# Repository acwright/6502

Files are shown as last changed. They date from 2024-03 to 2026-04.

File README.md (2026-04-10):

ac6502
======

## A 65C02 Based 8-Bit Retro Computer Project

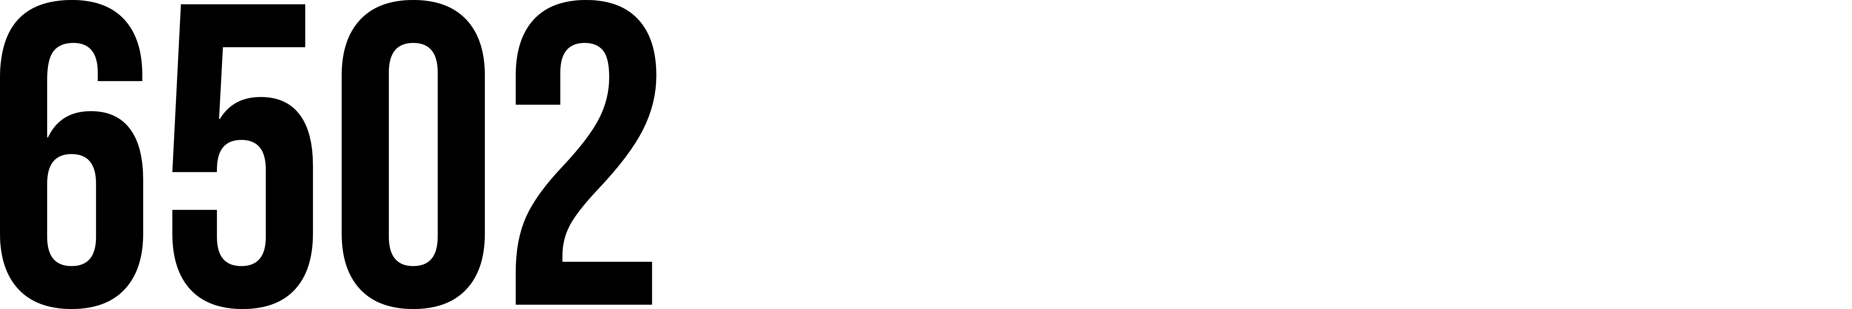
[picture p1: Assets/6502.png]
The ac6502 Project

*Shown above is "The VCS" from the ac6502 project. (AI used to clean up photo background. Computer, keyboard, monitor, and OS screenshot are very real!)*

---

## Table of Contents

- [Overview](#overview)
- [Target Audience](#target-audience)
- [Design Philosophy](#design-philosophy)
- [Computer Systems](#computer-systems)
  - [The COB (Computer on a Backplane)](#the-cob-computer-on-a-backplane)
  - [The DEV (Development Environment Vehicle)](#the-dev-development-environment-vehicle)
  - [The VCS (Video Computer System)](#the-vcs-video-computer-system)
- [System Specifications](#system-specifications)
- [Board Compatibility Matrix](#board-compatibility-matrix)
- [Architecture Overview](#architecture-overview)
- [Hardware](#hardware)
  - [Boards](#boards)
  - [Cards](#cards)
  - [Helpers](#helpers)
  - [Carts](#carts)
- [Firmware](#firmware)
- [Software & Related Projects](#software--related-projects)
- [CAD](#cad)
- [Production](#production)
- [Schematics](#schematics)
- [Libraries](#libraries)
- [Development Workflow](#development-workflow)
- [Contributing](#contributing)
- [Licensing](#licensing)

---

## Overview

This project aims to create multiple retro-style 8-bit computers based on the 65C02 microprocessor. The project is centered around a number of custom-designed PCBs that can be combined in various configurations to create different computer systems based on a common [memory map](./Assets/Documents/Memory%20Map/Memory%20Map.pdf). The designs are inspired by classic 8-bit computers such as the KIM-1, Commodore 64, and Apple II, but with modern enhancements and flexibility.

The project is designed using **KiCad 7.0+** for PCB design and is **open-source** under the CERN Open Hardware Licence Version 2 - Permissive, allowing enthusiasts to contribute and modify the designs freely. The boards are manufactured by **JLCPCB** and use a combination of surface-mount and through-hole components for optimal assembly flexibility.

### Key Features

- **Modular Design**: Mix and match boards, cards, and helpers to create custom configurations
- **Multiple System Types**: Build a desktop computer (COB), development emulator (DEV), or gaming console (VCS)
- **Common Memory Map**: All systems share a consistent memory architecture for software compatibility
- **Modern Manufacturing**: Optimized for JLCPCB's assembly services with production-ready files included
- **Open-Source Hardware**: Complete KiCad schematics, PCB layouts, and 3D models available
- **Extensive Firmware**: PlatformIO-based firmware for microcontrollers with networking, USB, and storage support
- **Flexible I/O**: Support for PS/2 keyboards, joysticks, serial terminals, video output (composite/VGA), and more

---

## Target Audience

This project is designed for:

- **Retro Computing Enthusiasts**: Those who appreciate classic 8-bit computer architecture and want to build modern replicas
- **Hobbyists & Makers**: Electronics enthusiasts interested in hands-on PCB assembly and microcontroller programming
- **Educators**: Teachers and students learning about computer architecture, digital logic, and embedded systems
- **Game Developers**: Retro game developers seeking a flexible platform for 8-bit game development
- **Hardware Hackers**: Engineers wanting to experiment with custom peripherals and system extensions
- **Open-Source Contributors**: Developers interested in contributing to an active hardware/software project

**Skill Level**: Intermediate to advanced electronics knowledge recommended. Basic soldering skills, familiarity with microcontroller programming, and understanding of digital logic are helpful but not strictly required for simple builds.

---

## Design Philosophy

The ac6502 project is guided by several core principles:

### 1. **Modularity & Flexibility**
Rather than designing monolithic systems, the project uses interchangeable boards, cards, and helpers that can be combined in different ways. This allows a single set of PCBs to create vastly different computer systems.

### 2. **Modern Manufacturing Meets Retro Design**
While the systems are inspired by 1970s-1980s computers like the KIM-1 and Commodore 64, they leverage modern PCB manufacturing capabilities (SMD components, JLCPCB assembly) and contemporary components (Teensy microcontrollers, Pi Pico, modern VIAs).

### 3. **Common Architecture**
All systems share a common memory map and bus structure. This ensures that software written for one system can often run on another with minimal modifications, and peripherals remain compatible across configurations.

### 4. **Open-Source Everything**
Complete transparency: all schematics, PCB layouts, 3D models, firmware source code, and production files are available under permissive open-source licenses. The community can learn from, modify, and improve any aspect of the project.

### 5. **Real Hardware + Emulation**
The project supports both real 65C02 hardware and accurate cycle-by-cycle emulation (via Teensy 4.1 + vrEmu6502). This provides flexibility for software development and testing without requiring physical chips.

### 6. **Educational Focus**
Documentation, schematics, and code are written with clarity in mind. The project serves as a learning platform for understanding computer architecture, digital design, and embedded programming.

---

## Computer Systems

The project supports the creation of several different computer systems, each optimized for different use cases. All systems share a common memory map and bus architecture, ensuring software compatibility where applicable.

### The COB (Computer on a Backplane)

**Type:** Full-featured desktop computer  
**Complexity:** Advanced  
**Best For:** Enthusiasts wanting a complete modular 8-bit system

The COB

The COB is the most versatile and expandable system configuration, featuring a backplane architecture that allows multiple peripheral cards to be added or swapped. This design provides maximum flexibility for experimentation and expansion.

**Required Components:**
  * 1x Backplane (provides card slot interconnection)
  * 1x Backplane Pro (enhanced backplane with clock/reset/power)
  * 1x Backplane Helper (adds 2 additional card slots)
  * 1x CPU Card (65C02)
  * 1x Memory Card (32KB RAM + 32KB ROM with address decoding)
  * 1x Video Card (composite via TMS9918A) or 1x VGA Card (VGA via Pico9918)
  * 1x Sound Card (ARMSID audio module)
  * 1x Storage Card (CompactFlash)
  * 1x Serial Card (65C51 ACIA) or 1x Serial Card Pro (enhanced serial)
  * 1x RAM Card (512KB banked RAM)
  * 1x RTC Card (Real-time clock via DS1511Y)
  * 1x GPIO Card (65C22 VIA for I/O)
    * 1x Keyboard Encoder Helper (ATmega1284p) or 1x PS2 Helper (ATmega328p)

**Key Features:**
- Real 65C02 CPU running at 1 Mhz clock speed
- Up to 544KB total RAM (32KB base + 512KB banked)
- Multiple video output options (composite or VGA)
- Persistent storage via CompactFlash or SD card
- Real-time clock for timestamped operations
- Serial terminal connectivity

---

### The DEV (Development Environment Vehicle)

**Type:** Emulation-based development system  
**Complexity:** Intermediate  
**Best For:** Software developers and debugging workflows

The DEV

The DEV replaces the physical 65C02 CPU with a Teensy 4.1 microcontroller running cycle-accurate emulation via [vrEmu6502](https://github.com/visrealm/vrEmu6502).

**Required Components:**
  * 1x Dev Board (Teensy 4.1-based 65C02 emulator)
  * 1x Dev Output Board (2.4" LCD with TMS9918A VDP and SID audio emulation)

**Key Features:**
- Cycle-accurate 65C02 emulation (no physical CPU needed)
- Teensy 4.1 platform (600 MHz ARM Cortex-M7)
- Variable CPU speed
- Ethernet connectivity via QNEthernet library
- Web-based control interface (DB Emulator) accessible at `http://6502.local`
- SD card support for loading ROMs, programs, and saving snapshots
- USB-C keyboard and joystick input (Xbox 360/One controllers)
- Serial terminal interface (115200 baud)
- mDNS discovery
- Real-time clock support
- Hardware buttons (Run/Stop, Step, Reset, Frequency)

**Development Advantages:**
- No need to burn ROMs for testing
- Step through code cycle-by-cycle
- Load programs instantly from SD card or network
- Monitor memory in real-time via web interface
- Snapshot memory (Save memory state to SD card)

**See Also:** [Firmware/DB Emulator/README.md](./Firmware/DB%20Emulator/README.md) for detailed setup instructions.

**IMPORTANT:**

The DEV does not output bus compatible signals (or any signals) for the ac6502 backplane system with the current firmware and instead relies entirely on emulation. There is a bus connector and a card slot available on the Dev Board along with level shifters for all signals (see schematic). These are up to end-user to implement if you want to try to talk to real hardware using the bus connections. In past versions of the firmware (see commit history) I have worked with real hardware and it does work so give it try if you would like!

---

### The VCS (Video Computer System)

**Type:** Retro gaming console  
**Complexity:** Intermediate  
**Best For:** Retro game development and gaming

The VCS

A game-focused configuration designed for playing and developing retro-style games. Features cartridge-based ROM loading, multiple input options, and dedicated video/audio output.

**Required Components:**
  * 1x Main Board (65C02 CPU + 32KB RAM + 32KB ROM)
  * 1x Input Board (Matrix keyboard, PS/2 keyboard, controller ports)
  * 1x Output Board (VGA video via Pico9918 + ARMSID audio)
  * 1x ROM Cart (cartridge for game ROM images)

**Key Features:**
- Real 65C02 CPU running at 1 Mhz clock speed
- Cartridge-based game loading (swappable ROM carts)
- Multiple input options:
  - Matrix keyboard
  - PS/2 keyboard
  - Atari 2600 compatible joysticks (via port header, Keyboard Helper or Joystick Helper)
- VGA video output (via Pico9918)
- Audio output via ARMSID

**Typical Use Cases:**
- Playing homebrew 8-bit games
- Developing retro-style games
- Arcade-style gaming experiences
- Educational game programming

---

## System Specifications

Detailed specifications for each system configuration:

| Specification | COB | DEV | VCS |
|---|-----|-----|-----|
| **CPU** | 65C02 | Teensy 4.1 (ARM Cortex-M7 emulating 65C02) | 65C02 |
| **Clock Speed** | 1 MHz | Emulated: 0 Hz to 1 MHz | 1 MHz |
| **Base RAM** | 32KB | 32KB | 32KB |
| **Banked RAM** | 512KB (RAM Card) | 16KB (default), up to 512KB with PSRAM | N/A |
| **Total RAM** | 544KB | 48KB (default), up to 544KB with PSRAM | 32KB |
| **ROM** | 32KB (Memory Card) | 32KB | 32KB / 16KB (ROM Cart, swappable) |
| **Video Output** | Composite (TMS9918A) or VGA (Pico9918) | 2.4" LCD (VT-AC) | VGA (Pico9918) |
| **Video Resolution** | 256×192 (TMS9918A) or 640×480 VGA | 640×480 VGA or 320×240 LCD | 640×480 VGA |
| **Audio** | ARMSID | SID emulation | ARMSID |
| **Storage** | CompactFlash | SD card (onboard Teensy 4.1) | ROM cartridges |
| **Storage Capacity** | Up to 1MB (CF) | Up to 32GB (SD) | 16KB per cartridge** |
| **Serial I/O** | 65C51 ACIA (RS-232) | USB serial (115200 baud) | N/A |
| **Network** | N/A | Ethernet (10/100 Mbps) | N/A |
| **GPIO Ports** | GPIO Card (Keyboard / Joystick) | USB (Keyboard / Joystick) | Input Board (Keyboard / Joystick) |
| **Input Methods** | PS/2 keyboard or matrix keyboard, joysticks | USB keyboard, USB joystick | PS/2 keyboard or matrix keyboard, joysticks |
| **Real-time Clock** | DS1511Y (Y2K compliant) | Teensy TimeLib software RTC | N/A |
| **Expansion Slots** | 9 slots (12 available with full backplane configuration) | N/A | N/A |
| **Power Requirement** | 5V DC, 2-3A | 5V DC, 2A | 5V DC, 1-2A |
| **Board Count** | 12+ boards/cards | 2 boards | 3 boards |
| **Complexity** | Advanced | Intermediate | Intermediate |

**Legend:**
- `*` = UNTESTED component or configuration
- `**` = Banked cartridge could be designed to allow for more cartridge capacity
- `N/A` = Not applicable or not available for this configuration

---

## Board Compatibility Matrix

This matrix shows which boards, cards, and helpers are compatible with each system configuration. Use this as a guide when planning your build.

### Core Compatibility

| Board/Card/Helper | COB | DEV | VCS | Notes |
|---|:---:|:---:|:---:|---|
| **BOARDS** |
| Main Board | ✓ | — | ✓ | Required for COB/VCS (not DEV) |
| Dev Board | — | ✓ | — | DEV system only |
| Dev Output Board | — | ✓ | — | Pairs with Dev Board for TMS9918A VDP and SID audio output |
| Input Board | ○ | — | ✓ | VCS primary; can be used with COB |
| Output Board | ○ | — | ✓ | VCS primary; can be used with COB |
| LCD Board | ○ | — | — | **UNTESTED**; COB optional, VCS optional |
| Backplane | ✓ | — | ○ | COB primary; can be used with VCS |
| Backplane Pro | ✓ | — | — | COB primary (enhanced backplane) |
| **CARDS** |
| Backplane Helper | ✓ | ○ | ○ | Adds card slots |
| CPU Card | ✓ | — | — | COB primary (hosts CPU) |
| CPU Card Pro | ○ | — | — | COB primary; 65816 CPU; **UNTESTED** |
| Memory Card | ✓ | — | — | COB primary (32K RAM + 32K ROM) |
| RAM Card | ✓ | — | ○ | COB optional (512KB banked RAM) |
| RTC Card | ✓ | — | ○ | COB optional (real-time clock) |
| GPIO Card | ✓ | — | — | COB required |
| Serial Card | ✓ | — | ○ | COB communication |
| Serial Card Pro | ✓ | — | ○ | Enhanced serial; COB |
| Video Card | ✓ | — | — | COB option (TMS9918A composite) |
| Video Card Pro | ○ | — | — | COB option; **UNTESTED** |
| VGA Card | ✓ | — | — | COB option (Pico9918 VGA) |
| VGA Card Pro | ○ | — | — | COB option; **UNTESTED** |
| Sound Card | ✓ | — | — | COB (ARMSID) |
| Storage Card | ✓ | — | ○ | COB (CompactFlash) |
| Storage Card Pro | ○ | — | ○ | SD card; **UNTESTED** |
| LCD Card | ○ | — | — | 16×2 LCD Display |
| Blinkenlights Card | ○ | — | ○ | Debug/visual output; any backplane system |
| Prototype Card | ○ | — | ○ | Custom circuits; any backplane system |
| **HELPERS** |
| Keyboard Encoder Helper | ✓ | — | ○ | COB GPIO keyboard input (ATmega1284p) |
| PS2 Helper | ✓ | — | ○ | COB GPIO PS/2 keyboard (ATmega328p) |
| Keyboard Helper | ✓ | — | ○ | COB 64-key matrix + joysticks |
| Keypad Helper | ○ | — | ○ | Keypad input (4×4 + 2×4) |
| Keypad LCD Helper | ○ | — | ○ | Keypad LCD display |
| GPIO Helper | ✓ | — | ○ | 8 buttons + 8 LEDs; testing/debug |
| GPIO Breadboard Helper | ✓ | — | — | Breadboard interface for GPIO |
| Joystick Helper | ✓ | — | ○ | Atari 2600-style joystick |
| Clock Helper | ✓ | — | ✓ | Manual clock control; any real CPU system |
| DB25 Helper | ✓ | — | — | GPIO to DB25 connector |
| Breadboard Helper | ✓ | ✓ | ✓ | Bus to breadboard; prototyping |
| Mega Helper | ✓ | — | — | Arduino Mega 2560 interface |
| VERA Helper | ○ | — | — | VERA module adapter |
| **CARTS** |
| ROM Cart | ✓ | — | ✓ | DEV/VCS game cartridges (16KB ROM) |

**Legend:**
- `✓` = Required or primary use case
- `○` = Optional or compatible but not typical
- `—` = Not applicable or incompatible
- **UNTESTED** = Hardware exists but not yet verified

### Card Slot Requirements

**COB System (9 slots typically used, 12 available):**
- Uses Backplane, Backplane Pro, and Backplane Helper together
- 12 total card slots available in full configuration
- Typical configuration uses 9 slots for: CPU, Memory, Video, Sound, Storage, Serial, RAM, RTC, GPIO cards
- Additional 3 slots available for expansion or future cards

**DEV and VCS Systems:**
- No backplane architecture (fixed board configurations)
- DEV or VCS systems *CAN* however be expanded using backplane boards and cards

---

## Architecture Overview

All ac6502 project systems share a common architecture based on the classic 65C02 microprocessor bus design, with modern enhancements for flexibility and expansion.

### Memory Map

The project uses a standardized memory map across all systems (see [Memory Map.png](./Assets/Documents/Memory%20Map/Memory%20Map.png) for complete details):

```
$0000 ├─────────────────────────────────────┤
      │  Zero Page                          │  256 bytes ($00-$FF)
$0100 ├─────────────────────────────────────┤
      │  Stack                              │  256 bytes ($0100-$01FF)
$0200 ├─────────────────────────────────────┤
      │  Input Buffer                       │  256 bytes ($0200-$02FF)
$0300 ├─────────────────────────────────────┤
      │  KERNAL Variables                   │  256 bytes ($0300-$03FF)
$0400 ├─────────────────────────────────────┤
      │  User Variables                     │  1KB ($0400-$07FF)
$0800 ├─────────────────────────────────────┤
      │  Program RAM                        │  ~30KB ($0800-$7FFF)
      │  General purpose user RAM           │
$8000 ├─────────────────────────────────────┤
      │  8K I/O Space                       │  8 slots × 1KB each
      │  $8000-$83FF: IO 1 (RAM Card)       │
      │  $8400-$87FF: IO 2 (RAM Card)       │
      │  $8800-$8BFF: IO 3 (RTC Card)       │
      │  $8C00-$8FFF: IO 4 (Storage Card)   │
      │  $9000-$93FF: IO 5 (Serial Card)    │
      │  $9400-$97FF: IO 6 (GPIO Card)      │
      │  $9800-$9BFF: IO 7 (Sound Card)     │
      │  $9C00-$9FFF: IO 8 (Video Card)     │
$A000 ├─────────────────────────────────────┤
      │  LO System ROM (KERNAL)             │  8KB ($A000-$BFFF)
      │  Built-in, not replaceable          │
$C000 ├─────────────────────────────────────┤
      │  HI System ROM or Cart ROM          │  ~16KB ($C000-$FFFA)
      │  BASIC/Monitor, or removable cart   │
$FFFA ├─────────────────────────────────────┤
      │  Interrupt Vectors                  │  6 bytes
      │  $FFFA-$FFFB: NMI                   │
      │  $FFFC-$FFFD: RESET                 │
      │  $FFFE-$FFFF: IRQ/BRK               │
      ├─────────────────────────────────────┤
```

**I/O Slots** (8 slots of 1KB each, $8000-$9FFF):
- **IO 1 ($8000-$83FF)**: RAM Card (1KB window into first 256KB bank)
- **IO 2 ($8400-$87FF)**: RAM Card (1KB window into second 256KB bank)
- **IO 3 ($8800-$8BFF)**: RTC Card (DS1511Y)
- **IO 4 ($8C00-$8FFF)**: Storage Card (CompactFlash/SD controller)
- **IO 5 ($9000-$93FF)**: Serial Card (65C51 ACIA)
- **IO 6 ($9400-$97FF)**: GPIO Card (65C22 VIA)
- **IO 7 ($9800-$9BFF)**: Sound Card (ARMSID)
- **IO 8 ($9C00-$9FFF)**: Video Card (TMS9918A or Pico9918)

**Banked RAM** (RAM Card, if installed):
- 512KB total RAM organized as two 256KB banks
- Bank selection via single latch at $83FF or $87FF (write 0-255)
- Writing to latch selects which 1KB window (of 256) appears at IO 1 and IO 2
- IO 1 ($8000-$83FF): 1KB window into first 256KB bank
- IO 2 ($8400-$87FF): 1KB window into second 256KB bank
- Both windows show the same bank number from their respective 256KB regions
- Allows access to full 512KB by switching between 256 different 1KB windows

### Bus Structure

The ac6502 bus includes:
- **16-bit Address Bus** (A0-A15): Addresses up to 64KB memory space
- **8-bit Data Bus** (D0-D7): Bidirectional data transfer
- **Control Signals**:
  - `RW` (Read/Write): Direction of data transfer (1=Read, 0=Write)
  - `PHI2` (Clock): System clock signal (0.5-8 MHz typical)
  - `RESET`: System reset (active low)
  - `IRQ`: Interrupt request (active low)
  - `NMI`: Non-maskable interrupt (active low)
  - `RDY`: Ready signal for clock stretching
  - `SYNC`: Instruction fetch indicator

### Clock & Reset Circuitry

**Clock Generation:**
- Oscillator: Crystal or ceramic resonator (1-8 MHz typical)
- Clock can be:
  - Free-running (normal operation)
  - Single-stepped (via Clock Helper)
  - Variable frequency (firmware in DEV)
- Clock Helper provides:
  - Run/Stop control
  - Single cycle stepping
  - Single instruction stepping

**Reset Circuit:**
- Power-on reset via RC circuit (Main Board or Backplane Pro)
- Manual reset button
- Watchdog timer reset (optional, via RTC Card)

### Interrupt Handling

- **IRQ (Maskable Interrupt)**: Used by serial (65C51), timers (65C22), and other peripherals
- **NMI (Non-Maskable Interrupt)**: Currently unused but can be configured on some cards
- Interrupt vectors stored at `$FFFA-$FFFF` in ROM

### Address Decoding

Each peripheral card uses address decoding logic to respond only to its assigned memory range:
- **I/O Cards**: Use 74HC138 3-to-8 decoder with address lines A15-A10, jumper-selectable for flexibility
- **Main Board & Memory Card**: Use 74HC00 NAND for RAM/ROM chip select
- Jumpers or DIP switches allow I/O address reconfiguration on cards

**Example:** Serial Card (65C51 ACIA)
- Occupies 4 bytes in I/O space ($9000-$9003, IO 5)
- 74HC138 decoder uses A15-A10 to select I/O slot
- Address decoder activates chip enable when A15-A10 match configured slot
- Lower address bits (A1-A0) select specific ACIA registers

---

## Hardware

The [Hardware](./Hardware) folder contains KiCad files for the system's custom-designed PCBs. These are divided into the following categories:

- **Boards**: The main board, development board, backplane boards and other peripheral boards
- **Cards**: Various peripheral cards for plugging into the backplane or card slot(s)
- **Helpers**: Additional boards that provide specific functionalities or interfaces
- **Carts**: Cartridge boards for ROM images

See the [Hardware README](./Hardware/README.md) for detailed technical specifications, pin assignments, and assembly notes.

### Boards

These are the primary system boards that form the foundation of each computer configuration.

#### Backplane

#### Backplane
**Purpose:** Provides 5 card slots for peripheral cards and connects to the Main Board via ribbon cable  
**Key Components:** Card edge connectors (×5), ribbon cable headers   
**Status:** ✓ Tested  

A passive backplane that provides mechanical and electrical connectivity for up to 5 peripheral cards, directly interconnecting the bus signals across all slots.

#### Backplane Pro
**Purpose:** Enhanced backplane with 5 card slots plus integrated clock, reset, and power circuitry  
**Key Components:** Oscillator, reset IC, voltage regulators, card edge connectors (×5)  
**Clock Output:** 1-8 MHz (selectable by swapping oscillator)  
**Power:** 5V input, distributes regulated 5V to cards as needed  
**Status:** ✓ Tested  

An active backplane that not only interconnects cards but also provides centralized clock generation and power management, reducing component count on peripheral cards.

#### Dev Board
**Purpose:** Teensy 4.1-based 65C02 CPU emulator with networking and USB I/O  
**Key Components:** Teensy 4.1 (600 MHz ARM Cortex-M7), Ethernet PHY, SD card slot, USB host  
**Emulation:** Cycle-accurate 65C02 via [vrEmu6502](https://github.com/visrealm/vrEmu6502)  
**Memory:** Up to 32KB base RAM + 32KB banked RAM (default), expandable to 512KB banked RAM with PSRAM  
**Clock Speed:** Variable from very slow to maximum (exceeding real 65C02)  
**Networking:** Ethernet 10/100 Mbps with mDNS (hostname: `6502.local`)  
**Storage:** MicroSD card (up to 32GB)  
**I/O:** USB keyboard, USB joystick (Xbox 360/One), serial (115200 baud)  
**Firmware:** [DB Emulator](./Firmware/DB%20Emulator/) (PlatformIO project)  
**Status:** ✓ Tested  

The Dev Board eliminates the need for a physical 65C02 CPU by providing accurate emulation with enhanced debugging capabilities, network control, and instant program loading.

#### Dev Output Board
**Purpose:** 2.4" LCD display module providing TMS9918A VDP and SID audio emulation for the Dev Board  
**Key Components:** ILI9341 TFT display (320×240), level shifters  
**Display:** 2.4" TFT LCD, 320×240 resolution, 262K colors (256×192 active area with TMS9918A color borders)  
**Protocol:** AV packet stream (4-byte packets at 6 Mbps via hardware UART) from DB Emulator  
**Connection:** SPI interface to Dev Board  
**Firmware:** [DOB Display](./Firmware/DOB%20%20Display/) (PlatformIO project)  
**Audio:** 3-voice SID 6581 synthesis via 8-bit PWM at 44.1 kHz  
**Status:** ✓ Tested 

Provides dedicated video and audio output for the DEV system, emulating the TMS9918A VDP and MOS 6581 SID in real time at ~60 FPS.

#### Input Board
**Purpose:** Unified input board for matrix keyboard, PS/2 keyboard, and joysticks
**Key Components:** 65C22 VIA (Versatile Interface Adapter), ATmega1284p microcontroller
**Inputs:** Matrix keyboard, PS/2 keyboard, and joysticks  
**Interface:** Parallel I/O to ac6502 bus (memory-mapped registers)  
**Firmware:** [KEH Controller](./Firmware/KEH%20Controller/)   
**Status:** ✓ Tested  

Consolidates multiple input devices onto a single board, providing input for gaming and general use.

#### LCD Board
**Purpose:** 320×240 TFT LCD display interfaced via 65C22 VIA  
**Key Components:** ILI9341 TFT controller, 65C22 VIA for I/O  
**Display:** 320×240 resolution  
**Interface:** 65C22 VIA parallel interface (slower than SPI but directly CPU-addressable)  
**Status:** ⚠️ **UNTESTED**  

An experimental board attempting to drive an LCD display directly from 65C02 via VIA. Performance may be limited due to parallel interface overhead.

#### Main Board
**Purpose:** Core board containing 65C02 CPU, RAM, ROM, clock, and reset circuitry  
**Key Components:** 65C02 CPU, 32KB SRAM (62256), 32KB EEPROM (28C256), oscillator, reset IC  
**CPU:** W65C02S or equivalent  
**Clock Speed:** 1-8 MHz (selectable by swapping oscillator)   
**RAM:** 32KB (addresses $0000-$7FFF)  
**ROM:** 32KB (addresses $8000-$FFFF)  
**Bus Connection:** Ribbon cable header for expansion  
**Power:** 5V DC input  
**Status:** ✓ Tested  

The Main Board is a self-contained 6502 computer suitable for standalone use or as the foundation for expanded systems.

#### Output Board
**Purpose:** Combined VGA video output (via Pico9918) and audio output (via ARMSID)  
**Key Components:** Raspberry Pi Pico (Pico9918 firmware), ARMSID module  
**Video:** VGA 640×480 via [Pico9918](https://github.com/visrealm/pico9918)  
**Audio:** ARMSID (SID chip emulation)  
**Interface:** Memory-mapped I/O to ac6502 bus  
**Status:** ✓ Tested  
**Used In:** VCS (primary), DEV (alternative), COB (alternative)

Combines video and audio output on a single board for compact gaming console configurations.

---

### Cards

Peripheral cards plug into backplane slots or directly onto the Main Board via single card slot.

#### Blinkenlights Card
**Purpose:** Visual status LEDs for address, data, and control bus monitoring  
**Key Components:** LEDs (×32+), current-limiting resistors  
**LEDs:** Show address bus (16), data bus (8), control signals (8)  
**Status:** ✓ Tested 

A classic "blinkenlights" panel that visualizes bus activity in real-time, invaluable for debugging and demonstrations.

#### CPU Card
**Purpose:** Hosts a 65C02 CPU in a card form factor for backplane systems  
**Key Components:** W65C02S CPU socket, clock input, bus buffers  
**CPU:** W65C02S (DIP-40 socket)  
**Clock:** Provided by Backplane Pro or external source  
**Status:** ✓ Tested  

Allows the CPU to be installed on a card rather than the main board, enabling CPU upgrades or replacements.

#### CPU Card Pro
**Purpose:** Hosts a 65816 16-bit CPU (backward-compatible with 65C02)  
**Key Components:** W65C816S CPU socket, additional address lines (A16-A23)  
**CPU:** W65C816S (DIP-40 socket)  
**Address Space:** 16MB (24-bit addressing)  
**Status:** ⚠️ **UNTESTED**  

Provides 16-bit CPU capability and extended address space. Requires compatible memory and I/O cards to utilize extended features.

#### GPIO Card
**Purpose:** General-purpose I/O using 65C22 VIA chip  
**Key Components:** 65C22 VIA (Versatile Interface Adapter)  
**I/O Pins:** 20 GPIO pins (2× 8-bit ports + 4 control lines)  
**Address Range:** IO 6 ($9400-$97FF), configurable via jumpers  
**Timers:** 2× 16-bit timers with interrupt capability  
**Shift Register:** Serial I/O support  
**Status:** ✓ Tested  

The GPIO Card is highly versatile, supporting keyboards, displays, custom I/O devices, and timing-critical applications.

#### LCD Card
**Purpose:** 16×2 character LCD display via 65C22 VIA  
**Key Components:** 65C22 VIA, 16×2 LCD module (HD44780-compatible)  
**Display:** 16 characters × 2 lines  
**Interface:** 65C22 VIA parallel interface (4-bit or 8-bit mode)  
**Address Range:** IO 6 ($9400-$97FF), shared with GPIO Card  
**Status:** ✓ Tested  

Provides a simple text display for system messages, debugging output, or simple user interfaces.

#### Memory Card
**Purpose:** 32KB RAM + 32KB ROM with address decoding logic  
**Key Components:** 32KB SRAM (62256), 32KB EEPROM (28C256), address decoder logic  
**RAM:** 32KB at $0000-$7FFF  
**ROM:** 32KB at $8000-$FFFF  
**Address Decoding:** 74-series logic (74HC00)  
**Status:** ✓ Tested  

Essential card providing memory for COB systems where the CPU Card is used instead of the Main Board.

#### Prototype Card
**Purpose:** Blank prototyping area for custom circuits  
**Key Components:** Onboard small breadboard, bus access headers  
**Prototyping Area:** Integrated breadboard  
**Bus Access:** Full address, data, and control bus available  
**Status:** ✓ Tested (verified bus connectivity) 

Allows experimentation with custom circuits while maintaining access to the system bus.

#### RAM Card
**Purpose:** 512KB banked RAM expansion  
**Key Components:** SRAM chips (512KB total), banking logic, bank select latch  
**Capacity:** 512KB organized as two 256KB banks, each with 256× 1KB windows  
**Banking:** Single latch at $83FF or $87FF selects 1KB window (0-255) for both IO slots  
**Bank Windows:** IO 1 ($8000-$83FF) and IO 2 ($8400-$87FF)  
**Status:** ✓ Tested 

Dramatically expands memory capacity beyond the 65C02's 64KB address space. The single latch controls which 1KB window appears at both IO 1 (first 256KB) and IO 2 (second 256KB), allowing efficient access to the full 512KB.

#### RTC Card
**Purpose:** Real-time clock with battery backup  
**Key Components:** Dallas DS1511Y (RTC with integrated SRAM and battery)  
**Clock:** Year/month/day/hour/minute/second with Y2K support  
**Battery Backup:** Lithium coin cell (maintains time during power-off)  
**SRAM:** 256 bytes battery-backed SRAM  
**Alarm:** Programmable alarm interrupt  
**Address Range:** IO 3 ($8800-$8BFF)  
**Status:** ✓ Tested 

Provides persistent timekeeping for timestamps, scheduling, and time-based applications.

#### Serial Card
**Purpose:** RS-232 serial communication via 65C51 ACIA  
**Key Components:** 65C51 ACIA (Asynchronous Communications Interface Adapter), MAX232 level shifter  
**Interface:** RS-232 via DB9 connector  
**Baud Rate:** 50 - 19200 bps (configurable via software)  
**Address Range:** IO 5 ($9000-$93FF)  
**Status:** ✓ Tested  

Essential for terminal communication, program loading, and interfacing with modern PCs.

#### Serial Card Pro
**Purpose:** Enhanced serial card with full modem control signals  
**Key Components:** 65C51 ACIA, MAX232 (×2) for RS-232 level conversion  
**Features:** Same as Serial Card plus DTR, DCD, and DSR modem control signals via second MAX232  
**Status:** ✓ Tested  

An improved version of the Serial Card with full modem control signal support for advanced serial communications.

#### Sound Card
**Purpose:** Audio output via ARMSID SID chip emulator  
**Key Components:** ARMSID module (ARM-based SID emulation)  
**Audio:** 3-voice synthesizer (SID chip emulation)  
**Output:** RCA jack (line level)  
**Interface:** Memory-mapped I/O (SID-compatible registers)  
**Address Range:** IO 7 ($9800-$9BFF)  
**Status:** ✓ Tested  

Provides classic SID chip audio capabilities for games and music applications.

#### Storage Card
**Purpose:** CompactFlash storage interface  
**Key Components:** CompactFlash socket, IDE interface logic  
**Capacity:** Up to 128GB (CF card dependent)  
**Interface:** IDE protocol (CF cards are IDE-compatible)  
**Address Range:** IO 4 ($8C00-$8FFF)  
**File System:** Raw sectors or FAT16/FAT32 with appropriate drivers  
**Status:** ✓ Tested 

Provides persistent storage for programs, data, and disk images. CompactFlash cards are rugged and widely available.

#### Storage Card Pro
**Purpose:** Modern storage via SD card, 16MB Flash, and SPI interface  
**Key Components:** SD card socket, SPI flash (16MB), SPI controller  
**SD Card:** Up to 32GB (SDHC)  
**Flash:** 16MB onboard SPI flash  
**Interface:** SPI protocol  
**Address Range:** IO 4 ($8C00-$8FFF) 
**Status:** ⚠️ **UNTESTED**  

Provides modern SD card storage plus onboard flash. More complex software required but offers higher capacities.

#### VGA Card
**Purpose:** VGA video output via Pico9918  
**Key Components:** Raspberry Pi Pico running [Pico9918](https://github.com/visrealm/pico9918) firmware  
**Video:** VGA 640×480 @ 60Hz  
**Graphics:**  
 TMS9918A-compatible modes (Pico9918 emulates classic video chip)  
**Colors:** 16-color palette (TMS9918A modes)  
**Interface:** Memory-mapped I/O (TMS9918A-compatible registers)  
**Address Range:** IO 8 ($9C00-$9FFF)  
**Status:** ✓ Tested  

Provides VGA output with classic TMS9918A graphics modes, ideal for retro gaming and graphics applications.

#### VGA Card Pro
**Purpose:** Custom programmable VGA output using Pi Pico with custom firmware  
**Key Components:** Raspberry Pi Pico, resistor DAC, VGA connector  
**Video:** VGA 640×480 (or custom resolutions)  
**Graphics:** Fully programmable (custom framebuffer modes possible)  
**Interface:** Memory-mapped I/O  
**Status:** ⚠️ **UNTESTED**  

An experimental card offering fully customizable VGA output modes. Requires custom firmware development.

#### Video Card
**Purpose:** Composite video output via TMS9918A chip  
**Key Components:** TMS9918A Video Display Processor (VDP), video RAM (16KB)  
**Video:** Composite video output (NTSC or PAL)  
**Resolution:** 256×192 pixels  
**Colors:** 16-color palette  
**Sprites:** 32 sprites (8×8 or 8×16 pixels)  
**Interface:** Memory-mapped I/O (2-byte register interface)  
**Address Range:** IO 8 ($9C00-$9FFF)  
**Status:** ✓ Tested  

Classic retro graphics using the authentic TMS9918A chip from 1970s/80s computers and consoles.

#### Video Card Pro
**Purpose:** Enhanced composite video via ATmega1284p microcontroller  
**Key Components:** ATmega1284p, video DAC, composite video output  
**Video:** Color composite video  
**Features:** Microcontroller-generated video (programmable graphics modes)  
**Status:** ⚠️ **UNTESTED**  

Attempts to generate composite video using a microcontroller rather than dedicated video chip. Flexibility vs. complexity tradeoff.

---

### Helpers

Helper boards provide specialized interfaces, connectors, or functionality that complements the main boards and cards.

#### Backplane Helper
**Purpose:** Adds 2 additional card slots to existing backplane  
**Key Components:** Card edge connectors (×2), ribbon cable headers  
**Slots:** +2 expansion slots  
**Status:** ✓ Tested  

Increases expansion capability for systems requiring more peripherals.

#### Breadboard Helper
**Purpose:** Interfaces ac6502 bus to standard breadboard  
**Key Components:** Ribbon cable header, breadboard-compatible headers  
**Pinout:** Full address, data, and control bus broken out  
**Status:** ✓ Tested  

Essential for prototyping custom circuits and testing ideas before committing to PCB designs.

#### Clock Helper
**Purpose:** Manual clock control for debugging and single-stepping  
**Key Components:** Clock manipulation buttons  
**Modes:**  
  - Free-running (normal operation)  
  - Single cycle step (advance one clock cycle per button press)  
  - Single instruction step (advance one full instruction)  
**Status:** ✓ Tested  

Invaluable debugging tool allowing cycle-by-cycle or instruction-by-instruction execution.

#### DB25 Helper
**Purpose:** Interfaces GPIO Card to DB25 connector  
**Key Components:** DB25 connector, header pins  
**Pinout:** Maps VIA ports to standard DB25 pinout  
**Status:** ✓ Tested  

Provides DB25 connectivity for GPIO applications.

#### GPIO Helper
**Purpose:** 8 buttons + 8 LEDs for user I/O and testing  
**Key Components:** Tactile switches (×8), LEDs (×8), current-limiting resistors  
**Inputs:** 8 debounced buttons  
**Outputs:** 8 indicator LEDs  
**Interface:** Connects to GPIO Card (65C22 VIA)  
**Status:** ✓ Tested  

Simple I/O for testing, debugging, or basic user interaction.

#### GPIO Breadboard Helper
**Purpose:** Interfaces GPIO Card to breadboard  
**Key Components:** Header pins  
**Pinout:** All GPIO pins broken out to breadboard-compatible headers  
**Status:** ✓ Tested  

Allows quick breadboard prototyping of GPIO-based circuits.

#### Joystick Helper
**Purpose:** Atari 2600-style joystick interface  
**Key Components:** DB9 connector, pull-up resistors  
**Compatibility:** Atari 2600, Commodore 64, Amiga joysticks  
**Inputs:** Up, down, left, right, fire button (plus extra buttons) 
**Interface:** Connects to GPIO Card  
**Status:** ✓ Tested  

Classic digital joystick interface for retro gaming.

#### Keyboard Helper
**Purpose:** 64-key matrix keyboard + dual joystick ports  
**Key Components:** Key switches (×64), diodes, DB9 connectors (×2)  
**Keyboard:** 8×8 matrix (64 keys total)  
**Joysticks:** 2× Atari-style joystick ports  
**Interface:** Connects to GPIO Card (65C22 VIA)  
**Scanning:** Matrix scanning via VIA ports  
**Status:** ✓ Tested  

Full keyboard input plus joystick support for gaming and general computing.

#### Keyboard Encoder Helper
**Purpose:** Translates keyboard matrix and PS/2 keyboard to ASCII  
**Key Components:** ATmega1284p microcontroller, PS/2 connector  
**Inputs:** PS/2 keyboard OR 8×8 keyboard matrix (Keyboard Helper)  
**Output:** ASCII characters via 65C22 VIA interface  
**Firmware:** [KEH Controller](./Firmware/KEH%20Controller/)  
**Features:**  
  - Dual input support (PS/2 + matrix simultaneously)  
  - ASCII conversion (0x00-0xFF including extended characters)  
  - Full modifier key support (Shift, Ctrl, Alt, Fn)  
  - Function keys F1-F12  
  - Circular buffer (prevents data loss)  
**Status:** ✓ Tested  

Provides intelligent keyboard handling, converting raw scancodes to ASCII for easier software development.

#### Keypad Helper
**Purpose:** 4×6 keypad
**Key Components:** Matrix keypad (4×6)  
**Keys:** 0-9, A-F (hex), plus 8 function keys  
**Interface:** Connects to GPIO Card (matrix scanning)  
**Status:** ✓ Tested  

Essential for KIM-1-style hexadecimal data entry and system control.

#### Keypad LCD Helper
**Purpose:** LCD display designed to pair with Keypad Helper  
**Key Components:** LCD module (HD44780-compatible)  
**Display:** 16×2 characters (typical) or 20×4  
**Interface:** Connects to GPIO Card via parallel interface  
**Status:** ✓ Tested  

Displays output for KIM-1-style system (addresses, data, messages).

#### Mega Helper
**Purpose:** Interfaces Arduino Mega 2560 R3 to ac6502 bus  
**Key Components:** Headers for Arduino Mega  
**Microcontroller:** Arduino Mega 2560 R3 (user-supplied)  
**Use Cases:**  
  - 65C02 bus monitoring
  - Custom peripherals programmed in Arduino IDE  
  - I/O expansion  
  - Sensor interfaces  
  - LCD controllers  
**Interface:** Connects to ac6502 bus  
**Status:** ✓ Tested  

Leverages the Arduino ecosystem for easy peripheral development.

#### PS2 Helper
**Purpose:** PS/2 keyboard interface with ASCII conversion  
**Key Components:** ATmega328p microcontroller, PS/2 connector  
**Input:** PS/2 keyboard  
**Output:** ASCII characters via 65C22 VIA or matrix emulation  
**Firmware:** [PS2 Keyboard Controller](./Firmware/PS2%20Keyboard%20Controller/)  
**Features:**  
  - PS/2 protocol decoding  
  - ASCII conversion  
  - Extended scancode support  
  - Function key emulation (F1-F10 via Fn + numbers)  
**Status:** ✓ Tested  

Simpler alternative to Keyboard Encoder Helper when only PS/2 input is needed.

#### VERA Helper
**Purpose:** Adapts the VERA module to ac6502 bus  
**Key Components:** VERA module (from Commander X16 project), level shifters, bus interface  
**Video:** VERA capabilities (see [Commander X16 VERA](https://github.com/commanderx16/x16-docs/blob/master/VERA%20Programmer's%20Reference.md))  
**Interface:** Memory-mapped I/O (VERA register interface)  
**Status:** ✓ Tested

Adapter for the powerful VERA module from the Commander X16 project.

---

### Carts

#### ROM Cart
**Purpose:** Swappable ROM cartridge for VCS gaming system  
**Key Components:** EEPROM or Flash ROM (up to 16KB), edge connector  
**Capacity:** 16KB (addresses $C000-$FFFF when inserted)  
**Programming:** Requires TL866 or similar EEPROM programmer (for 28C256/27C256 chips), or in-system programming (if flash-based)  
**Status:** ✓ Tested  

Allows game cartridge-based operation similar to classic game consoles.

---

## Firmware

The [Firmware](./Firmware) folder contains source code for firmware running on various microcontrollers used in the project (Teensy 4.1, ATmega328p, ATmega1284p, ATTiny85). Firmware is written in C/C++ and is developed using **PlatformIO**.

See the [Firmware README](./Firmware/README.md) for detailed information on building and flashing firmware.

### Firmware Projects by System

| Firmware Project | Target Hardware | Microcontroller | System | Description |
|---|---|---|---|---|
| [DB Emulator](./Firmware/DB%20Emulator/) | Dev Board | Teensy 4.1 | DEV | 65C02 emulator with networking, USB I/O, and web control |
| [DOB Display](./Firmware/DOB%20%20Display/) | Dev Output Board | Teensy 4.0 | DEV | TMS9918A VDP + SID audio emulation on ILI9341 LCD |
| [KEH Controller](./Firmware/KEH%20Controller/) | Keyboard Encoder Helper, Input Board Rev 1.0 | ATmega1284p | COB/VCS | Dual keyboard (PS/2 + matrix) to ASCII converter |
| [PS2 Keyboard Controller](./Firmware/PS2%20Keyboard%20Controller/) | PS2 Helper | ATmega328p | COB | PS/2 keyboard to matrix interface |
| [STP Controller](./Firmware/STP%20Controller/) | Storage Card Pro | ATmega328p | COB/VCS | SD card and SPI flash storage controller |

### Key Firmware Features

**DB Emulator (Dev Board):**
- Cycle-accurate 65C02 emulation via [vrEmu6502](https://github.com/visrealm/vrEmu6502)
- Ethernet connectivity with mDNS (`6502.local`)
- Embedded web server with REST API and web application
- SD card support for ROM/program loading
- USB keyboard and joystick input (Xbox controllers)
- Variable CPU speed control
- Memory snapshot save
- Serial terminal interface (115200 baud)
- Real-time clock support

**DOB Display (Dev Output Board):**
- TMS9918A VDP emulation (Graphics I/II, Text, and Multicolor modes)
- SID 6581 3-voice audio synthesis (triangle, sawtooth, pulse, noise + full ADSR)
- 320×240 color LCD display (2.4" ILI9341) with 256×192 active area and TMS9918A color borders
- ~60 FPS rendering from VRAM state
- AV packet protocol at 6 Mbps via hardware UART from DB Emulator

**KEH Controller (Keyboard Encoder Helper):**
- Dual input support (PS/2 + keyboard matrix simultaneously)
- ASCII conversion with extended character set (0x00-0xFF)
- Full modifier key support (Shift, Ctrl, Alt, Fn)
- Function keys F1-F12
- Circular buffering to prevent key loss

**PS2 Keyboard Controller (PS2 Helper):**
- PS/2 protocol decoding with parity checking
- MT8808 crosspoint switch control for matrix emulation
- Extended scancode support
- Function key emulation (Fn + numbers)

### Development Environment

**Prerequisites:**
- [PlatformIO Core](https://platformio.org/install/cli) or [PlatformIO IDE](https://platformio.org/platformio-ide) (VS Code extension)
- Python 3.7+ (bundled with PlatformIO)
- USB cable for programming

**Building Firmware:**
```bash
cd Firmware/<project_name>
pio run                 # Build
pio run --target upload # Build and upload
```

**Using VS Code:**
1. Open folder in VS Code (with PlatformIO extension installed)
2. PlatformIO: Build (Ctrl/Cmd+Alt+B)
3. PlatformIO: Upload (Ctrl/Cmd+Alt+U)

**Serial Monitoring:**
```bash
pio device monitor    # PlatformIO serial monitor
```

See individual firmware project README files for specific build instructions and configuration options.

---

## Software & Related Projects

The ac6502 project has several companion repositories containing software that runs on the 65C02 systems, as well as development tools.

### Emulator

**[6502-EMULATOR](https://github.com/acwright/6502-EMULATOR)**
- Software emulator for the ac6502 computer systems
- Allows running and testing 65C02 programs without physical hardware
- Useful for software development and debugging

### Assembly Code & BIOS

The following repositories contain 65C02 assembly code that runs on the hardware:

**[6502-ASM](https://github.com/acwright/6502-ASM)**
- General 65C02 assembly code examples and utilities
- Sample programs demonstrating hardware features
- Library routines for common tasks

**[6502-BIOS](https://github.com/acwright/6502-COBBIOS)**
- BIOS (Basic Input/Output System) for all systems
- Low-level hardware initialization and I/O routines
- System ROM code providing BASIC and machine code monitor

**[6502-NOP](https://github.com/acwright/6502-NOP)**
- NOP (No Operation) test program
- Minimal ROM code for hardware testing
- Useful for verifying basic CPU and memory operation

**[6502-WOZMON](https://github.com/acwright/6502-WOZMON)**
- Woz Monitor (Apple I monitor program)
- Classic machine language monitor by Steve Wozniak
- Adapted for the ac6502 project hardware using the Serial Card

### Using the Software

To use these programs on your ac6502 hardware:
1. Clone the desired repository
2. Assemble the code using a 65C02 assembler (ca65, vasm, or similar)
3. Program the resulting binary to EEPROM using TL866 or similar programmer
4. Install the EEPROM in your ac6502 system
5. Power on and test

See individual repository README files for specific build and usage instructions.

---

## CAD

The [CAD](./CAD) folder contains mechanical designs for the project including 3D models and enclosure designs.

**Contents:**
- **Bases/**: 3D models of complete system assemblies (COB, DEV, VCS)
- **Card/**: 3D models of individual card designs
- **Enclosures/**: Custom enclosure designs for various systems
- **Tops/**: Top panel/cover designs

**File Formats:**
- STL files (for 3D printing)
- STEP files (for CAD editing)

**Use Cases:**
- 3D printing custom enclosures
- Visualizing system assembly
- Creating custom mounting solutions
- Designing front panels and bezels

See the [CAD README](./CAD/README.md) for details on using and modifying CAD files.

---

## Production

The [Production](./Production) folder contains JLCPCB-ready production files for manufacturing PCBs, including Gerber files, BOMs (Bill of Materials), and assembly instructions.

### Ordering from JLCPCB

1. **Navigate to desired board folder** in [Production/](./Production)
2. **Locate Gerber files** (usually in a ZIP archive named `<BoardName>_Gerber.zip`)
3. **Go to [JLCPCB.com](https://jlcpcb.com/)** and create account (if needed)
4. **Upload Gerber ZIP file** using "Add gerber file" button
5. **Configure PCB options:**
   - Layers: 2 or 4 (check board specifications)
   - Thickness: 1.6mm (typical)
   - Color: Your choice
   - Surface Finish: HASL (economical) or ENIG (better for edge connectors)
   - Remove Order Number: Optional
6. **Select SMD Assembly** (if desired):
   - Enable PCB Assembly option
   - Upload BOM and Pick-and-Place (CPL) files from Production folder
   - Review component availability (JLCPCB may not stock all parts)
   - Confirm component placement in preview
7. **Review and order:**
   - Verify quantities (5 or 10 boards minimum typically)
   - Add to cart and checkout
   - Manufacturing time: typically 2-7 days + shipping

### Production Files Included

For each board/card/helper:
- **Gerber files**: PCB manufacturing data (layers, drill files, solder mask, silkscreen)
- **BOM (Bill of Materials)**: CSV file with component list and JLCPCB part numbers
- **CPL (Component Placement List)**: Pick-and-place file for SMD assembly
- **Design rules**: KiCad design rule (.kicad_dru) file optimized for JLCPCB

See the [Production README](./Production/README.md) for detailed ordering guides and quality control checklists.

---

## Schematics

The [Schematics](./Schematics) folder contains schematic diagrams for all PCBs in the project. Schematics are created using **KiCad 7.0+** and provide detailed component information and electrical connections.

**Contents:**
- Complete schematics for every board, card, and helper
- PDF exports (for easy viewing without KiCad)

**Schematic Conventions:**
- Power nets: VCC/+5V (positive rail), GND (ground)
- Signal naming: descriptive labels (A0-A15 for address bus, D0-D7 for data bus)
- Component references: Standard prefixes (U=IC, R=resistor, C=capacitor, D=diode, J=connector)
- Component values: Marked on schematic (resistor ohms, capacitor farads)

See the [Schematics README](./Schematics/README.md) for details on navigating and understanding schematics.

---

## Libraries

The [Libraries](./Libraries) folder contains KiCad symbol libraries, footprint libraries, and 3D models used throughout the project.

**Contents:**
- **6502 Parts.kicad_sym**: Symbol library with ac6502-specific components
- **6502 Parts.pretty/=**: Footprint library (PCB footprints)
- **6502 Logos.pretty/**: Logo footprints for PCB silkscreen
- **A.C. Wright Logo.pretty/**: A.C. Wright Design logo footprints
- **Models/**: 3D STEP models for components (see [Models README](./Libraries/Models/README.md))

**Using Libraries in KiCad Projects:**
1. Open KiCad project
2. Go to Preferences → Manage Symbol Libraries / Manage Footprint Libraries
3. Add library paths pointing to this folder
4. Libraries will appear in symbol/footprint choosers

**Adding New Components:**
1. Open appropriate library in KiCad Library Editor
2. Create new symbol/footprint following existing conventions
3. Save and commit changes (if contributing back to project)

See the [Libraries README](./Libraries/README.md) for detailed library usage instructions.

---

## Development Workflow

Contributing to or extending the ac6502 project follows these general workflows.

### Modifying Existing Boards

1. **Clone/Fork Repository**:
   ```bash
   git clone https://github.com/acwright/6502.git
   cd 6502
   ```

2. **Open Hardware Design** in KiCad 7.0+:
   ```
   Hardware/<BoardName>/Rev X.X/<BoardName>.kicad_pro
   ```

3. **Make Schematic Changes**:
   - Edit schematic in KiCad Schematic Editor
   - Update component values, add/remove components, modify connections
   - Run Electrical Rules Check (ERC) to verify

4. **Update PCB Layout**:
   - Update PCB from schematic (Tools → Update PCB from Schematic)
   - Adjust component placement and routing as needed
   - Run Design Rules Check (DRC) to verify JLCPCB compatibility
   - Use design rules file from Production folder if available

5. **Generate Production Files**:
   - Production files are generated using [Fabrication-Toolkit](https://github.com/bennymeg/Fabrication-Toolkit)
   - This KiCad plugin automates generation of Gerbers, drill files, BOMs, and pick-and-place files for JLCPCB
   - Install the plugin and run it from KiCad to generate all required manufacturing files
   - Output files should be moved to approprite folder in Production folder

6. **Test Design**:
   - Order prototype from JLCPCB
   - Assemble and test thoroughly
   - Document findings

7. **Commit Changes**:
   ```bash
   git add Hardware/<BoardName>/
   git commit -m "Description of changes"
   git push
   ```

### Designing New Cards/Helpers

1. **Start with Template**:
   - Use existing card design as template (copy folder structure)
   - OR use blank template from Templates/ folder

2. **Define Requirements**:
   - What functionality does the card provide?
   - What I/O address range will it occupy?
   - What connectors are needed?
   - Power consumption estimate

3. **Schematic Design**:
   - Create multi-sheet schematic if complex
   - Use ac6502 Parts library for common components
   - Include address decoding logic
   - Add bus buffers if driving bus signals
   - Follow existing card conventions for connector pinouts

4. **PCB Layout**:
   - Match card edge connector footprint to backplane
   - Place connectors for easy access
   - Route power planes (4-layer board) or wide power traces (2-layer)
   - Maintain signal integrity (short traces for high-speed signals)
   - Add mounting holes (if applicable)

5. **Verify Design Rules**:
   - Run DRC with JLCPCB design rules
   - Check trace widths (minimum 0.15mm for outer layers)
   - Check clearances (minimum 0.15mm)
   - Verify drill sizes (minimum 0.3mm)

6. **Documentation**:
   - Update README with card description
   - Add to Board Compatibility Matrix
   - Create schematic PDF
   - Document I/O addresses and register map

7. **Build and Test**:
   - Order prototype
   - Test all functionality
   - Update Testing Status when verified

### Firmware Development

1. **Set Up Environment**:
   ```bash
   cd Firmware/<ProjectName>
   pio init   # If creating new project
   ```

2. **Write Code**:
   - Follow existing firmware structure
   - Use libraries when available (ArduinoJson, Bounce2, etc.)
   - Comment code thoroughly
   - Use meaningful variable/function names

3. **Build and Test**:
   ```bash
   pio run                      # Build
   pio run --target upload      # Upload to microcontroller
   pio device monitor           # Monitor serial output
   ```

4. **Debug**:
   - Add debug print statements
   - Use serial monitor to observe behavior
   - Test edge cases (invalid inputs, boundary conditions)

5. **Document**:
   - Update firmware README with features
   - Document API/registers (for microcontrollers acting as peripherals)
   - Add comments explaining complex logic

### Contributing CAD Designs

1. **Create Enclosure**:
   - Measure assembled boards accurately
   - Design in Fusion 360, OpenSCAD, FreeCAD, or similar
   - Allow clearances for connectors, cables, ventilation
   - Include mounting holes for standoffs

2. **Export Models**:
   - STL for 3D printing
   - STEP for CAD interchange

3. **Test Print**:
   - Print prototype (PLA or PETG recommended)
   - Verify fit with actual boards
   - Iterate as needed

4. **Commit to Repository**:
   ```bash
   git add CAD/<EnclosureName>/
   git commit -m "Add enclosure for <SystemName>"
   git push
   ```

---

## Contributing

Contributions to the ac6502 project are welcome! Whether you're fixing bugs, adding features, testing untested boards, or improving documentation, your help is appreciated.

### How to Contribute

1. **Fork the Repository** on GitHub
2. **Clone Your Fork**:
   ```bash
   git clone https://github.com/<your-username>/6502.git
   cd 6502
   ```
3. **Create a Feature Branch**:
   ```bash
   git checkout -b feature/<your-feature-name>
   ```
4. **Make Your Changes** (see [Development Workflow](#development-workflow))
5. **Test Thoroughly** (build and verify your changes work)
6. **Commit with Clear Messages**:
   ```bash
   git add .
   git commit -m "Add <feature>: <clear description>"
   ```
7. **Push to Your Fork**:
   ```bash
   git push origin feature/<your-feature-name>
   ```
8. **Submit a Pull Request** on GitHub:
   - Describe your changes
   - Reference any related issues
   - Include photos/screenshots if applicable
   - Note testing performed

### Types of Contributions

**Hardware:**
- New card/helper designs
- Improvements to existing boards
- Bug fixes (incorrect component values, routing errors)
- Design optimizations (cost reduction, improved performance)

**Firmware:**
- New features for existing firmware
- Bug fixes
- Performance improvements
- Support for additional peripherals

**Software:**
- 65C02 assembly programs and examples
- Test programs
- BIOS improvements
- Monitor/debugger enhancements

**Documentation:**
- Improved README files
- Tutorials and how-to guides
- Assembly instructions with photos
- Troubleshooting additions

**Testing:**
- Testing UNTESTED boards
- Reporting bugs and issues
- Validating fixes

### Contribution Guidelines

**Code Style:**
- **C/C++**: Follow existing style

**Commit Messages:**
- Use present tense ("Add feature" not "Added feature")
- Be specific ("Fix Serial Card address decode logic" not "Fix bug")
- Reference issues if applicable (#123)

**Hardware Design:**
- Use KiCad 7.0+
- Include all library dependencies
- Run ERC (Electrical Rules Check) and DRC (Design Rules Check) before committing
- Follow existing board naming conventions
- Generate production files for new designs

**Firmware:**
- Test on actual hardware before submitting
- Include README or comments explaining usage
- Document any new PlatformIO dependencies in platformio.ini

**Documentation:**
- Use clear, concise language
- Assume intermediate skill level (explain advanced concepts, not basics)
- Include examples where helpful
- Test all commands/procedures before documenting

### Code of Conduct

- Be respectful and constructive
- Help newcomers with patience
- Give credit to others' work
- Focus on technical merit
- Keep discussions on-topic

### Reporting Issues

**Bug Reports:**
- Use GitHub Issues
- Include:
  - Board/firmware name and revision
  - Steps to reproduce
  - Expected vs. actual behavior
  - Photos/screenshots if applicable
  - Error messages (verbatim)

**Feature Requests:**
- Describe the feature and use case
- Explain why it's valuable
- Suggest possible implementation (optional)

### Getting Help

- **GitHub Issues**: Technical questions, bug reports
- **6502.org Forums**: General 6502 development discussion
- **Reddit r/beneater**: Retro computing community

Thank you for contributing to the ac6502 project!

---

## Licensing

This project is licensed under the **CERN Open Hardware Licence Version 2 - Permissive** (CERN-OHL-P v2).

### What This Means

**You are free to:**
- **Use** the designs for any purpose (personal, educational, commercial)
- **Study** the designs and learn from them
- **Modify** the designs to suit your needs
- **Distribute** copies of the original or modified designs
- **Manufacture** products based on these designs
- **Sell** products based on these designs

**Under these conditions:**
- **Attribution**: Give credit to the original designers
- **Share-Alike (for documentation only)**: If you distribute modified designs, you must make the source files available under the same license
- **No Warranty**: Designs are provided "as-is" without warranty of any kind

### Firmware Licensing

Firmware and software components may be licensed differently (check individual firmware folders). Generally:
- Original firmware: CERN-OHL-P v2 or MIT License
- Third-party libraries: Licensed under their respective licenses (see platformio.ini and library documentation)

### Using These Designs

**For Personal Use:**
- Build as many as you want
- Modify however you like
- No attribution required (but appreciated!)

**For Commercial Use:**
- You may manufacture and sell products based on these designs
- Attribution required (include link to this repository or credit in documentation)
- Provide source files if you've modified the designs (share-alike for documentation)

**For Educational Use:**
- Excellent for teaching digital design, computer architecture, embedded systems
- Use in classrooms, workshops, tutorials freely
- Attribution appreciated

### Third-Party Components

This project uses several third-party hardware modules and software libraries:
- **Pico9918**: [GitHub](https://github.com/visrealm/pico9918) - Check repository for license
- **vrEmu6502**: [GitHub](https://github.com/visrealm/vrEmu6502) - Check repository for license
- **ARMSID**: Commercial product from [RetroComp.cz](https://retrocomp.cz)
- **Arduino Libraries**: Various (MIT, GPL, Apache - see platformio.ini)

Respect the licenses of third-party components when using or redistributing.

### Full License Text

See the [LICENSE](./LICENSE) file for the complete CERN-OHL-P v2 license text.

---

**Project Maintainer:** A.C. Wright  
**Repository:** [https://github.com/acwright/6502](https://github.com/acwright/6502)  

---

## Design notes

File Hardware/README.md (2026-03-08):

6502 Hardware
=============

This folder contains KiCad hardware designs for all PCBs in the 6502 project. Each design includes complete schematics, PCB layouts, and component libraries.

---

## Table of Contents

- [Overview](#overview)
- [Folder Structure](#folder-structure)
- [Hardware Categories](#hardware-categories)
- [Design Standards](#design-standards)
- [Assembly Notes](#assembly-notes)
- [Revision History](#revision-history)

---

## Overview

The 6502 project hardware is organized into four main categories:

1. **Boards**: Core system boards (mainboards, backplanes, development boards)
2. **Cards**: Peripheral expansion cards that plug into backplane slots
3. **Helpers**: Interface boards that provide specific functionality or connectors
4. **Carts**: Cartridge boards for ROM images

All designs are created using **KiCad 7.0+** and optimized for manufacturing by **JLCPCB**. Designs use a mix of surface-mount (SMD) and through-hole (DIP/TH) components for optimal balance of manufacturability and hobbyist assembly.

---

## Folder Structure

```
Hardware/
├── <BoardName>/
│   ├── Rev X.X/
│       ├── <BoardName>.kicad_pro    # KiCad project file
│       ├── <BoardName>.kicad_sch    # Schematic file
│       ├── <BoardName>.kicad_pcb    # PCB layout file
│       ├── fp-lib-table              # Footprint library table
│       └── sym-lib-table             # Symbol library table
└── ...
```

Each board folder contains one or more revision subfolders. Always use the latest revision unless specifically maintaining compatibility with older versions.

---

## Design Standards

All hardware designs follow these standards for consistency and manufacturability:

### PCB Specifications

**Layers:**
- Simple boards: 2-layer

**Dimensions:**
- Card width: 100mm
- Card height: 60mm
- Board width: 100mm
- Board height: 100mm
- Helper width: 100mm
- Helper height: 50mm
- PCB thickness: 1.6mm standard

**Trace Width:**
- Signal traces: 0.254mm (10 mil) minimum, 0.381mm (15 mil) typical
- Power traces: 0.508mm (20 mil) minimum, wider for high current
- Clearance: 0.254mm (10 mil) minimum

**Vias:**
- Standard: 0.6mm drill, 1.0mm pad
- Power: 0.8mm drill, 1.2mm pad
- Minimum: 0.3mm drill, 0.6mm pad

**JLCPCB Compatibility:**
- All designs pass JLCPCB design rules (see Production folder)
- Component selection optimized for JLCPCB assembly catalog
- Alternative footprints provided where JLCPCB parts unavailable

### Component Selection

**IC Packages:**
- Through-hole (DIP): For CPUs, RAM, ROM, socketed ICs
- SMD (SOIC, TSSOP, QFN): For modern ICs, microcontrollers, buffers

**Passive Components:**
- SMD: 0805 or 1206 packages (hand-solderable)
- Through-hole: 1/8W resistors, radial capacitors (when space allows)

**Connectors:**
- Through-hole: For all connectors (mechanical stress consideration)
- IDC headers: 2.54mm pitch for ribbon cables
- Card edge: Gold-plated fingers for backplane cards

### Schematic Conventions

**Net Naming:**
- Address bus: A0-A15
- Data bus: D0-D7
- Control signals: PHI2, RWB, RESB, IRQB, NMIB, etc.
- Power: +5V or VCC, GND
- Chip enables: CS, CSB (active low)

**Component References:**
- U: Integrated circuits
- R: Resistors
- C: Capacitors
- D: Diodes
- Q: Transistors
- J: Connectors/headers
- SW: Switches
- LED: LEDs
- Y: Crystals/oscillators

**Component Values:**
- Resistors: Ohms (100R, 1K, 10K)
- Capacitors: Farads (100nF, 10μF, 100μF)
- Inductors: Henries (10μH, 100μH)

---

## Assembly Notes

### Component Orientation

**ICs in DIP sockets:**
- Pin 1 indicator (notch or dot) must align with socket and PCB marking
- CPU, RAM, ROM: Check datasheets for pin 1 location

**Electrolytic capacitors:**
- Polarity marked on PCB (+ and -)
- Negative stripe on capacitor body aligns with - on PCB

**Diodes:**
- Cathode band aligns with band on PCB silkscreen

**LEDs:**
- Longer lead (anode) to + pad
- Flat side (cathode) to - pad or square pad

### Soldering Tips

**Through-hole:**
- Insert component from top, bend leads on bottom
- Apply soldering iron to pad + lead simultaneously
- Feed solder to junction (not to iron tip)
- Remove iron then solder wire
- Ideal joint: shiny, concave fillet

**SMD (if hand-soldering):**
- Use fine-tip soldering iron (conical tip)
- Apply flux to pads
- Tack one corner pin first
- Solder remaining pins
- Check for bridges with magnification
- Use solder wick to remove bridges

**IC sockets:**
- Tack opposite corner pins first
- Solder all remaining pins
- Check alignment before soldering all pins

### DRC (Design Rules Check) Verification

Before ordering PCBs, run DRC in KiCad:
1. Open PCB layout in KiCad
2. Select Tools → Design Rules Checker
3. Load JLCPCB design rules (if available in Production folder)
4. Run DRC
5. Fix all errors (warnings acceptable if understood)

Common errors:
- Trace too thin (minimum 0.127mm outer layer)
- Clearance too small (minimum 0.127mm)
- Via drill too small (minimum 0.3mm)
- Silkscreen over pads (warnings, JLCPCB will clip automatically)

---

## Revision History

### Rev 0.0 (Prototyping - 2024)

**Boards:**
- Dev Board

**Known Issues (Rev 1.0):**
- Dev Board 0.0 uses TXS0108 level shifters which were found to be unpredictable on the 6502 bus with some cards

### Rev 1.0 (Initial Release - 2024)

**Boards:**
- Initial designs for all boards
- Backplane, Backplane Pro, Main Board, Dev Board

**Cards:**
- CPU Card, Memory Card, Video Card, VGA Card, Serial Card
- GPIO Card, Sound Card, Storage Card
- Blinkenlights Card, LCD Card, Prototype Card
- RAM Card, RTC Card

**Helpers:**
- Keyboard Encoder Helper, PS2 Helper
- Keypad Helper, Keyboard Helper
- Clock Helper, GPIO Helper, Breadboard Helper
- Joystick Helper, DB25 Helper
- Backplane Helper, Mega Helper

**Carts:**
- ROM Cart

**Known Issues (Rev 1.0):**
- None

### Rev 1.1 (Planned - Future)

**Improvements:**
- TODO

---

## Working with Hardware Designs

### Opening in KiCad

1. Install [KiCad 7.0 or later](https://www.kicad.org/)
2. Clone this repository or download specific board folder
3. Navigate to `Hardware/<BoardName>/Rev X.X/`
4. Open `<BoardName>.kicad_pro` in KiCad

### Viewing Schematics

1. With project open, click "Schematic Editor" icon
2. Navigate multi-sheet schematics with sheet hierarchy (left panel)
3. Use Find tool (Ctrl+F / Cmd+F) to locate specific nets or components

### Viewing PCB Layout

1. With project open, click "PCB Editor" icon
2. Use 3D Viewer (View → 3D Viewer) to see board in 3D
3. Toggle layers (right panel) to examine inner layers, silkscreen, etc.

### Exporting Production Files

See [Production README](../Production/README.md) for detailed export instructions.

Quick export (from PCB Editor):
- Gerbers: File → Fabrication Outputs → Gerbers
- Drill files: File → Fabrication Outputs → Drill Files
- BOM: File → Fabrication Outputs → BOM
- Pick and Place: File → Fabrication Outputs → Footprint Position (.pos) File

---

**For more information, see:**
- [Main README](../README.md) - Project overview and system descriptions
- [Production README](../Production/README.md) - Manufacturing and ordering
- [Firmware README](../Firmware/README.md) - Firmware for microcontroller-based boards
- [Schematics README](../Schematics/README.md) - Schematic viewing and conventions

---

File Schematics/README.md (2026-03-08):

6502 Schematics
===============

This folder contains **PDF exports** of schematic diagrams for all PCBs in the 6502 project. The original KiCad schematic source files (.kicad_sch) are located in the [Hardware](../Hardware) folder alongside the PCB layouts.

---

## Table of Contents

- [Overview](#overview)
- [Folder Structure](#folder-structure)
- [Opening Schematics](#opening-schematics)
- [Reading Schematics](#reading-schematics)
- [Schematic Conventions](#schematic-conventions)
- [Exporting Schematics](#exporting-schematics)

---

## Overview

This folder provides **PDF exports** of all schematics for easy viewing without requiring KiCad. The PDFs show:
- Component placement and values
- Net connections (wires)
- Power distribution
- Signal routing
- Component reference designators

**Use cases:**
- Quick reference without opening KiCad
- Understanding circuit operation
- Troubleshooting hardware issues
- Printing for bench reference
- Learning digital design principles

**To modify designs:** Access the original KiCad schematic files in the [Hardware](../Hardware) folder.

---

## Folder Structure

```
Schematics/
├── <BoardName>/<Rev X.X>/
│   └── <BoardName>.pdf           # PDF schematic export
└── ...
```

**For KiCad source files (.kicad_sch), see:**
```
Hardware/
├── <BoardName>/
│   └── Rev X.X/
│       ├── <BoardName>.kicad_sch      # Schematic source file
│       ├── <BoardName>.kicad_pcb      # PCB layout
│       └── <BoardName>.kicad_pro      # KiCad project
└── ...
```

### Multi-Sheet Schematics

Complex designs use hierarchical schematics with multiple sheets. In the PDF exports:
- Multi-page PDFs contain all sheets
- Each page represents one schematic sheet
- Navigation index usually on first page

---

## Viewing Schematics

### PDF Viewing (This Folder)

1. **Navigate** to `Schematics/<BoardName>/`
2. **Open** `<BoardName>.pdf` in any PDF viewer
   - Adobe Acrobat Reader
   - Preview (macOS)
   - Browser (Chrome, Firefox, Edge)
   - PDF viewers on Linux (Evince, Okular)

**Features:**
- Searchable text (component references, net names)
- Printable for bench reference
- Zoom and pan for detail
- Multi-page navigation for complex designs
- No KiCad installation required

**Limitations:**
- Not editable (view-only)
- Cannot export netlists or BOMs

### Editing Schematics (KiCad Required)

To modify schematics:
1. **Install KiCad 7.0+** from [kicad.org](https://www.kicad.org/)
2. **Navigate** to `Hardware/<BoardName>/Rev X.X/`
3. **Open** `<BoardName>.kicad_sch` in KiCad Schematic Editor
4. Make edits and regenerate PDFs if needed

---

## Reading Schematics

### Navigation in PDF

**Single-Page PDFs:**
- Zoom: Ctrl/Cmd + Plus/Minus or zoom controls
- Pan: Click and drag or scroll bars
- Fit to page: Zoom controls or keyboard shortcuts (varies by viewer)
- Search: Ctrl/Cmd + F to find component references or net names

**Multi-Page PDFs:**
- Page navigation: Sidebar thumbnails or page controls
- Jump to page: Direct page number entry
- Bookmarks: Some PDFs include bookmarks for major sections

### Component Information

**Component Symbol:**
- Shows graphical representation (IC outline, resistor symbol, etc.)
- Pin numbers and names
- Reference designator (U1, R5, C12)
- Value (10K, 100nF, 74LS245)

**To see additional details** (footprint, datasheet, part numbers):
- Refer to BOM files in Production/ folder
- Open source schematic in KiCad (Hardware/ folder)

### Net Names

Wires (nets) connect components:
- **Labels**: Named connections (e.g., A0, D7, PHI2)
- **Global labels**: Connections across sheets (bus signals)
- **Power symbols**: +5V, GND (automatically connected)

**Tracing connections in PDF:**
- Follow wire lines visually
- Use search (Ctrl/Cmd + F) to find all instances of a net name
- Check multiple pages for connections in multi-sheet designs

---

## Schematic Conventions

### Net Naming

**Address Bus:**
- A0, A1, A2, ..., A15 (16-bit address)

**Data Bus:**
- D0, D1, D2, ..., D7 (8-bit data)

**Bus Control Signals:**
- PHI2: Clock
- RWB: Read/Write (1=Read, 0=Write)
- RESB: Reset (active low)
- IRQB: Interrupt Request (active low)
- NMIB: Non-Maskable Interrupt (active low)
- RDY: Ready (for clock stretching)
- SYNC: Sync 
- BE: Bus Enable
- EXP0-3: Extra Pins 0-3 (Reserved for future use)

**Power:**
- +5V or VCC: Positive supply
- GND: Ground

**Chip Enables:**
- CS: Chip Enable/Chip Select (active high)
- CSB: Chip Enable/Select (active low, indicated by B suffix or overline)

### Component References

| Prefix | Component Type | Examples |
|---|---|---|
| U | Integrated Circuit | U1 (CPU), U2 (RAM), U3 (VIA) |
| R | Resistor | R1 (10K), R2 (4.7K) |
| C | Capacitor | C1 (100nF), C2 (10μF) |
| D | Diode | D1 (1N4148), D2 (LED) |
| Q | Transistor | Q1 (2N3904) |
| J | Connector | J1 (USB), J2 (power jack) |
| SW | Switch | SW1 (reset button) |
| Y | Crystal/Oscillator | Y1 (1.8432 MHz) |
| L | Inductor | L1 (10μH) |
| F | Fuse | F1 (1A) |
| TP | Test Point | TP1 (GND), TP2 (5V) |

### Value Notation

**Resistors:**
- 100 or 100R or 100Ω = 100 ohms
- 1K or 1KΩ = 1,000 ohms (1 kilo-ohm)
- 10K = 10,000 ohms
- 1M = 1,000,000 ohms (1 mega-ohm)

**Capacitors:**
- 100pF = 100 picofarads
- 1nF = 1,000 pF (1 nanofarad)
- 100nF = 0.1μF (100 nanofarads or 0.1 microfarads)
- 10μF = 10 microfarads
- 1000μF = 1 millifarad

**Inductors:**
- 10μH = 10 microhenries
- 100μH = 100 microhenries

---

## Regenerating PDF Exports

The PDFs in this folder are exported from the KiCad source files in the Hardware/ folder. If you modify a schematic, regenerate the PDF:

### PDF Export from KiCad

1. Open schematic in KiCad (from Hardware/<BoardName>/ folder)
2. File → Plot
3. Select "PDF" as output format
4. Configure:
   - Include border + title block: Yes
   - Single page per sheet: Yes (for multi-sheet)
   - Output directory: Set to Schematics/<BoardName>/
5. Click "Plot All Pages"
6. PDF saved to Schematics/ folder

### Additional Exports (From Hardware/ Folder)

**Netlist Export:**
1. File → Export → Netlist
2. Select format (usually "Classic KiCad")
3. Use for simulation tools (SPICE, LTSpice) or custom analysis

**BOM Export:**
1. File → Export → BOM
2. Select BOM format plugin
3. Use for component ordering and cost estimation

**Note:** Production-ready BOM files are available in the Production/ folder.

---

**For more information, see:**
- [Main README](../README.md) - Project overview
- [Hardware README](../Hardware/README.md) - PCB layouts and pin assignments
- [KiCad Documentation](https://docs.kicad.org/) - KiCad user guide

---

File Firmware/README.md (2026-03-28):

6502 Firmware
=============

This folder contains firmware for microcontrollers used throughout the 6502 project. Firmware is written in C/C++ using the **PlatformIO** development environment and targets various microcontrollers including Teensy 4.1, ATmega328p, ATmega1284p, and ATTiny85.

---

## Table of Contents

- [Overview](#overview)
- [Firmware Projects](#firmware-projects)
- [Development Environment Setup](#development-environment-setup)
- [Building and Uploading](#building-and-uploading)
- [Debugging](#debugging)
- [Firmware by System](#firmware-by-system)
- [Common Libraries](#common-libraries)
- [Naming Conventions](#naming-conventions)

---

## Overview

The 6502 project uses microcontrollers to provide:
- **CPU Emulation**: Teensy 4.1 emulates 65C02 with cycle accuracy
- **Peripheral Controllers**: Microcontrollers manage keyboards, mice, displays, storage
- **Protocol Translation**: Convert modern protocols (PS/2, USB) to 6502-compatible interfaces
- **Enhanced Features**: Add capabilities not available in vintage hardware (networking, web interfaces)

### Microcontroller Platforms

| Platform | Clock Speed | Flash | RAM | Used In |
|---|---|---|-----|---|
| Teensy 4.1 | 600 MHz | 8MB | 1MB (+8MB PSRAM) | Dev Board, Dev Output Board |
| ATmega1284p | 16 MHz | 128KB | 16KB | Keyboard Encoder Helper, Input Board Rev 1.0 |
| ATmega328p | 16 MHz | 32KB | 2KB | PS2 Helper |
| ATTiny85 | 8 MHz | 8KB | 512 bytes | Input Board Rev 0.0 (keyboard + mouse) |

---

## Firmware Projects

### By Hardware Board

| Firmware Project | Target Board | Microcontroller | System | Purpose |
|---|---|---|---|---|
| [DB Emulator](./DB%20Emulator/) | Dev Board | Teensy 4.1 | DEV | 65C02 emulation + networking + web control |
| [DOB Display](./DOB%20%20Display/) | Dev Output Board | Teensy 4.0 | DEV | TMS9918A VDP + SID audio emulation on 2.4" LCD |
| [IB Keyboard Controller](./IB%20Keyboard%20Controller/) | Input Board Rev 0.0 | ATTiny85 | VCS | PS/2 keyboard to serial interface |
| [IB Mouse Controller](./IB%20Mouse%20Controller/) | Input Board Rev 0.0 | ATTiny85 | VCS | PS/2 mouse interface |
| [KEH Controller](./KEH%20Controller/) | Keyboard Encoder Helper, Input Board 1.0 | ATmega1284p | COB/KIM | PS/2 + matrix keyboard to ASCII |
| [PS2 Keyboard Controller](./PS2%20Keyboard%20Controller/) | PS2 Helper | ATmega328p | COB/KIM | PS/2 keyboard to matrix emulation |
| [STP Controller](./STP%20Controller/) | Storage Card Pro | (varies) | COB | SD + Flash storage controller |

---

## Development Environment Setup

### Prerequisites

**Required Software:**
- [PlatformIO Core](https://platformio.org/install/cli) (CLI) or [PlatformIO IDE](https://platformio.org/platformio-ide) (VS Code extension)
- [Python 3.7+](https://www.python.org/) (usually bundled with PlatformIO)
- [Git](https://git-scm.com/) (for cloning repositories and dependencies)

**Optional Tools:**
- [Visual Studio Code](https://code.visualstudio.com/) (recommended editor with PlatformIO extension)
- [Teensy Loader](https://www.pjrc.com/teensy/loader.html) (alternative upload tool for Teensy)
- [AVRDUDE](https://www.nongnu.org/avrdude/) (alternative programmer for AVR chips)

### PlatformIO Installation

#### Option 1: PlatformIO IDE (Recommended for Beginners)

1. Install Visual Studio Code from [code.visualstudio.com](https://code.visualstudio.com/)
2. Open VS Code
3. Go to Extensions (Ctrl+Shift+X / Cmd+Shift+X)
4. Search for "PlatformIO IDE"
5. Click Install
6. Restart VS Code

#### Option 2: PlatformIO Core (CLI)

**macOS/Linux:**
```bash
# Using curl
python3 -c "$(curl -fsSL https://raw.githubusercontent.com/platformio/platformio-master/scripts/get-platformio.py)"

# Or using pip
pip install -U platformio
```

**Windows:**
```bash
pip install -U platformio
```

**Verify Installation:**
```bash
pio --version
# Should print: PlatformIO Core, version X.X.X
```

### Cloning the Repository

```bash
git clone https://github.com/acwright/6502.git
cd 6502/Firmware
```

---

## Building and Uploading

### Using PlatformIO Core (CLI)

**Build firmware:**
```bash
cd <FirmwareProject>    # e.g., cd DB\ Emulator
pio run                  # Compile only
```

**Upload to board:**
```bash
pio run --target upload  # Compile and upload
```

**Clean build:**
```bash
pio run --target clean   # Remove build artifacts
```

**Specific environment:**
```bash
pio run -e devboard_1    # Build for specific environment (if multiple defined)
```

### Using PlatformIO IDE (VS Code)

1. Open firmware project folder in VS Code (File → Open Folder)
2. PlatformIO should auto-detect `platformio.ini`
3. Bottom toolbar will show PlatformIO tasks:
   - **Build** (✓ checkmark icon): Compile firmware
   - **Upload** (→ arrow icon): Compile and upload
   - **Clean** (🗑 trash icon): Clean build files
   - **Serial Monitor** (🔌 plug icon): Open serial monitor

**Keyboard Shortcuts:**
- Build: Ctrl+Alt+B / Cmd+Alt+B
- Upload: Ctrl+Alt+U / Cmd+Alt+U
- Serial Monitor: Ctrl+Alt+S / Cmd+Alt+S

### Serial Monitoring

**Using PlatformIO:**
```bash
pio device monitor
# Default baud rate from platformio.ini (usually 115200)
```

**Specify baud rate:**
```bash
pio device monitor -b 115200
```

**Exit serial monitor:** Ctrl+C

**Using CoolTerm (Recommended):**
1. Install [CoolTerm](https://freeware.the-meiers.org/)
2. Select serial port (usually /dev/ttyUSB0 or COM3 on Windows)
3. Set baud rate (115200 typical for Teensy, varies for others)
4. Click Connect

---

## Debugging

### Common Issues

**Upload fails:**
- Verify correct USB port selected
- Press reset/bootloader button on board (especially Teensy)
- Try different USB cable (some are charge-only, not data)
- Check USB drivers (Windows: Teensy drivers, AVR: FTDI/CH340 drivers)

**Code compiles but doesn't run:**
- Verify correct board environment in `platformio.ini`
- Check fuse settings (AVR microcontrollers)
- Verify clock source (external crystal vs. internal oscillator)
- Use serial output to check if code is executing

**Serial monitor shows garbage:**
- Wrong baud rate (check platformio.ini or firmware source)
- Line ending settings (usually CR+LF)
- Try different baud rates: 9600, 19200, 38400, 57600, 115200

**Crashes or resets:**
- Stack overflow (reduce local variable size, or increase stack)
- Watchdog timer (ensure watchdog properly configured)
- Power supply issues (check voltage and current)
- Buffer overruns (check array bounds)

---

## Firmware by System

### DEV System Firmware

**[DB Emulator](./DB%20Emulator/)** (Dev Board):
- Cycle-accurate 65C02 emulation via [vrEmu6502](https://github.com/visrealm/vrEmu6502)
- Variable CPU speed (0 Hz to maximum, exceeding real 65C02)
- Ethernet with mDNS discovery (`6502.local`)
- Embedded web server (REST API for control)
- SD card support (load ROMs, programs, save snapshots)
- USB host (keyboard, joystick input)
- Serial terminal (115200 baud)
- Real-time clock

**[DOB Display](./DOB%20%20Display/)** (Dev Output Board):
- Full TMS9918A VDP emulation (Graphics I/II, Text, Multicolor modes)
- SID 6581 3-voice audio synthesis (triangle, sawtooth, pulse, noise + full ADSR)
- ILI9341 2.4" TFT LCD (320×240) with 256×192 active area and TMS9918A color borders
- AV packet protocol at 6 Mbps via hardware UART (Serial1) from DB Emulator
- ~60 FPS rendering from VRAM state

### COB/KIM System Firmware

**[KEH Controller](./KEH%20Controller/)** (Keyboard Encoder Helper):
- Dual input: PS/2 keyboard + 8×8 keyboard matrix (simultaneous)
- ASCII conversion (0x00-0xFF extended character set)
- Full modifier support (Shift, Ctrl, Alt, Fn)
- Function keys F1-F12
- Circular buffer (16 bytes)
- Output via 6522 VIA ports

**[PS2 Keyboard Controller](./PS2%20Keyboard%20Controller/)** (PS2 Helper):
- PS/2 protocol decoding (with parity checking)
- MT8808 8×8 crosspoint switch control
- Emulates keyboard matrix
- Extended scancode support (E0 prefix for arrows, nav keys)
- Function key emulation (Fn + number keys = F1-F10)

### VCS System Firmware

**[KEH Controller](./KEH%20Controller/)** (Input Board Rev 1.0):
- Dual input: PS/2 keyboard + 8×8 keyboard matrix (simultaneous)
- ASCII conversion (0x00-0xFF extended character set)
- Full modifier support (Shift, Ctrl, Alt, Fn)
- Function keys F1-F12
- Circular buffer (16 bytes)
- Output via 6522 VIA ports

**[IB Keyboard Controller](./IB%20Keyboard%20Controller/)** (Input Board Rev 0.0 - ATTiny85 #1):
- PS/2 keyboard protocol decoding
- ASCII conversion
- Shift register output (serial)
- Circular buffer (16 bytes)
- Interrupt-driven (low latency)

**[IB Mouse Controller](./IB%20Mouse%20Controller/)** (Input Board Rev 0.0 - ATTiny85 #2):
- PS/2 mouse protocol decoding
- X/Y coordinate tracking
- Button state (left, right, middle)
- Interrupt-driven (low latency)

### Other Firmware

**[STP Controller](./STP%20Controller/)** (Storage Card Pro):
- SPI controller for 6502
- SD card interface (SPI)
- SPI Flash interface (16MB onboard)
- External SPI header
- **Status:** Firmware not verified

---

## Common Libraries

Firmware projects use these common libraries (managed via PlatformIO):

### Arduino Core Libraries
- **Wire**: I2C communication
- **SPI**: SPI communication (SD cards, displays)
- **Serial**: UART communication

### Third-Party Libraries

**DB Emulator:**
- [vrEmu6502](https://github.com/visrealm/vrEmu6502): 65C02 CPU emulation
- [QNEthernet](https://github.com/ssilverman/QNEthernet): Teensy Ethernet
- [ArduinoJson](https://github.com/bblanchon/ArduinoJson): JSON parsing (REST API)
- [AsyncWebServer_Teensy41](https://github.com/khoih-prog/AsyncWebServer_Teensy41): Async web server
- [Bounce2](https://github.com/thomasfredericks/Bounce2): Button debouncing
- [TimeLib](https://github.com/PaulStoffregen/Time): Time management

**DOB Display:**
- [ILI9341_t3n](https://github.com/KurtE/ILI9341_t3n): Optimized ILI9341 driver for Teensy (replaces Adafruit_GFX + Adafruit_ILI9341)

**KEH/PS2 Controllers:**
- [PS2Keyboard](https://github.com/PaulStoffregen/PS2Keyboard): PS/2 protocol (or custom implementation)

### Installing Libraries

Libraries are automatically installed by PlatformIO based on `platformio.ini`:

```ini
[env:myboard]
lib_deps =
    bblanchon/ArduinoJson@^6.21.0
    paulstoffregen/Time@^1.6.1
```

**Manual installation (if needed):**
```bash
pio lib install "ArduinoJson"
```

---

## Naming Conventions

### Folder Name Prefixes

Firmware folders use prefixes to indicate target hardware:

- **DB**: Dev Board (e.g., DB Emulator)
- **DOB**: Dev Output Board (e.g., DOB Display)
- **IB**: Input Board (e.g., IB Keyboard Controller, IB Mouse Controller)
- **KEH**: Keyboard Encoder Helper (e.g., KEH Controller)
- **PS2**: PS2 Helper (e.g., PS2 Keyboard Controller)
- **STP**: Storage Card Pro (e.g., STP Controller)
- **MH**: Mega Helper (if firmware exists)
- **VGAP**: VGA Card Pro (if firmware exists)
- **VCP**: Video Card Pro (if firmware exists)

### File Structure (Typical)

```
<FirmwareProject>/
├── platformio.ini          # PlatformIO configuration
├── README.md               # Project-specific documentation
├── src/
│   ├── main.cpp            # Main firmware source
│   ├── config.h            # Configuration options
│   └── <other .cpp/.h>     # Additional source files
├── include/                # Header files
├── lib/                    # Project-specific libraries
└── test/                   # Unit tests (if any)
```

### PlatformIO Environments

`platformio.ini` may define multiple environments for different board revisions:

**Example (DB Emulator):**
```ini
[env:devboard_0]
board = teensy41
platform = teensy
framework = arduino
; Configuration for original Dev Board revision

[env:devboard_1]
board = teensy41
platform = teensy
framework = arduino
; Configuration for Dev Board Rev 1.1
```

Build specific environment:
```bash
pio run -e devboard_1
```

---

## Working with Firmware

### Modifying Existing Firmware

1. Navigate to firmware folder:
   ```bash
   cd Firmware/<ProjectName>
   ```

2. Edit source files in `src/` folder

3. Build and test:
   ```bash
   pio run                 # Compile
   pio run --target upload # Upload
   pio device monitor      # Monitor output
   ```

4. Commit changes:
   ```bash
   git add src/
   git commit -m "Description of changes"
   ```

### Creating New Firmware

1. Create project folder:
   ```bash
   mkdir Firmware/<NewProject>
   cd Firmware/<NewProject>
   ```

2. Initialize PlatformIO project:
   ```bash
   pio init -b <board_id>
   # Examples: teensy41, ATmega328P, ATmega1284P, attiny85
   ```

3. Edit `platformio.ini` to add libraries, build flags, etc.

4. Write firmware in `src/main.cpp`

5. Create README.md documenting:
   - Purpose and features
   - Hardware requirements
   - Build instructions
   - Configuration options
   - Register/API documentation (if applicable)

---

## Resources

**PlatformIO Documentation:**
- [PlatformIO Core](https://docs.platformio.org/en/latest/core/index.html)
- [PlatformIO IDE](https://docs.platformio.org/en/latest/ide/index.html)
- [Library Management](https://docs.platformio.org/en/latest/librarymanager/index.html)

**Microcontroller Documentation:**
- [Teensy 4.1](https://www.pjrc.com/store/teensy41.html)
- [ATmega1284p Datasheet](https://www.microchip.com/en-us/product/ATmega1284P)
- [ATmega328p Datasheet](https://www.microchip.com/en-us/product/ATmega328P)
- [ATTiny85 Datasheet](https://www.microchip.com/en-us/product/ATtiny85)

**6502 Resources:**
- [6502.org](http://www.6502.org/) - Community forum and resources
- [vrEmu6502 Documentation](https://github.com/visrealm/vrEmu6502)
- [6502 Instruction Reference](http://www.6502.org/tutorials/6502opcodes.html)

---

**For more information, see:**
- [Main README](../README.md) - Project overview
- [Hardware README](../Hardware/README.md) - Hardware specifications and pin assignments
- Individual firmware project READMEs for detailed documentation

---

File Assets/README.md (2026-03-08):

6502 Assets
===========

This folder contains supporting assets for the 6502 project including documentation, images, branding materials, and reference files.

---

## Folder Structure

```
Assets/
├── Branding/           # Logos, branding materials, visual identity
├── Documents/          # Technical documentation, datasheets, references
│   ├── Memory Map/
│   ├── Keyboard Map/
│   ├── Keyboard Layout/
│   └── Keyboard Matrix/
├── Images/             # Photos of assembled systems, boards
├── PCB Images/         # Renders and photos of individual PCBs
├── PCB Logos/          # Logo files for PCB silkscreen
└── PCB Models/         # 3D models for PCB visualization
```

---

## Folder Contents

### Branding

Logos and branding materials for the 6502 project:
- Project logo (various formats: SVG, PNG, AI)
- Color schemes and style guides
- Marketing materials

**Usage:**
- Documentation headers
- PCB silkscreen logos
- Enclosure labels
- Presentation materials

### Documents

Technical documentation and reference materials:

**Memory Map:**
- Complete memory map documentation (PDF)
- Shows memory ranges for RAM, ROM, I/O devices
- Standard across all systems

**Keyboard Map:**
- Complete keyboard layout and scancode mappings (Markdown)
- 8×8 matrix layout
- Modifier key combinations

**Keyboard Layout:**
- JSON format keyboard layout
- For use with keyboard design tools ([keyboard-layout-editor.com](https://www.keyboard-layout-editor.com))

**Keyboard Matrix:**
- Matrix scanning architecture
- Row/column assignments

### Images

Photos of complete systems:
- COB system photos
- DEV system photos
- KIM system photos
- VCS system photos
- Other general use photos
- Community contributions

**Usage:**
- Main README illustrations
- Documentation
- Social media
- Presentations

### PCB Images

Individual PCB renders and photos:
- 3D renders from KiCad
- Top/bottom layer views
- Manufactured board photos
- Assembly stages

**Usage:**
- Hardware README
- Assembly guides
- Production verification

### PCB Logos

Logo files optimized for PCB silkscreen:
- Vector formats (SVG, DXF)
- Footprint libraries for KiCad
- Various sizes for different board sizes

**Usage:**
- Import into KiCad PCB layouts
- Add to silkscreen layer
- Branding identifier on boards

### PCB Models

3D models (STEP format) of complete PCB assemblies:
- Boards with components
- For CAD assembly visualization
- Enclosure design reference

**Usage:**
- Import into enclosure CAD designs
- Verify component clearances
- System assembly visualization

---

## Key Documentation

### Memory Map

**File:** `Documents/Memory Map.png`

**Purpose:** Standard memory layout used across all 6502 systems

**Contents:**
- $0000-$7FFF: RAM (32KB)
  - $0000-$00FF: Zero Page
  - $0100-$01FF: Stack
  - $0200-$02FF: Input Buffer
  - $0300-$03FF: KERNAL Variables
  - $0400-$07FF: User Variables
  - $0800-$7FFF: Program RAM (~30KB)
- $8000-$9FFF: I/O space (8KB, 8 slots × 1KB each)
  - IO 1-2 ($8000-$87FF): RAM Card
  - IO 3 ($8800-$8BFF): RTC Card
  - IO 4 ($8C00-$8FFF): Storage Card
  - IO 5 ($9000-$93FF): Serial Card
  - IO 6 ($9400-$97FF): GPIO Card
  - IO 7 ($9800-$9BFF): Sound Card
  - IO 8 ($9C00-$9FFF): Video Card
- $A000-$BFFF: LO System ROM (KERNAL, 8KB)
- $C000-$FFFF: HI System ROM or Cart ROM (16KB)
- Interrupt vectors ($FFFA-$FFFF)

### Keyboard Map

**File:** `Documents/Keyboard Map/Keyboard Map.md`

**Purpose:** Complete keyboard matrix layout and key mappings

**Contents:**
- 8×8 matrix layout (64 keys)
- ASCII code mappings
- Modifier key combinations (Shift, Ctrl, Alt, Fn)
- Function key assignments (F1-F12)
- Extended characters ($80-$FF)

---

**For more information, see:**
- [Main README](../README.md) - Project overview
- [Hardware README](../Hardware/README.md) - Hardware specifications

---

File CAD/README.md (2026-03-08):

6502 CAD Designs
================

This folder contains mechanical CAD designs for enclosures, mounting solutions, and 3D models for the 6502 project. Designs are available in multiple formats for 3D printing, CNC machining, or laser cutting.

---

## Table of Contents

- [Overview](#overview)
- [Folder Structure](#folder-structure)
- [Available Designs](#available-designs)
- [File Formats](#file-formats)
- [3D Printing](#3d-printing)
- [Using CAD Files](#using-cad-files)
- [Contributing CAD Designs](#contributing-cad-designs)

---

## Overview

CAD designs complement the PCBs by providing:
- **Enclosures**: Protective cases for complete systems
- **Mounting Solutions**: Standoffs, brackets, panel mounts
- **Mechanical Integration**: Keyboard housings, card guides, backplane frames
- **Visualization**: 3D models for understanding system assembly

---

## Folder Structure

```
CAD/
├── Bases/              # Complete system assemblies (COB, DEV, KIM, VCS)
│   ├── The COB/
│   │   ├── The COB.stl
│   │   ├── The COB.step
│   │   └── The COB.png (preview image)
│   ├── The DEV/
│   ├── The KIM/
│   └── The VCS/
├── Card/               # 3D models of individual cards
├── Enclosures/         # Custom enclosure designs
└── Tops/               # Top panels and covers
```

---

## Available Designs

### System Bases

- **The COB Base**
- **The DEV Base**
- **The KIM Base**
- **The VCS Base**

### Enclosures

Enclosure designs (when available) include:
- Top and/or bottom shells
- Cutouts for connectors (power, video, serial, USB, etc.)

### Top Panels

- Acrylic top panels with:
  - Button cutouts
  - Connector access

---

## File Formats

### STL (Stereolithography)
- **Purpose**: 3D printing
- **Software**: Any slicer (Cura, PrusaSlicer, Simplify3D)
- **Advantages**: Universal format, directly printable
- **Limitations**: Not easily editable

### STEP (Standard for the Exchange of Product Data)
- **Purpose**: CAD interchange, editing, CNC machining
- **Software**: Fusion 360, FreeCAD, SolidWorks, OnShape, etc.
- **Advantages**: Parametric, editable, high precision
- **Limitations**: Larger files

### DXF (Drawing Exchange Format) - If Available
- **Purpose**: 2D laser cutting, CNC routing
- **Software**: LaserCut, AutoCAD, Inkscape, etc.
- **Advantages**: Precise 2D outlines
- **Use**: Panel mounting holes, acrylic panels, metal enclosures

---

## 3D Printing

### Recommended Settings

**Enclosures:**
- **Material**: PLA (easiest), PETG (more durable), ABS (heat-resistant)
- **Layer Height**: 0.2mm (balance of speed and quality)
- **Infill**: 15-25% (adequate strength for enclosures)
- **Supports**: Usually required for overhangs >45°
- **Perimeters**: 3-4 walls (for strength)
- **Print Speed**: 50-60mm/s (PLA), 40-50mm/s (PETG)

### Post-Processing

**Remove Supports:**
- Use side cutters or pliers
- Sand support contact areas if needed

**Threaded Inserts:**
- Future designs may include holes for M2.5 or M3 threaded inserts
- Heat insert with soldering iron (set to 200-230°C)
- Press gently into plastic until flush

**Sanding/Finishing:**
- Sand with 200→400→600 grit for smooth finish
- Use filler primer for painted enclosures

---

## Using CAD Files

### Viewing 3D Models

**Online Viewers:**
- [3D Viewer Online](https://3dviewer.net/)
- Upload STL or STEP files to view in browser

**Desktop Software:**
- [FreeCAD](https://www.freecad.org/) (free, open-source)
- [Fusion 360](https://www.autodesk.com/products/fusion-360/personal) (free for hobbyists)
- [Blender](https://www.blender.org/) (free, primarily for rendering)

### Editing STEP Files

1. Open STEP file in Fusion 360 or FreeCAD
2. Modify dimensions, add features, adjust cutouts
3. Export as:
   - STL for 3D printing
   - DXF for 2D cutting (if extracting profile)
   - STEP for sharing editable version

### Customizing Enclosures

**Common Modifications:**
- Adjust enclosure dimensions for custom boards
- Add/remove connector cutouts
- Modify ventilation pattern
- Add text/logos to top panel
- Change mounting hole spacing

**Workflow:**
1. Import STEP file to CAD software
2. Make edits (add holes, change size, etc.)
3. Export STL
4. Slice and print

---

## Contributing CAD Designs

We welcome community contributions of enclosures and mechanical designs!

### Design Guidelines

**Enclosures:**
- Measure actual PCB dimensions (not just schematic)
- Allow 2-3mm clearance around PCBs
- Include ventilation (esp. for boards with regulators or microcontrollers)
- Design for printability (minimize supports)
- Include mounting holes for M2.5 or M3 standoffs
- Consider connector access

**File Requirements:**
- Provide both STL (for printing) and STEP (for editing)
- Include preview image (PNG or JPG)
- Write brief README describing design

### Submitting Designs

1. Create design in CAD software
2. Test print prototype
3. Export STL + STEP files
4. Add folder to `CAD/<CategoryName>/<YourDesign>/`
5. Include README.md with:
   - Description
   - Print settings used
   - Assembly instructions
   - Photos of finished print
6. Submit pull request on GitHub

---

**For more information, see:**
- [Main README](../README.md) - Project overview
- [Hardware README](../Hardware/README.md) - PCB dimensions and specifications

---

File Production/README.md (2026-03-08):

6502 Production Files
=====================

This folder contains JLCPCB-ready production files for manufacturing all PCBs in the 6502 project. Each board/card/helper has complete manufacturing packages including Gerber files, drill files, BOMs (Bill of Materials), and pick-and-place files for assembly.

---

## Table of Contents

- [Overview](#overview)
- [Folder Structure](#folder-structure)
- [Ordering from JLCPCB](#ordering-from-jlcpcb)
- [Production Files Included](#production-files-included)
- [Cost Estimates](#cost-estimates)
- [Quality Control](#quality-control)
- [Through-Hole Assembly](#through-hole-assembly)
- [Troubleshooting Orders](#troubleshooting-orders)

---

## Overview

All production files are optimized for **JLCPCB** manufacturing and assembly services. Files follow JLCPCB's specifications and use components from their assembly catalog when possible.

**Production File Generation:**
- All production files are generated using [Fabrication-Toolkit](https://github.com/bennymeg/Fabrication-Toolkit)
- This KiCad plugin automates the generation of Gerbers, drill files, BOMs, and pick-and-place files optimized for JLCPCB

**What's Included:**
- Gerber files (PCB layers, soldermask, silkscreen)
- Excellon drill files (plated and non-plated holes)
- BOMs with JLCPCB part numbers (LCSC codes)
- Pick-and-place (CPL) files for SMD assembly
- Design rule files (.kicad_dru) verified for JLCPCB capabilities

---

## Folder Structure

```
Production/
├── <BoardName>/
|   └── Rev X.X/
│       ├── <BoardName>_Gerber.zip       # Gerber + drill files (upload to JLCPCB)
│       ├── <BoardName>_BOM.csv          # Bill of Materials
│       ├── <BoardName>_CPL.csv          # Component placement (pick-and-place)
│       ├── <BoardName>.kicad_dru        # Design rules file
│       └── README.md (optional)         # Board-specific notes
└── ...
```

---

## Ordering from JLCPCB

### Step-by-Step Guide

**1. Prepare Files**
   - Locate board folder in Production/
   - Identify Gerber ZIP, BOM CSV, and CPL CSV files

**2. Go to JLCPCB Website**
   - Navigate to [jlcpcb.com](https://jlcpcb.com/)
   - Create account or log in

**3. Upload Gerber File**
   - Click "Order now" or "Quote now"
   - Click "Add gerber file"
   - Upload `<BoardName>_Gerber.zip`
   - Wait for automatic parsing and preview

**4. Configure PCB Options**

   **Basic Settings:**
   - **Dimensions**: Auto-detected from Gerber (verify correct)
   - **Layers**: 2 or 4 (check Hardware README for specific board)
   - **Quantity**: 5 or 10 minimum (5 is usually cheapest for prototypes)
   - **Thickness**: 1.6mm (standard)
   
   **Advanced Settings:**
   - **PCB Color**: Your choice
   - **Surface Finish**: 
     - HASL (lead-free): Most economical
     - ENIG: Better for edge connectors and fine pitch
   - **Remove Order Number**: Optional
   - **Gold Fingers**: Yes (for card edge connectors on Cards), No (for most boards)
   
**5. Enable SMD Assembly** (Optional but Recommended)
   - Scroll down to "SMT Assembly" section
   - Toggle "SMT Assembly" to ON
   
   **Assembly Options:**
   - **PCBA Type**: Economic (standard, good for most boards)
   - **Assembly Side**: Top Side (unless BOM specifies bottom)
   - **PCBA Qty**: Same as PCB quantity or fewer (e.g., order 10 PCBs, assemble 5)
   
   **Upload Assembly Files:**
   - Click "Add BOM File" → upload `bom.csv`
   - Click "Add CPL File" → upload `positions.csv`
   - Click "Process BOM & CPL"
   
**6. Component Selection**
   - JLCPCB will parse BOM and match components
   - Review component list:
     - **Green checkmark**: Component in stock, will be assembled
     - **Orange warning**: Component unavailable, select substitute or omit
     - **Red X**: Invalid part number, requires correction
   
   **For unavailable components:**
   - Click component row to search alternates
   - Select equivalent component (check datasheet for compatibility)
   - OR check "Do not place" to assemble manually later
   
**7. Confirm Placement**
   - Click "Next"
   - Review component placement preview (3D view)
   - Verify:
     - Component orientation (especially ICs, polarized parts)
     - No components placed on pads or traces
     - Correct side (top vs. bottom)
   - Click "Confirm" if everything looks correct
   
**8. Review and Order**
   - Review order summary:
     - PCB cost
     - Assembly cost ($3-8 setup fee + component costs)
     - Shipping cost
   - Select shipping method
   - Add to cart
   - Proceed to checkout
   - Enter shipping address and payment
   - Submit order

**9. Wait for Production**
   - PCB manufacturing: 1-3 days (standard)
   - SMD assembly: 1-4 days (after PCB complete)
   - Shipping: varies by method
   - Total: typically 7-21 days door-to-door

**10. Track Order**
   - JLCPCB sends email updates
   - Track shipment via provided tracking number

---

## Production Files Included

### Gerber Files (.gbr)

Gerber format describes each PCB layer:
- **.GTO** / **.gto**: Top silkscreen (component labels)
- **.GBO** / **.gbo**: Bottom silkscreen
- **.GTS** / **.gts**: Top soldermask (green/black coating)
- **.GBS** / **.gbs**: Bottom soldermask
- **.GTL** / **.gtl**: Top copper layer
- **.GBL** / **.gbl**: Bottom copper layer
- **.G2** / **.g2**: Inner layer 2 (4-layer boards only)
- **.G3** / **.g3**: Inner layer 3 (4-layer boards only)
- **.GKO** / **.gko** / **.gm1**: Board outline (edge cuts)

### Drill Files (.drl, .xln)

- **PTH (Plated Through-Holes)**: Holes with copper plating (component leads, vias)
- **NPTH (Non-Plated Through-Holes)**: Mounting holes, tooling holes

### BOM (Bill of Materials) (.csv)

CSV file listing all components:
- **Designator**: Component reference (U1, R1, C1, etc.)
- **Quantity**: Number of this component
- **Value**: Component value or part number
- **Footprint**: PCB footprint name
- **LCSC Part #**: JLCPCB/LCSC component catalog number

### CPL (Component Placement List) (.csv)

Pick-and-place file for assembly machines:
- **Designator**: Component reference
- **Mid X/Y**: Component center coordinates (mm)
- **Rotation**: Component orientation (degrees)
- **Layer**: Top or Bottom

---

## Quality Control

### When Boards Arrive

**Visual Inspection:**
1. Check for physical damage (cracks, bent boards)
2. Verify all SMD components placed correctly
3. Check component orientation (IC pin 1, polarized capacitors)
4. Inspect solder joints (should be shiny, concave fillets)
5. Look for solder bridges (shorts between pins)
6. Verify silkscreen legibility

**Electrical Testing:**
1. **Continuity Check:**
   - Use multimeter in continuity mode
   - Verify power rails (5V to all VCC pins)
   - Verify ground connections (GND to all GND pins)
   
2. **Short Circuit Check:**
   - Measure resistance between 5V and GND (should be >10kΩ typically)
   - If <100Ω, likely short circuit (do NOT power on)
   
3. **Visual Inspection (Magnified):**
   - Use magnifying glass or microscope
   - Check for solder bridges (especially fine-pitch ICs)
   - Check for cold solder joints (dull, grainy appearance)
   - Verify component values (especially resistors/capacitors if hand-placed)

**Common Issues:**

| Issue | Cause | Solution |
|---|---|---|
| Wrong component placed | BOM error or JLCPCB misidentification | Desolder and replace with correct part |
| Component rotated 90/180° | CPL rotation error | Desolder and rotate to correct orientation |
| Solder bridge | Excess solder or component misalignment | Remove with solder wick or solder sucker |
| Missing component | Component out of stock | Hand-solder component |
| Tombstoning (standing component) | Uneven heating during reflow | Reheat or replace component |

---

## Through-Hole Assembly

Most boards require some manual through-hole assembly after SMD assembly.

### Typical Through-Hole Components:
- IC sockets (CPU, RAM, ROM)
- Connectors (IDC headers, barrel jacks, DB9)
- Electrolytic capacitors (polarized)
- Crystals/oscillators
- Some resistors/capacitors (if space allows)

### Assembly Order (Recommended):
1. Shortest components first (resistors, diodes, small capacitors)
2. IC sockets (don't insert ICs yet)
3. Medium-height components (ceramic capacitors, headers)
4. Tall components (electrolytic capacitors, connectors)
5. Inspect all solder joints
6. Clean flux residue (isopropyl alcohol + soft brush)
7. Insert ICs into sockets (verify pin 1 orientation!)

### Soldering Tips:
- Use 330-350°C soldering iron (lead-free solder) or 300-320°C (leaded)
- Apply flux to through-hole pads before soldering
- Heat pad + lead simultaneously (1-2 seconds)
- Feed solder to joint (not to iron tip)
- Remove solder wire, then iron
- Ideal joint: shiny, concave fillet around lead

---

## Troubleshooting Orders

**Problem: Component marked unavailable in JLCPCB BOM**
- **Solution 1:** Search for alternate LCSC part number (similar specs)
- **Solution 2:** Mark "Do not place" and hand-solder later
- **Solution 3:** Redesign board to use available component (long-term)

**Problem: CPL placement preview shows wrong orientation**
- **Solution:** Edit CPL file rotation column (add/subtract 90° or 180°)
- Re-upload corrected CPL file

**Problem: Order rejected due to design rule violation**
- **Solution:** Download JLCPCB DRC report
- Identify violation (trace too thin, clearance too small, via size, etc.)
- Fix in KiCad and regenerate production files
- Re-upload corrected Gerber files

**Problem: Boards arrive with solder bridges**
- **Solution:** Use solder wick or desoldering braid to remove excess solder
- Apply flux, heat with soldering iron, wick absorbs solder

**Problem: Wrong component value assembled**
- **Solution:** Verify BOM LCSC part numbers match intended components
- Check LCSC website for component specifications
- Desolder incorrect component, solder correct one

---

**For more information, see:**
- [Main README](../README.md) - Project overview and assembly guide
- [Hardware README](../Hardware/README.md) - PCB specifications and design details
- [JLCPCB Capabilities](https://jlcpcb.com/capabilities/Capabilities) - Current manufacturing limits

---

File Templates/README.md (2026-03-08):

6502 Templates
==============

This folder contains KiCad project templates for creating new boards, cards, or helpers in the 6502 project. Templates provide pre-configured project settings, library links, and starting schematics/PCBs that follow project conventions.

---

## Overview

Templates accelerate new board development by providing:
- Pre-configured project settings
- Linked symbol and footprint libraries (6502 Parts, etc.)
- Standard design rules for JLCPCB manufacturing
- Worksheet (title block) with project information
- Starting schematic/PCB layouts (for cards: standard card edge connector)

---

## Available Templates

**Card Template:**
- For backplane-compatible peripheral cards
- Includes standard card edge connector
- Preconfigured dimensions (100mm × 60mm typical)
- Bus connection (A0-A15, D0-D7, control signals)
- Address decoding subcircuit placeholder
- Standard libraries linked

**Helper Template:**
- For helper boards connecting to GPIO Card or other peripherals
- Preconfigured dimensions (100mm × 50mm typical)
- Standard libraries linked

**Board Template:**
- Blank starting point for standalone boards
- Preconfigured dimensions (100mm × 100mm typical)
- Bus connection (A0-A15, D0-D7, control signals)
- Standard libraries linked

---

## Using Templates

### Creating New Project from Template

1. **In KiCad:**
   - File → New Project from Template
   - Browse to `Templates/<TemplateName>/`
   - Select template
   - Choose destination folder for new project
   - Click OK

2. **KiCad copies template** to new location

3. **Rename project:**
   - Files are copied with template name
   - Rename `.kicad_pro`, `.kicad_sch`, `.kicad_pcb` to your board name

4. **Update project metadata:**
   - Open schematic
   - Edit title block (File → Page Settings)
   - Update title, date, revision, author

5. **Begin design:**
   - Add components to schematic
   - Assign footprints
   - Update PCB from schematic
   - Route PCB

### Manual Setup (Without Template)

If templates not installed:

1. Create new KiCad project
2. Add libraries:
   - Symbol libraries: `Libraries/6502 Parts.kicad_sym`
   - Footprint libraries: `Libraries/6502 Parts.pretty/`, etc.
3. Import design rules:
   - PCB Editor → File → Board Setup → Design Rules
   - Import `.kicad_dru` file from `Production/<SimilarBoard>/`
4. Set up title block:
   - File → Page Settings
   - Enter project information

---

## Customizing Templates

To create your own templates:

1. Create a complete KiCad project (schematic + PCB)
2. Set up all libraries, design rules, and settings
3. Create generic/placeholder components (to be customized by users)
4. Save project to `Templates/<YourTemplateName>/`
5. Add `meta/info.html` file (template description for KiCad)
6. (Optional) Add preview image `meta/icon.png`

**meta/info.html example:**
```html
<!DOCTYPE HTML>
<html>
<head>
<meta charset="UTF-8">
</head>
<body>
<h1>6502 Card Template</h1>
<p>
Template for creating backplane-compatible cards. Includes standard
card edge connector, address decoding subcircuit, and project libraries.
</p>
</body>
</html>
```

---

**For more information, see:**
- [Main README](../README.md) - Project overview
- [Hardware README](../Hardware/README.md) - Hardware design conventions
- [Libraries README](../Libraries/README.md) - Component libraries

---

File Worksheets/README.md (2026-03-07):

6502 Worksheets
===============

This folder contains KiCad worksheet (title block) templates for the 6502 project. Worksheets provide consistent title blocks across all schematics and PCB layouts, including project information, revision history, and branding.

---

## Overview

KiCad worksheets define the border and title block that appear on schematics and PCB layouts. Custom worksheets ensure:
- Consistent branding (project name, logo)
- Standard metadata fields (title, date, revision, author)
- Professional documentation appearance
- Revision tracking

---

## Worksheet Contents

Worksheets (.kicad_wks files) typically include:

**Border:**
- Page outline (A4, A3, Letter, etc.)
- Alignment marks

**Title Block Fields:**
- **Title**: PCB/schematic name (e.g., "Serial Card Rev 1.0")
- **Date**: Creation/modification date
- **Revision**: Version number (Rev 1.0, Rev 1.1, etc.)
- **Author**: Designer name
- **Company/Project**: "6502 Project" or branding
- **Sheet**: Sheet number (for multi-sheet schematics)

**Logos:**
- Project logo
- Designer logo or branding

---

## Using Worksheets

### Applying to Project

**Method 1: Project Settings**

1. Open KiCad project
2. Schematic Editor or PCB Editor
3. File → Page Settings
4. Click "Browse Worksheets"
5. Select `.kicad_wks` file from this folder
6. Click OK

**Method 2: Copy to Project Folder**

1. Copy `.kicad_wks` file to project folder
2. KiCad will auto-detect and use it (if properly named)

### Updating Metadata

1. File → Page Settings
2. Update fields:
   - **Title**: Board/schematic name
   - **Date**: Current date (or auto-update)
   - **Revision**: Current revision (e.g., "1.1")
   - **Author**: Your name
3. Click OK

---

## Customizing Worksheets

### Editing Worksheet

1. Tools → Worksheet Editor (from KiCad main window)
2. File → Open → select `.kicad_wks` file
3. Modify:
   - Add/remove text fields
   - Change logo images
   - Adjust layout and positioning
   - Modify border style
4. File → Save

**Common Customizations:**
- Add company logo
- Change border thickness/style
- Add custom fields (part number, approver, etc.)
- Adjust text size/font
- Reposition title block elements

### Adding Logos

1. Prepare logo image (PNG or bitmap, high resolution)
2. In Worksheet Editor:
   - Place → Bitmap
   - Click to place
   - Right-click → Properties
   - Browse to image file
   - Adjust size and position
3. Save worksheet

---

## Best Practices

**Revision Tracking:**
- Increment revision number with each significant change
- Update date when revision changes
- Document changes in schematic notes or separate changelog

**Consistency:**
- Use same worksheet across all project boards for consistency
- Update all boards to new worksheet when revising

**Printing:**
- Verify title block legibility when printing
- Ensure logos don't interfere with schematic content
- Use appropriate page size for board complexity

---

**For more information, see:**
- [Main README](../README.md) - Project overview
- [KiCad Worksheet Editor](https://docs.kicad.org/7.0/en/kicad/kicad.html#page-layout-editor) - Official documentation

---

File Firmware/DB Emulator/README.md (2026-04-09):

# DB Emulator

A 65C02 CPU emulator firmware for the Teensy 4.1 microcontroller. This project provides a complete hardware-accelerated 65C02 emulation platform with support for RAM, ROM, cartridge loading, I/O devices, and network control.

## Overview

DB Emulator transforms a Teensy 4.1 into a powerful 65C02 computer system emulator. It emulates the complete 65C02 CPU instruction set, memory management, and provides hardware interfaces for keyboards, joysticks, and network connectivity. The emulator can be controlled via serial terminal or through the embedded [web interface](html/README.md). Audio (SID) and video (TMS9918A) are streamed over USB to the browser for real-time rendering.

### Features

- **Complete 65C02 CPU Emulation**: Accurate cycle-by-cycle emulation using [vrEmu6502](https://github.com/visrealm/vrEmu6502)
- **Memory Management**: 
  - Base RAM: up to 32KB (configurable)
  - Banked RAM: 32KB (default), up to 512KB with PSRAM installed
  - ROM support (up to 24KB)
  - Cartridge loading (16KB)
- **I/O Support**:
  - USB Keyboard input
  - USB Joystick support (Xbox 360/One controllers)
  - Sound Card (SID — MOS 6581 emulation, streamed to web interface)
  - Video Card (TMS9918A emulation, streamed to web interface)
- **Storage**:
  - SD card support for loading ROMs, cartridges, and programs
  - Memory snapshot functionality
- **Network Features**:
  - Ethernet connectivity via [QNEthernet](https://github.com/ssilverman/QNEthernet)
  - mDNS discovery (hostname: `6502.local`)
  - Embedded web server with REST API
  - Embedded web control interface (served from SD card)
- **Audio/Video Streaming**:
  - SID register writes streamed over USB to browser for Web Audio API synthesis
  - TMS9918A register writes streamed over USB to browser for canvas rendering
  - Real-time AV via Web Serial API (Chrome or Edge required)
- **Browser Keyboard Input**: Forwards keyboard events from the web interface to the emulator via REST API
- **Control Options**:
  - Serial terminal interface (115200 baud)
  - Physical buttons (Run/Stop, Step, Reset, Frequency)
  - Web API control
- **Variable Clock Speed**: Adjustable CPU frequency from very slow to maximum speed
- **Real-Time Clock**: TimeLib integration for timestamped operations

## Prerequisites

### Hardware Requirements

- **Teensy 4.1** microcontroller
- **Ethernet module** (built-in on Teensy 4.1)
- **MicroSD card** (optional, for loading ROMs/programs)
- **Development board** compatible with one of the supported configurations
- **USB cable** for programming and serial communication
- **Optional**:
  - USB keyboard
  - USB joystick (Xbox 360/One)
  - PSRAM chip (for extended memory support)

### Software Requirements

- **PlatformIO Core** or **PlatformIO IDE** (VS Code extension)
- **Python 3.x** (usually installed with PlatformIO)
- **Git** (for cloning dependencies)
- **Chromium-based browser** (Chrome or Edge) required for audio/video streaming via Web Serial API
- **Serial terminal software** (optional):
  - CoolTerm (recommended)
  - Arduino Serial Monitor
  - PlatformIO Serial Monitor
  - screen/minicom (Linux/macOS)

### Development Tools (Optional)

- **Visual Studio Code** with PlatformIO extension
- **Teensy Loader Application** (for manual flashing)

## Installation

### 1. Install PlatformIO

#### Option A: PlatformIO IDE (Recommended)

1. **Install Visual Studio Code** from [code.visualstudio.com](https://code.visualstudio.com/)

2. **Install PlatformIO IDE extension**:
   - Open VS Code
   - Go to Extensions (Ctrl+Shift+X / Cmd+Shift+X)
   - Search for "PlatformIO IDE"
   - Click Install

#### Option B: PlatformIO Core (Command Line)

```bash
# macOS/Linux
python3 -c "$(curl -fsSL https://raw.githubusercontent.com/platformio/platformio/master/scripts/get-platformio.py)"

# Or using pip
pip install -U platformio
```

### 2. Clone or Navigate to Project

```bash
cd /path/to/6502/Firmware/DB\ Emulator
```

### 3. Install Dependencies

PlatformIO will automatically install the required libraries on first build:

- **[QNEthernet](https://github.com/ssilverman/QNEthernet)** (v0.27.0+): Ethernet library for Teensy 4.1
- **[ArduinoJson](https://github.com/bblanchon/ArduinoJson)** (v7.0.4+): JSON parsing and generation
- **[AsyncWebServer_Teensy41](https://github.com/khoih-prog/AsyncWebServer_Teensy41)** (v1.7.0+): Asynchronous web server

Additional dependencies included in the project:
- **[vrEmu6502](https://github.com/visrealm/vrEmu6502)**: 6502 CPU emulator core (included in `lib/6502/vrEmu6502/`)
- **TimeLib**: Real-time clock support
- **Bounce2**: Button debouncing library
- **SD**: SD card file system
- **EEPROM**: Non-volatile storage
- **USBHost_t36**: USB host support for Teensy

## Configuration

### Build Flags

You can enable/disable features by uncommenting build flags in `platformio.ini`:

```ini
build_flags = 
    -D USB_TRIPLE_SERIAL    ; Enable triple serial ports (SerialUSB1 + SerialUSB2 for AV streaming)
    ; -D MOUSE_DEBUG        ; Enable mouse debugging output
    ; -D JOYSTICK_DEBUG     ; Enable joystick debugging output
    ; -D KEYBOARD_DEBUG     ; Enable keyboard debugging output
    -D MEM_EXTMEM           ; Use external PSRAM
```

### SD Card Setup (Optional)

1. **Format SD card** as FAT32
2. **Create directories** on the SD card:
   ```
   /ROMs/       - BIOS and operating system ROMs
   /Carts/      - Cartridge images
   /Programs/   - User programs
   /Snapshots/  - Memory snapshots
   /WWW/        - Embedded web application (See README in /html folder)
   ```
3. **Place ROM or PRG files** (.bin or .prg format) in appropriate directories

**Auto-boot Configuration**:
- Place `BIOS.bin` in the `ROMs` directory for automatic loading

## Building and Uploading

### Using PlatformIO IDE (VS Code)

1. **Open the project** in VS Code (File → Open Folder)

2. **Build the project**:
   - Click the ✓ (Build) button in the status bar
   - Or: Terminal → Run Build Task
   - Or: Press `Ctrl+Alt+B` / `Cmd+Alt+B`

3. **Upload to Teensy**:
   - Connect Teensy 4.1 via USB
   - Click the → (Upload) button in the status bar
   - Or: Use the upload task from the command palette
   - The Teensy will automatically enter bootloader mode

### Using PlatformIO Core (Command Line)

```bash
# Build for DevBoard 1
platformio run -e devboard

# Upload to Teensy
platformio run -e devboard --target upload

# Build and upload
platformio run -e devboard -t upload

# Open serial monitor
platformio device monitor -b 115200

# Build, upload, and monitor
platformio run -e devboard -t upload && platformio device monitor -b 115200
```

### Manual Upload with Teensy Loader

1. Build the firmware using PlatformIO
2. Locate the compiled `.hex` file in `.pio/build/devboard_X/firmware.hex`
3. Open Teensy Loader application
4. Load the `.hex` file
5. Press the button on the Teensy to enter bootloader mode
6. Click "Program" in Teensy Loader

## Usage

### Serial Terminal Control

Connect to the Teensy via serial terminal at **115200 baud**:

```bash
# Using PlatformIO
platformio device monitor -b 115200

# Using screen (macOS/Linux)
screen /dev/ttyACM0 115200

# Using CoolTerm
# Set port to Teensy, baud rate to 115200
```

### Serial Commands

Once connected, you'll see the emulator banner and status. Available commands:

#### Execution Control
- **`R`** - Run/Stop: Toggle emulator execution
- **`S`** - Step: Execute one CPU instruction (when stopped)
- **`K`** - Tick: Execute one clock cycle (when stopped)
- **`T`** - Reset: Hardware reset of the emulator

#### Memory Management
- **`A`** - Toggle RAM: Enable/disable RAM
- **`O`** - Toggle ROM: Enable/disable ROM
- **`L`** - Toggle Cart: Enable/disable cartridge

#### File Management
- **`M`** - List ROMs: Show available ROM files from SD card
- **`C`** - List Carts: Show available cartridge files
- **`U`** - List Programs: Show available user programs
- **`0-7`** - Load File: Load the selected file (after listing)
- **`[`** - Previous Page: Navigate file lists
- **`]`** - Next Page: Navigate file lists

#### Configuration
- **`+`** - Increase Frequency: Speed up CPU clock
- **`-`** - Decrease Frequency: Slow down CPU clock

#### Information & Debugging
- **`F`** - Info: Display system information and status
- **`G`** - Log: Show current CPU state
- **`P`** - Snapshot: Save current RAM state to SD card

### Web Control Interface

1. **Ensure Teensy is connected** to your network via Ethernet

2. **Note the IP address** from the serial output on boot

3. **Access via mDNS** (if supported):
   ```
   http://6502.local/
   ```

4. **Or access via direct IP**:
   ```
   http://192.168.1.XXX/
   ```

5. **Use the web interface** to control the emulator (see [Web Interface documentation](html/README.md))

#### Audio/Video Streaming

The Teensy streams SID and TMS9918A register writes over USB (SerialUSB2) to the browser for real-time audio synthesis and video rendering.

- The Teensy must be USB-connected to the same machine running the browser
- Click **Connect AV** in the VIDEO panel to open the USB serial link
- Requires **Chrome or Edge** (Web Serial API); requires HTTPS or localhost
- Audio and video are rendered entirely in the browser; the Teensy streams register writes only
- Click **Mute** to toggle audio output

**Alternative: External Hardware Rendering**

In addition to browser-based AV streaming via USB, the emulator supports streaming AV data to external hardware devices via the **HWSERIAL** interface. This allows connecting dedicated hardware (such as external sound synthesizers or video display units) for rendering audio and video output. The HWSERIAL port uses the same AV streaming protocol as SerialUSB2, enabling hardware devices to receive SID and TMS9918A register writes for real-time rendering.

### Physical Controls

If your development board has physical buttons:

- **INT/CLK Button**: Change clock frequency
- **STEP Button**: Execute one instruction
- **RUN/STOP Button**: Toggle execution
- **RESET Button**: Hardware reset (DevBoard 1 only)

## API Endpoints

The embedded web server provides RESTful API endpoints:

### GET /info
Returns system information and CPU state in JSON format:
```json
{
  "address": 65535,
  "cartEnabled": true,
  "cartFile": "game.bin",
  "cpuAccumulator": 0,
  "cpuOpcodeCycle": 0,
  "cpuPC": 65520,
  "cpuStackPointer": 255,
  "cpuStatus": 32,
  "cpuX": 0,
  "cpuY": 0,
  "data": 234,
  "freqLabel": "1 MHz",
  "freqPeriod": 1,
  "ipAddress": "192.168.1.100",
  "isRunning": false,
  "lastSnapshot": 1234567890,
  "programFile": "",
  "romFile": "BIOS.bin",
  "rtc": 1737590400,
  "rw": 1,
  "soundEnabled": true,
  "version": "1.0",
  "videoEnabled": true,
  "avStreamConnected": false
}
```

### GET /memory?target={ram|rom}&page={n}
Returns memory dump (1024 bytes per page):
- `target`: `ram` or `rom`
- `page`: Page number (0-31 for RAM, 0-23 for ROM)
- Optional: `formatted=true` for hex-formatted output

### GET /storage?target={rom|cart|program}&page={n}
Lists files in storage:
- `target`: `rom`, `cart`, or `program`
- `page`: Page number for pagination
- Returns JSON array of filenames

### GET /load?target={rom|cart|program}&filename={name}
Loads a file from SD card:
- `target`: Memory region to load into
- `filename`: Name of file to load

### GET /control?command={cmd}
Executes control command:
- `command`: Single letter command (same as serial commands)
- Examples: `r` (run/stop), `s` (step), `t` (reset), `+` (inc freq)

### GET /keyboard?action={down|up}&keycode={XX}
Forwards browser keyboard events to the emulator:
- `action`: `down` or `up` (required; returns 400 if missing or invalid)
- `keycode`: 1–2 character hex string representing a USB HID keycode (e.g. `04` for 'a') (required; returns 400 if missing)
- Returns 200 on success

**Note:** Audio/video data flows via Web Serial API (USB SerialUSB2), not REST. See the Audio/Video Streaming section above.

## Troubleshooting

### Build Errors

**Problem**: Library dependencies not found

**Solutions**:
- Run `platformio lib install` to fetch dependencies
- Delete `.pio` folder and rebuild
- Check internet connection for library downloads

**Problem**: Compilation errors with PSRAM

**Solutions**:
- Ensure `MEM_EXTMEM` flag matches your hardware configuration
- Check PSRAM wiring and connections

### Upload Issues

**Problem**: Teensy not detected

**Solutions**:
- Install Teensy Udev rules (Linux) or drivers (Windows)
- Press the physical button on Teensy to enter bootloader mode
- Try a different USB cable or port
- Check `platformio device list` to see connected devices

**Problem**: Upload fails or times out

**Solutions**:
- Manually press Teensy button during upload
- Use Teensy Loader application instead
- Update Teensy udev rules/drivers

### Runtime Issues

**Problem**: Emulator doesn't start or crashes

**Solutions**:
- Check serial output for error messages
- Verify SD card is properly formatted (FAT32)
- Ensure ROM files are valid 65C02 binaries
- Reset via serial command `T` or power cycle

**Problem**: Network features not working

**Solutions**:
- Verify Ethernet cable is connected
- Check DHCP is available on your network
- Look for IP address in serial output
- Try accessing via direct IP instead of mDNS
- Ensure firewall allows port 80

**Problem**: USB devices not recognized

**Solutions**:
- Check device compatibility (Xbox controllers work best)
- Try different USB ports on the hub
- Verify USB host power supply is adequate
- Enable debug flags to see USB enumeration

**Problem**: SD card files not loading

**Solutions**:
- Verify SD card is formatted as FAT32
- Check file permissions and naming
- Ensure directories exist: `/ROMs/`, `/Carts/`, `/Programs/`
- Files should have `.bin` extension
- Try reinserting SD card

### AV Streaming Issues

**Problem**: Connect AV button not visible

**Solutions**:
- Must use Chrome or Edge (Web Serial API is not supported in Firefox or Safari)
- The Web Serial API requires a **secure context**. When accessing via `http://6502.local` (plain HTTP), Chrome hides the API even though your browser supports it. Choose one of the following workarounds:

  **Option 1 — Chrome flag (easiest, for local development)**
  1. In Chrome, navigate to `chrome://flags/#unsafely-treat-insecure-origin-as-secure`
  2. Add `http://6602.local` to the list and set it to **Enabled**
  3. Relaunch Chrome

  **Option 2 — Serve over HTTPS**
  Configure the Teensy's web server with a self-signed TLS certificate. The browser will show a certificate warning; accept it once and the API will become available.

  **Option 3 — Local proxy via localhost**
  Run a local reverse proxy (e.g. `nginx` or `caddy`) that forwards `http://localhost` to `http://6602.local`. Because `localhost` is always treated as a secure context, the Web Serial API will be available.

**Problem**: No video or audio after connecting

**Solutions**:
- Verify USB cable supports data (not charge-only)
- Check `SerialUSB2` is initialized (`USB_TRIPLE_SERIAL` build flag must be set)
- Try disconnecting and reconnecting

**Problem**: Audio glitches or dropouts

**Solutions**:
- Lower the CPU frequency
- Ensure the browser tab is not throttled or backgrounded
- Close other audio-intensive applications

## Development

### Project Structure

```
DB Emulator/
├── lib/
│   └── 6502/                 # Custom 6502 emulation library
│       ├── 6502.h            # Main library header
│       ├── constants.h       # System constants
│       ├── macros.h          # Utility macros
│       ├── pins.h            # Pin definitions
│       ├── CPU/              # CPU emulator wrapper
│       │   └── [vrEmu6502](https://github.com/visrealm/vrEmu6502)/        # Core 6502 emulator
│       ├── RAM/              # RAM emulation
│       ├── ROM/              # ROM emulation
│       ├── Cart/             # Cartridge support
│       └── IO/               # I/O device emulation
│           ├── AVStream.h    # AV streaming protocol (SerialUSB2)
│           ├── SoundCard.*   # SID (MOS 6581) emulation
│           └── VideoCard.*   # TMS9918A emulation
├── src/
│   └── main.cpp              # Main firmware code
├── include/                  # Additional headers
├── test/                     # Unit tests
├── html/                     # Web interface source
└── platformio.ini            # PlatformIO configuration
```

### Adding Features

1. **New I/O Device**: Extend the `IO` class in `lib/6502/IO/`
2. **Memory Extensions**: Modify memory maps in `constants.h`
3. **New Commands**: Add cases to `onCommand()` in `main.cpp`
4. **Web API**: Add routes in `initServer()` function

### Memory Map

```
$0000 - $00FF : Zero Page
$0100 - $01FF : Stack
$0200 - $02FF : Input Buffer
$0300 - $03FF : Kernal Variables
$0400 - $07FF : User Variables
$0800 - $7FFF : Program RAM (30KB)
$8000 - $83FF : I/O Slot 0 (1KB) - RAM Card
$8400 - $87FF : I/O Slot 1 (1KB) - RAM Card
$8800 - $8BFF : I/O Slot 2 (1KB) - RTC Card
$8C00 - $8FFF : I/O Slot 3 (1KB) - Storage Card
$9000 - $93FF : I/O Slot 4 (1KB) - Serial Card
$9400 - $97FF : I/O Slot 5 (1KB) - GPIO Card
$9800 - $9BFF : I/O Slot 6 (1KB) - Sound Card (SID)
$9C00 - $9FFF : I/O Slot 7 (1KB) - Video Card (TMS9918A)
$A000 - $BFFF : ROM (8KB)
$C000 - $FFFF : ROM/Cartridge (16KB)
```

**Note**: The cartridge space ($C000-$FFFF) can be used for either ROM or cartridge data depending on configuration.

### Debug Output

Enable debug flags in `platformio.ini` for verbose logging:

```ini
-D KEYBOARD_DEBUG    ; Log all keyboard events
-D JOYSTICK_DEBUG    ; Log joystick button presses
```

## Performance

- **Maximum Emulation Speed**: 1 MHz (Teensy 4.1 @ 600 MHz)
- **Accurate Timing**: Down to microsecond precision
- **Memory**: 32KB base RAM + 32KB banked RAM (default), up to 544KB total with PSRAM (32KB base + 512KB banked)
- **Storage**: Limited only by SD card size

## Related Documentation

- [Web Interface (html/)](html/README.md)
- [PlatformIO Documentation](https://docs.platformio.org/)
- [Teensy 4.1 Documentation](https://www.pjrc.com/store/teensy41.html)
- [6502 CPU Reference](http://www.6502.org/)

## License

See LICENSE file in project root.

## Credits

- Created by A.C. Wright © 2024
- Based on [vrEmu6502](https://github.com/visrealm/vrEmu6502) by Troy Schrapel
- Uses [QNEthernet](https://github.com/ssilverman/QNEthernet) library by Shawn Silverman
- Uses [AsyncWebServer_Teensy41](https://github.com/khoih-prog/AsyncWebServer_Teensy41) library by Khoi Hoang
- Uses [ArduinoJson](https://github.com/bblanchon/ArduinoJson) library by Benoit Blanchon

## Version History

- **v1.0.0**: Initial release with full 65C02 emulation, network support, and web API

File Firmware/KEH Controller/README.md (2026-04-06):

# KEH Controller

## Overview

The KEH (Keyboard Encoder Helper) Controller is firmware for the ATMega1284P microcontroller that provides dual keyboard input support for 6502-based computer systems. It can simultaneously handle both PS/2 keyboard input and custom keyboard matrix input, converting keypresses to ASCII codes and outputting them through a 6522 VIA (Versatile Interface Adapter) interface.

## Features

- **Dual Input Support**: Handles both PS/2 keyboards and 8x8 keyboard matrix simultaneously
- **ASCII Conversion**: Converts PS/2 scancodes and matrix keypresses to ASCII characters
- **Always Uppercase Letters**: Letters are always output as uppercase ASCII regardless of modifiers
- **Modifier Keys**: Shift (symbols/numbers only) and Ctrl (control codes)
- **Buffered Input**: Uses circular buffers to prevent data loss during rapid typing
- **Debounced Matrix Scanning**: Hardware debouncing for reliable matrix keyboard operation
- **Enable/Disable Control**: Independent enable signals for PS/2 and matrix inputs

## Hardware Connections

### ATMega1284P Pin Assignments

#### VIA PORT A (Pins 24-31)
Used for row scanning (matrix mode) or ASCII output (PS/2 mode):
- PA0 (Pin 24) - VIA_PA0 / Row 0 / Data Bit 0
- PA1 (Pin 25) - VIA_PA1 / Row 1 / Data Bit 1
- PA2 (Pin 26) - VIA_PA2 / Row 2 / Data Bit 2
- PA3 (Pin 27) - VIA_PA3 / Row 3 / Data Bit 3
- PA4 (Pin 28) - VIA_PA4 / Row 4 / Data Bit 4
- PA5 (Pin 29) - VIA_PA5 / Row 5 / Data Bit 5
- PA6 (Pin 30) - VIA_PA6 / Row 6 / Data Bit 6
- PA7 (Pin 31) - VIA_PA7 / Row 7 / Data Bit 7

#### VIA PORT B (Pins 0-7)
Used for column scanning (matrix mode) or ASCII output (matrix output):
- PB0 (Pin 0) - VIA_PB0 / Column 0 / Data Bit 0
- PB1 (Pin 1) - VIA_PB1 / Column 1 / Data Bit 1
- PB2 (Pin 2) - VIA_PB2 / Column 2 / Data Bit 2
- PB3 (Pin 3) - VIA_PB3 / Column 3 / Data Bit 3
- PB4 (Pin 4) - VIA_PB4 / Column 4 / Data Bit 4
- PB5 (Pin 5) - VIA_PB5 / Column 5 / Data Bit 5
- PB6 (Pin 6) - VIA_PB6 / Column 6 / Data Bit 6
- PB7 (Pin 7) - VIA_PB7 / Column 7 / Data Bit 7

#### Control Signals
- Pin 8 (VIA_CA1) - PS/2 Data Ready strobe (output)
- Pin 9 (VIA_CA2) - PS/2 Enable (input, active low)
- Pin 10 (PS2CLK) - PS/2 Clock input
- Pin 11 (PS2DATA) - PS/2 Data input
- Pin 12 (VIA_CB1) - Matrix Data Ready strobe (output)
- Pin 13 (VIA_CB2) - Matrix Enable (input, active low)

### PS/2 Keyboard Interface

Connect a PS/2 keyboard to:
- **CLK**: Pin 10 (PS2CLK)
- **DATA**: Pin 11 (PS2DATA)
- **VCC**: +5V
- **GND**: Ground

### Keyboard Matrix Interface

The firmware supports an 8x8 keyboard matrix (64 keys maximum):
- **Rows**: Connected to PA0-PA7 (Pins 24-31)
- **Columns**: Connected to PB0-PB7 (Pins 0-7)

Each key connects a row to a column when pressed. The matrix is scanned with rows driven low and columns read with pull-ups.

## Keyboard Matrix Layout

```
       PB0    PB1    PB2    PB3    PB4    PB5    PB6    PB7
PA0:    `      1      2      3      4      5      6      7
PA1:    8      9      0      -      =      BS     ESC    TAB
PA2:    Q      W      E      R      T      Y      U      I
PA3:    O      P      [      ]      \      INS    CAPS   A
PA4:    S      D      F      G      H      J      K      L
PA5:    ;      '    ENTER   DEL   SHIFT    Z      X      C
PA6:    V      B      N      M      ,      .      /      UP
PA7:  CTRL   MENU    ALT   SPACE   FN    LEFT   DOWN  RIGHT
```

**Special Keys:**
- BS = Backspace (0x08)
- ESC = Escape (0x1B)
- TAB = Tab (0x09)
- INS = Insert (0x1A)
- DEL = Delete (0x7F)
- ENTER = Enter (0x0D)
- Arrow keys: UP (0x1E), LEFT (0x1C), DOWN (0x1F), RIGHT (0x1D)

**Ignored Keys:**
- Caps Lock, Menu/GUI, Alt, Fn — produce no output and track no state

## Operation Modes

### PS/2 Mode
When VIA_CA2 (Pin 9) is pulled LOW:
- PS/2 keyboard is enabled
- Scancodes are converted to ASCII
- Output appears on PORT A (PA0-PA7)
- VIA_CA1 pulses low when data is ready

### Matrix Mode
When VIA_CB2 (Pin 13) is pulled LOW:
- Matrix keyboard is enabled
- Matrix is scanned every 10ms
- Keys are debounced (stable for 2 scans)
- Output appears on PORT B (PB0-PB7)
- VIA_CB1 pulses low when data is ready

### Dual Mode
Both keyboards can operate simultaneously if both enable signals are active.

## ASCII Character Mapping

### Modifier Priority

1. **Ctrl** — If held, produce control code. Shift is ignored.
2. **Shift** — If held (no Ctrl), produce shifted symbol. Letters unaffected.
3. **Base** — No modifier: produce base ASCII (letters always uppercase).

### Control Characters (Ctrl+Key)

- Ctrl+2 = 0x00 (NUL)
- Ctrl+A-Z = 0x01-0x1A
- Ctrl+[ = 0x1B (ESC)
- Ctrl+\ = 0x1C (FS)
- Ctrl+] = 0x1D (GS)
- Ctrl+6 = 0x1E (RS)
- Ctrl+- = 0x1F (US)

### Shifted Symbols

Shift only affects number and symbol keys (not letters):

| Base | Shifted | | Base | Shifted |
|---|---|-|---|---|
| 1 → ! | 2 → @ | | 3 → # | 4 → $ |
| 5 → % | 6 → ^ | | 7 → & | 8 → * |
| 9 → ( | 0 → ) | | - → _ | = → + |
| [ → { | ] → } | | \ → \| | ; → : |
| ' → " | , → < | | . → > | / → ? |
| ` → ~ | | | | |

### Printable Characters

Letters are always uppercase (A-Z). Numbers, symbols, space, and navigation keys follow standard ASCII.

## Build Instructions

### Prerequisites

1. **Install PlatformIO**
   ```bash
   # Using pip
   pip install platformio
   
   # Or install PlatformIO IDE extension for VS Code
   ```

2. **Install MiniPro Programmer Software** (for uploading)
   ```bash
   # macOS (using Homebrew)
   brew install minipro
   
   # Linux
   sudo apt-get install minipro
   
   # Or build from source: https://gitlab.com/DavidGriffith/minipro
   ```

### Building the Firmware

1. **Navigate to the project directory:**
   ```bash
   cd "Firmware/KEH Controller"
   ```

2. **Build the firmware:**
   ```bash
   # Build for ATMega1284P (default)
   pio run -e atmega1284p
   
   # Or build for ATMega1284
   pio run -e atmega1284
   ```

3. **Build output:**
   The compiled firmware will be located at:
   ```
   .pio/build/atmega1284p/firmware.hex
   ```

### Uploading the Firmware

The project uses a MiniPro TL866 programmer for uploading.

1. **Connect the MiniPro programmer** to your ATMega1284P chip

2. **Upload firmware and fuses:**
   ```bash
   # Upload to ATMega1284P
   pio run -e atmega1284p -t upload
   
   # Or upload to ATMega1284
   pio run -e atmega1284 -t upload
   ```

3. **Manual upload (if needed):**
   ```bash
   # Flash the program
   minipro -p "ATMEGA1284P@DIP40" -c code -w .pio/build/atmega1284p/firmware.hex
   
   # Flash the fuses and lock bits
   minipro -p "ATMEGA1284P@DIP40" -c config -w fuses.cfg --fuses --lock
   ```

## Fuse Configuration

The `fuses.cfg` file contains the ATMega1284P fuse settings:

```properties
lfuse = 0xff   # Low fuse
hfuse = 0xff   # High fuse  
efuse = 0xff   # Extended fuse
lock = 0xff    # Lock bits (unprogrammed)
```

**Fuse Settings:**
- **Low Fuse (0xFF)**: Full-swing crystal oscillator, no clock divide
- **High Fuse (0xFF)**: Default settings
- **Extended Fuse (0xFF)**: Default settings
- **Lock Bits (0xFF)**: No memory lock protection

⚠️ **Warning**: Incorrect fuse settings can brick your microcontroller. Verify fuse values are appropriate for your hardware configuration before programming.

## Dependencies

The firmware requires the following library (automatically installed by PlatformIO):

- **CircularBuffer** (v1.4.0+) by Roberto Lo Giacco
  - Provides interrupt-safe circular buffers for keyboard data

## Project Structure

```
KEH Controller/
├── platformio.ini          # PlatformIO configuration
├── fuses.cfg              # AVR fuse configuration
├── src/
│   └── main.cpp           # Main firmware source code
├── include/               # Header files (if any)
├── lib/                   # Local libraries
└── test/                  # Unit tests
```

## Troubleshooting

### Build Issues

**Problem**: PlatformIO not found
```bash
# Solution: Install or update PlatformIO
pip install -U platformio
```

**Problem**: Library dependency errors
```bash
# Solution: Clean and rebuild
pio run -t clean
pio run
```

### Upload Issues

**Problem**: MiniPro not found
```bash
# Solution: Ensure minipro is installed and in PATH
which minipro
```

**Problem**: Chip not detected
- Check that the chip is properly seated in the programmer
- Verify you're using the correct chip model (ATMEGA1284P vs ATMEGA1284)
- Check for proper power supply to the programmer

### Runtime Issues

**Problem**: No keyboard response
- Verify enable signals (CA2/CB2) are at correct logic levels
- Check PS/2 clock and data connections
- Verify matrix keyboard connections
- Ensure VIA interface connections are correct

**Problem**: Incorrect characters output
- Check for proper pull-up resistors on PS/2 lines
- Verify keyboard matrix wiring matches the defined layout
- Test with a known-good PS/2 keyboard

## License

See the main repository LICENSE file for licensing information.

## Contributing

This firmware is part of the 6502 computer project. Contributions and improvements are welcome through the main repository.

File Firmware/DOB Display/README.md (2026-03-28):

# DOB Display

DOB Display is the AV output firmware for the DOB (Dev Output Board). It emulates a TMS9918A Video Display Processor and a MOS 6581 SID audio synthesizer, driven in real time by AV packets from the DB Emulator over high-speed hardware serial.

## Features

- **TMS9918A VDP Emulator** - Full software emulation of all four TMS9918A display modes
- **320x240 Display with Borders** - 256×192 active area centered in a 320×240 canvas with TMS9918-style color borders
- **8-bit Indexed Framebuffer** - 76,800-byte indexed framebuffer with 16-entry RGB565 TMS9918A palette; half the RAM of a 16-bit framebuffer
- **SID Audio Emulator** - 3-voice MOS 6581 software synthesizer with triangle, sawtooth, pulse, and noise waveforms and full ADSR envelopes, output via 8-bit PWM at 44.1 kHz
- **AV Packet Protocol** - 4-byte AV packet stream received at 6 Mbps over hardware UART (Serial1) from the DB Emulator
- **Dual Serial Input** - USB Serial accepted as a fallback for testing without hardware
- **~60 FPS Rendering** - Full-frame re-render from VRAM state every ~17 ms

## Hardware

- **MCU**: Teensy 4.0 (600 MHz ARM Cortex-M7)
- **Display**: ILI9341 320×240 TFT LCD
- **Audio**: 8-bit PWM output (pin 14) into passive speaker via RC low-pass filter
- **Communication**: USB Serial + hardware UART Serial1 at 6 Mbps

### Audio Hardware Notes

The audio output on pin 14 is a PWM signal with a ~2.34 MHz carrier. To drive a small 8Ω speaker you need an RC low-pass filter between pin 14 and the speaker:

- **R**: 1 kΩ
- **C**: 3.3 nF to ground (f_c ≈ 48 kHz)

This removes the PWM carrier while passing the full audio band.

## AV Packet Format

All communication uses 4-byte packets: `{ 0xAA, type, a, b }`

| Type | Value | Description |
|---|---|---|
| `AV_TYPE_SOUND` | `0x01` | SID register write: `a` = register (0x00–0x1F), `b` = value |
| `AV_TYPE_VIDEO_DATA`  | `0x02` | VRAM data write at current address pointer (auto-increments) |
| `AV_TYPE_VIDEO_REG` | `0x03` | TMS9918A register write: `a` = register (0–7), `b` = value |
| `AV_TYPE_VIDEO_ADDR`  | `0x04` | Set VRAM address: `a` = high 6 bits, `b` = low 8 bits |
| `AV_TYPE_RESET` | `0xFE` | Reset all VRAM, TMS9918A registers, SID state, and address pointer |

## Display Modes

| M1 | M2 | M3 | Mode |
|----|----|----|---|
| 0  | 0  | 0  | Graphics I — 32×24 tiles, per-8-char color |
| 0  | 0  | 1  | Graphics II — 32×24 tiles, per-pixel color |
| 1  | 0  | 0  | Text — 40×24 tiles, 6px wide, R7 fg/bg |
| 0  | 1  | 0  | Multicolor — 64×48 fat pixels (4×4 each) |

Sprites are rendered in all modes except Text (up to 32 sprites, max 4 visible per scanline, 8×8 or 16×16, with optional magnification).

## Installation

### Prerequisites

- [PlatformIO](https://platformio.org/) - Cross-platform build system
- [Visual Studio Code](https://code.visualstudio.com/) (recommended) with PlatformIO extension
- Teensy 4.0 board
- ILI9341 compatible TFT display

### Hardware Setup

Connect the display and speaker to your Teensy 4.0 according to the pin definitions in `lib/DOBDisplay/pins.h`.

## Building and Uploading

### Using PlatformIO CLI

1. Clone the repository:
   ```bash
   git clone <repository-url>
   cd "DOB Display"
   ```

2. Build the project:
   ```bash
   pio run
   ```

3. Upload to Teensy 4.0:
   ```bash
   pio run --target upload
   ```

### Using VS Code

1. Open the project folder in VS Code
2. Click the PlatformIO icon in the sidebar
3. Under "Project Tasks" → "teensy" → "General":
   - Click "Build" to compile
   - Click "Upload" to flash the firmware

## Project Structure

```
DOB Display/
├── src/
│   └── main.cpp              # Main firmware — VDP emulator, SID engine, AV packet processing
├── lib/
│   └── DOBDisplay/
│       ├── constants.h       # AV protocol constants, display geometry, TMS9918A RGB565 palette
│       ├── pins.h            # Hardware pin assignments
│       └── DOBDisplay.h # Main library header
├── platformio.ini            # Build configuration
└── README.md
```

## License

See [LICENSE](LICENSE) for details.

## Author

Created by A.C. Wright © 2026

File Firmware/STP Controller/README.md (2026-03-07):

# STP Controller

An SPI Controller Peripheral for 6502-based computer systems. This firmware runs on an ATmega328P microcontroller and acts as a memory-mapped I/O device, providing the 6502 CPU with access to SPI peripherals including SD cards, Flash memory, and external SPI devices.

## Features

- **Memory-Mapped I/O Interface**: Two registers accessible from 6502 address space (DATA and CTRL)
- **Multiple SPI Devices**: Support for up to 3 SPI slave devices via chip select lines
  - CS0: SD Card
  - CS1: Flash Memory
  - CS2: External SPI Header
- **Dual Clock Speeds**: 
  - Fast mode: 4 MHz (normal operation)
  - Slow mode: 400 kHz (SD card initialization)
- **Auto-Transmit Mode**: Automatically send dummy bytes when reading data, useful for consecutive reads
- **Status Monitoring**: Real-time monitoring of BUSY, Card Detect (CD), and Write Protect (WP) flags
- **6502 Synchronization**: PHI2-synchronized interrupt-driven interface for reliable communication

## Hardware Overview

### Microcontroller
- **MCU**: ATmega328P @ DIP28 package
- **Architecture**: AVR 8-bit
- **Framework**: Arduino

### Pin Connections

| Pin Group | ATmega328P Pins | Function |
|---|---|---|
| **6502 Data Bus** | PD0-PD7 (D0-D7) | Bidirectional 8-bit data bus |
| **6502 Control** | A0 (RS0) | Register select (0=DATA, 1=CTRL) |
| | A1 (PHI2) | 6502 clock - triggers interrupt |
| | A2 (CSB) | Chip select (active low) |
| | A3 (RWB) | Read/Write signal |
| **SD Card Status** | A4 (CD) | Card detect input (active low) |
| | A5 (WP) | Write protect input (active low) |
| **SPI Interface** | 11 (MOSI) | SPI Master Out Slave In |
| | 12 (MISO) | SPI Master In Slave Out |
| | 13 (SCK) | SPI Clock |
| **Chip Selects** | 8 (CS0) | SD Card chip select |
| | 9 (CS1) | Flash Memory chip select |
| | 10 (CS2) | External SPI header chip select |

## Register Map

The STP Controller presents two 8-bit registers to the 6502:

### DATA Register ($0)
**Address Offset**: 0  
**Access**: Read/Write

| Bit 7-0 | Description |
|---|---|
| DATA[7:0] | SPI data byte to transmit or last received byte |

**Write Operation**: Initiates an SPI transfer with the written byte  
**Read Operation**: Returns the last received SPI byte. If AUTO-TX is enabled, automatically starts a new transfer with dummy byte $FF

### CTRL Register ($1)
**Address Offset**: 1  
**Access**: Read/Write (some bits read-only)

| Bit | Name | R/W | Description |
|-----|---|-----|---|
| 7 | BUSY | R | SPI transfer in progress (1=busy, 0=idle) |
| 6 | CD | R | SD Card detected (1=card present, 0=no card) |
| 5 | WP | R | Write protect status (1=protected, 0=writable) |
| 4 | SS1 | R/W | Slave select bit 1 |
| 3 | SS0 | R/W | Slave select bit 0 |
| 2 | AUTO-TX | R/W | Auto-transmit on read (1=enabled, 0=disabled) |
| 1 | SLOW CLK | R/W | SPI clock speed (1=400kHz, 0=4MHz) |
| 0 | SELECT | R/W | Enable chip select (1=active, 0=inactive) |

**Slave Select Encoding** (SS1:SS0):
- `00`: CS0 - SD Card
- `01`: CS1 - Flash Memory
- `10`: CS2 - External SPI Header
- `11`: Reserved (no device selected)

## Building the Firmware

### Prerequisites

1. **PlatformIO**: Install PlatformIO Core or PlatformIO IDE
   ```bash
   # Via pip
   pip install platformio
   
   # Or via Homebrew (macOS)
   brew install platformio
   ```

2. **MiniPro Programmer**: Required for uploading firmware
   ```bash
   # macOS
   brew install minipro
   
   # Linux
   # Follow installation instructions at: https://gitlab.com/DavidGriffith/minipro
   ```

### Build Commands

```bash
# Build for ATmega328P (default)
pio run

# Build for ATmega328 (no 'P' variant)
pio run -e atmega328

# Clean build files
pio run --target clean

# Verbose build output
pio run -v
```

### Upload Firmware

The upload process programs both the firmware and fuse settings using a MiniPro programmer:

```bash
# Upload to ATmega328P
pio run --target upload

# Upload to ATmega328
pio run -e atmega328 --target upload
```

The upload command performs two operations:
1. Programs the compiled firmware to flash memory
2. Configures fuse bits from `fuses.cfg`

### Fuse Configuration

Fuse settings are defined in `fuses.cfg`:
```
lfuse = 0xFF  # Low fuse
hfuse = 0xFF  # High fuse
efuse = 0xFF  # Extended fuse
lock = 0xFF   # Lock bits
```

**Note**: Verify fuse values match your hardware configuration before uploading. Incorrect fuse settings can brick your microcontroller.

## Usage Examples

### Example 1: Initialize SD Card

```assembly
; Set slow clock for SD card initialization
LDA #$03        ; SLOW_CLK=1, SELECT=1
STA CTRL        ; Enable CS0 (SD Card) with slow clock

; Send CMD0 (reset)
LDA #$40
JSR SPI_SEND
LDA #$00
JSR SPI_SEND
; ... (continue with initialization sequence)

; Switch to fast clock after initialization
LDA #$01        ; SLOW_CLK=0, SELECT=1
STA CTRL
```

### Example 2: Read Multiple Bytes with Auto-Transmit

```assembly
; Enable auto-transmit for faster consecutive reads
LDA #$05        ; AUTO_TX=1, SELECT=1
STA CTRL        ; CS0 active with auto-transmit

; First byte (manual trigger)
LDA #$FF
STA DATA        ; Start transfer

:WAIT1
LDA CTRL
AND #$80        ; Check BUSY flag
BNE :WAIT1

; Subsequent bytes (auto-triggered on read)
LDX #$00
:LOOP
LDA DATA        ; Reading DATA automatically sends next $FF
STA BUFFER,X    ; Store received byte
INX
CPX #$10        ; Read 16 bytes
BNE :LOOP

; Disable chip select
LDA #$00
STA CTRL
```

### Example 3: Select Flash Memory

```assembly
; Select Flash chip (CS1)
LDA #$09        ; SS1:SS0 = 01, SELECT=1
STA CTRL        ; Enable CS1 (Flash)

; Send command
LDA #$03        ; READ command
JSR SPI_SEND
; ... (continue with flash operations)
```

## Development Environment

This project is configured for development with:
- **Platform**: Atmel AVR
- **Framework**: Arduino
- **Board**: ATmega328P or ATmega328
- **Build System**: PlatformIO

## Project Structure

```
STP Controller/
├── src/
│   └── main.cpp          # Main firmware source
├── include/              # Header files (if any)
├── lib/                  # Project libraries
├── test/                 # Unit tests
├── platformio.ini        # PlatformIO configuration
├── fuses.cfg            # AVR fuse settings
├── SPI.txt              # SPI implementation notes
└── README.md            # This file
```

## Design Notes

The controller uses PHI2-synchronized interrupts to ensure proper timing with the 6502 bus. The data bus is configured as input with pull-ups by default and only switches to output mode when the 6502 performs a read operation.

SPI transfers are blocking and set the BUSY flag during operation. The 6502 software should check the BUSY flag before initiating new transfers.

The Card Detect (CD) and Write Protect (WP) inputs use internal pull-ups and are active-low, suitable for direct connection to SD card socket switches.

## References

- Inspired by the VERA SPI controller implementation (see `SPI.txt`)
- 6502 bus timing reference: [W65C02S Datasheet](http://www.westerndesigncenter.com/wdc/documentation/w65c02s.pdf)
- SD Card SPI Mode: [SD Specifications Part 1 Physical Layer Simplified Specification](https://www.sdcard.org/)

## License

See the main repository LICENSE file for details.

## Contributing

This is a personal project for a 6502-based computer system. Feel free to fork and adapt for your own hardware.

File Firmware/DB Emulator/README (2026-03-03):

# DB Emulator

A 65C02 CPU emulator firmware for the Teensy 4.1 microcontroller. This project provides a complete hardware-accelerated 65C02 emulation platform with support for RAM, ROM, cartridge loading, I/O devices, and network control.

## Overview

DB Emulator transforms a Teensy 4.1 into a powerful 65C02 computer system emulator. It emulates the complete 65C02 CPU instruction set, memory management, and provides hardware interfaces for keyboards, joysticks, and network connectivity. The emulator can be controlled via serial terminal or through the web-based [DB Control](../DB%20Control/README.md) interface.

### Features

- **Complete 65C02 CPU Emulation**: Accurate cycle-by-cycle emulation using [vrEmu6502](https://github.com/visrealm/vrEmu6502)
- **Memory Management**: 
  - Configurable RAM (up to 32KB, with optional PSRAM support)
  - ROM support (up to 24KB)
  - Cartridge loading (16KB)
- **I/O Support**:
  - USB Keyboard input
  - USB Joystick support (Xbox 360/One controllers)
- **Storage**:
  - SD card support for loading ROMs, cartridges, and programs
  - Memory snapshot functionality
- **Network Features**:
  - Ethernet connectivity via [QNEthernet](https://github.com/ssilverman/QNEthernet)
  - mDNS discovery (hostname: `6502.local`)
  - Embedded web server with REST API
  - Compatible with DB Control web interface
- **Control Options**:
  - Serial terminal interface (115200 baud)
  - Physical buttons (Run/Stop, Step, Reset, Frequency)
  - Web API control
- **Variable Clock Speed**: Adjustable CPU frequency from very slow to maximum speed
- **Real-Time Clock**: TimeLib integration for timestamped operations

### Hardware Variants

The firmware supports two development board configurations:

- **DevBoard 0** (`devboard_0`): Original development board
- **DevBoard 1** (`devboard_1`): Latest revision with improved layout and additional features (recommended)

## Prerequisites

### Hardware Requirements

- **Teensy 4.1** microcontroller
- **Ethernet module** (built-in on Teensy 4.1)
- **MicroSD card** (optional, for loading ROMs/programs)
- **Development board** compatible with one of the supported configurations
- **USB cable** for programming and serial communication
- **Optional**:
  - USB keyboard
  - USB joystick (Xbox 360/One)
  - PSRAM chip (for extended memory support)

### Software Requirements

- **PlatformIO Core** or **PlatformIO IDE** (VS Code extension)
- **Python 3.x** (usually installed with PlatformIO)
- **Git** (for cloning dependencies)
- **Serial terminal software** (optional):
  - CoolTerm (recommended)
  - Arduino Serial Monitor
  - PlatformIO Serial Monitor
  - screen/minicom (Linux/macOS)

### Development Tools (Optional)

- **Visual Studio Code** with PlatformIO extension
- **Teensy Loader Application** (for manual flashing)

## Installation

### 1. Install PlatformIO

#### Option A: PlatformIO IDE (Recommended)

1. **Install Visual Studio Code** from [code.visualstudio.com](https://code.visualstudio.com/)

2. **Install PlatformIO IDE extension**:
   - Open VS Code
   - Go to Extensions (Ctrl+Shift+X / Cmd+Shift+X)
   - Search for "PlatformIO IDE"
   - Click Install

#### Option B: PlatformIO Core (Command Line)

```bash
# macOS/Linux
python3 -c "$(curl -fsSL https://raw.githubusercontent.com/platformio/platformio/master/scripts/get-platformio.py)"

# Or using pip
pip install -U platformio
```

### 2. Clone or Navigate to Project

```bash
cd /path/to/6502/Firmware/DB\ Emulator
```

### 3. Install Dependencies

PlatformIO will automatically install the required libraries on first build:

- **[QNEthernet](https://github.com/ssilverman/QNEthernet)** (v0.27.0+): Ethernet library for Teensy 4.1
- **[ArduinoJson](https://github.com/bblanchon/ArduinoJson)** (v7.0.4+): JSON parsing and generation
- **[AsyncWebServer_Teensy41](https://github.com/khoih-prog/AsyncWebServer_Teensy41)** (v1.7.0+): Asynchronous web server

Additional dependencies included in the project:
- **[vrEmu6502](https://github.com/visrealm/vrEmu6502)**: 6502 CPU emulator core (included in `lib/6502/vrEmu6502/`)
- **TimeLib**: Real-time clock support
- **Bounce2**: Button debouncing library
- **SD**: SD card file system
- **EEPROM**: Non-volatile storage
- **USBHost_t36**: USB host support for Teensy

## Configuration

### Select Your Development Board

Edit `platformio.ini` or use the PlatformIO environment selector to choose your board configuration:

- **devboard_0**: Original development board
- **devboard_1**: Latest revision with improved layout and additional features (recommended)

### Build Flags

You can enable/disable features by uncommenting build flags in `platformio.ini`:

```ini
build_flags = 
    -D DEVBOARD_1           ; Board version
    -D USB_DUAL_SERIAL      ; Enable dual serial ports
    ; -D HW_SERIAL          ; Enable hardware serial writes to serial header TX pin (Dev Output Board)
    ; -D MOUSE_DEBUG        ; Enable mouse debugging output
    ; -D JOYSTICK_DEBUG     ; Enable joystick debugging output
    ; -D KEYBOARD_DEBUG     ; Enable keyboard debugging output
    -D MEM_EXTMEM           ; Use external PSRAM
```

### SD Card Setup (Optional)

1. **Format SD card** as FAT32
2. **Create directories** on the SD card:
   ```
   /ROMs/       - BIOS and operating system ROMs
   /Carts/      - Cartridge images
   /Programs/   - User programs
   /Snapshots/  - Memory snapshots
   /WWW/        - Embedded web application (See README in /html folder)
   ```
3. **Place ROM or PRG files** (.bin or .prg format) in appropriate directories

**Auto-boot Configuration**:
- Place `BIOS.bin` in the `ROMs` directory for automatic loading

## Building and Uploading

### Using PlatformIO IDE (VS Code)

1. **Open the project** in VS Code (File → Open Folder)

2. **Select your environment**:
   - Click the environment selector in the status bar
   - Choose `devboard_0`, or `devboard_1`

3. **Build the project**:
   - Click the ✓ (Build) button in the status bar
   - Or: Terminal → Run Build Task
   - Or: Press `Ctrl+Alt+B` / `Cmd+Alt+B`

4. **Upload to Teensy**:
   - Connect Teensy 4.1 via USB
   - Click the → (Upload) button in the status bar
   - Or: Use the upload task from the command palette
   - The Teensy will automatically enter bootloader mode

### Using PlatformIO Core (Command Line)

```bash
# Build for DevBoard 1
platformio run -e devboard_1

# Upload to Teensy
platformio run -e devboard_1 --target upload

# Build and upload
platformio run -e devboard_1 -t upload

# Open serial monitor
platformio device monitor -b 115200

# Build, upload, and monitor
platformio run -e devboard_1 -t upload && platformio device monitor -b 115200
```

### Manual Upload with Teensy Loader

1. Build the firmware using PlatformIO
2. Locate the compiled `.hex` file in `.pio/build/devboard_X/firmware.hex`
3. Open Teensy Loader application
4. Load the `.hex` file
5. Press the button on the Teensy to enter bootloader mode
6. Click "Program" in Teensy Loader

## Usage

### Serial Terminal Control

Connect to the Teensy via serial terminal at **115200 baud**:

```bash
# Using PlatformIO
platformio device monitor -b 115200

# Using screen (macOS/Linux)
screen /dev/ttyACM0 115200

# Using CoolTerm
# Set port to Teensy, baud rate to 115200
```
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

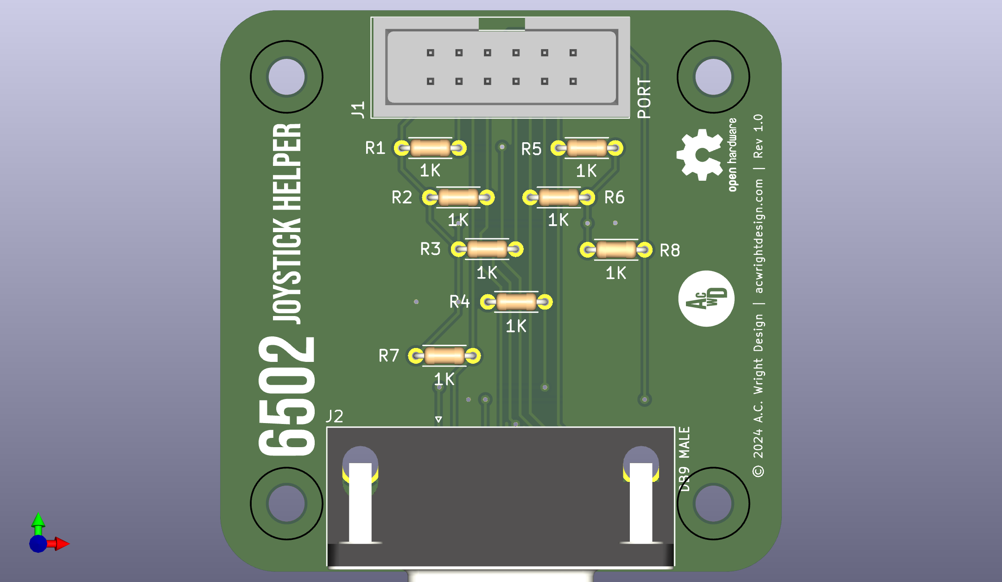
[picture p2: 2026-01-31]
Assets/PCB Images/Joystick Helper/Rev 1.0/Front.png

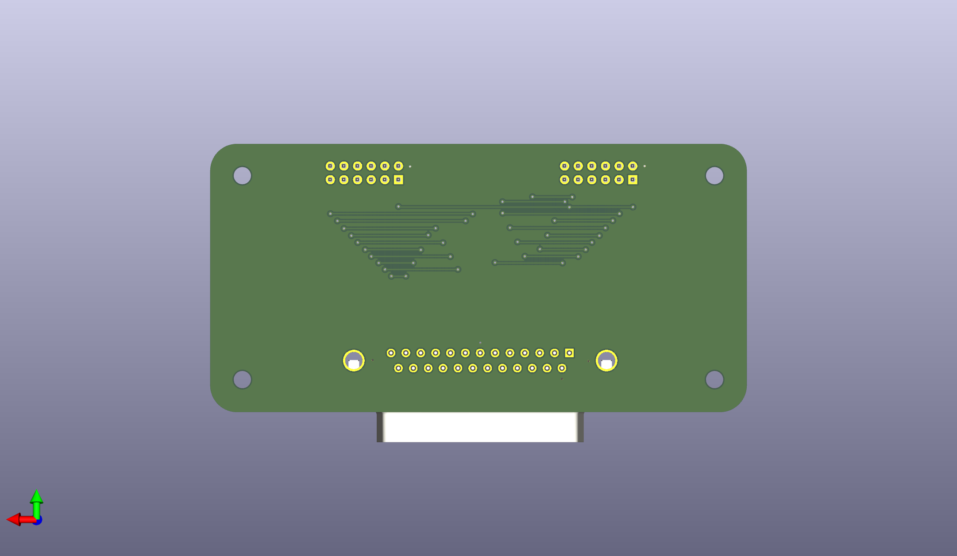
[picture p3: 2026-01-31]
Assets/PCB Images/DB25 Helper/Rev 1.0/Back.png

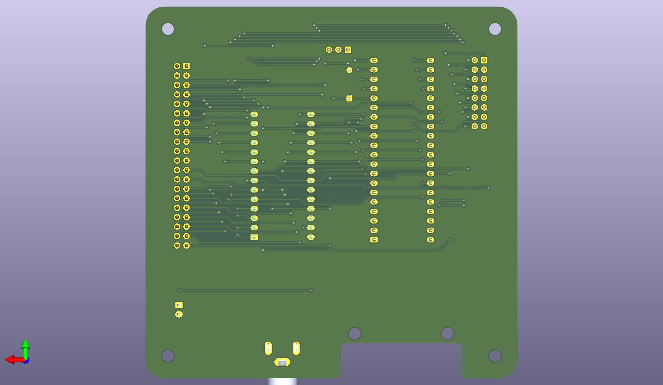
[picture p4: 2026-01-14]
Assets/PCB Images/Output Board/Rev 1.0/Back.png

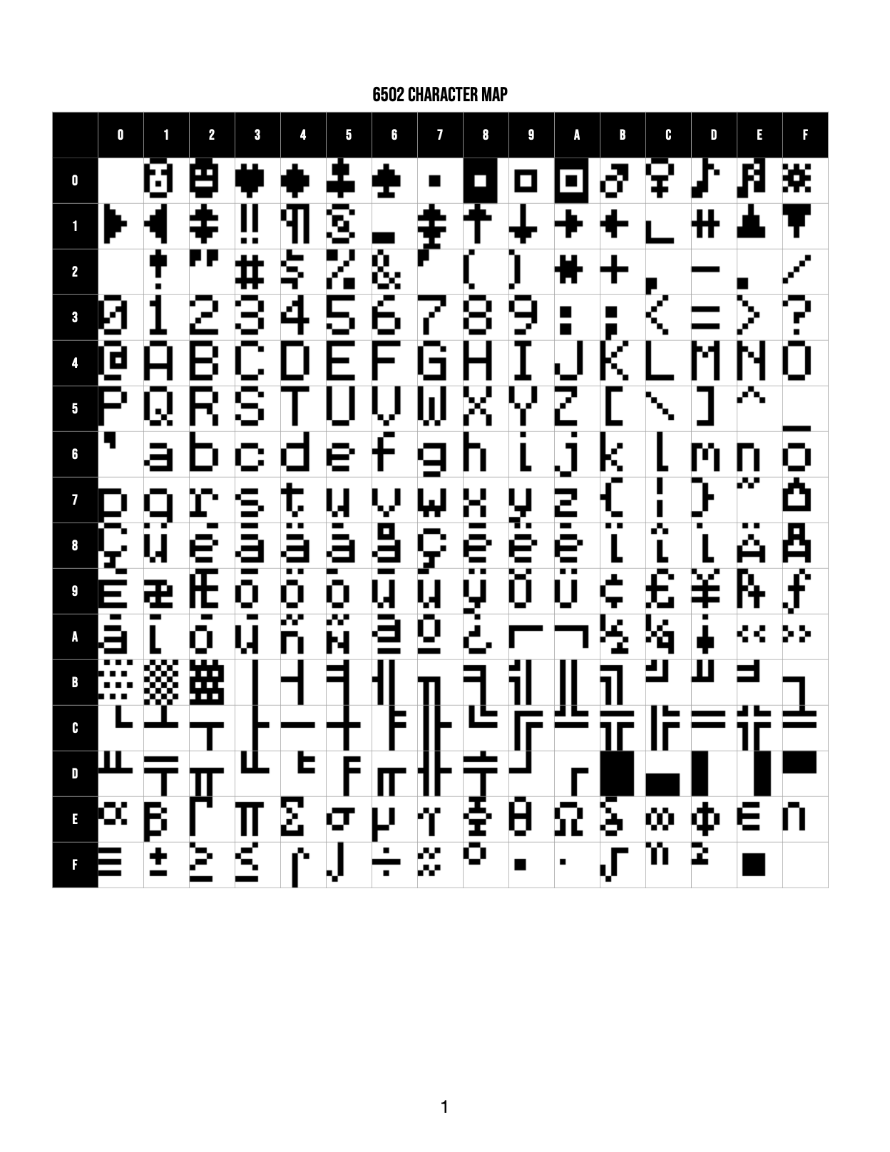
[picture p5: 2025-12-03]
Assets/Documents/Characters/Character Map.png

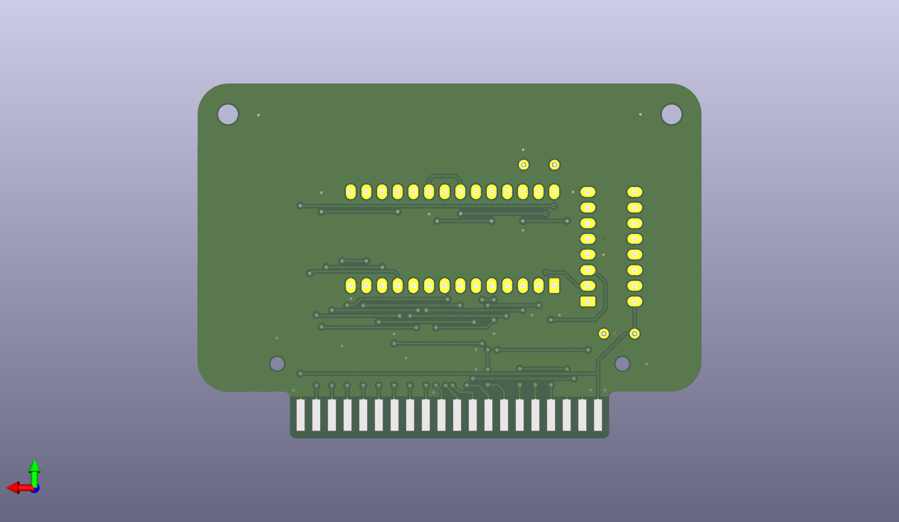
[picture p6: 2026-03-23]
Assets/PCB Images/ROM Cart/Rev 1.0b/Back.png

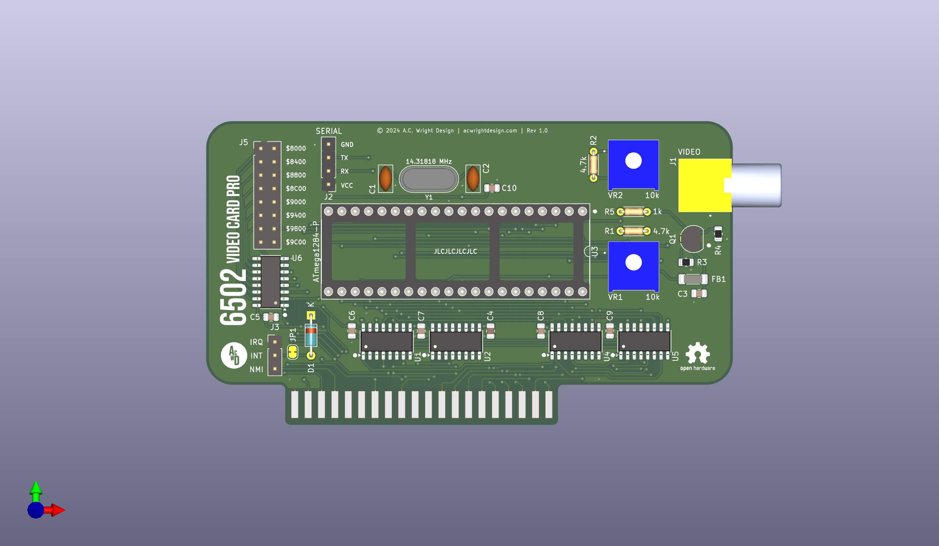
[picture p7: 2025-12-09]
Assets/PCB Images/Video Card Pro/Rev 1.0/Front.png

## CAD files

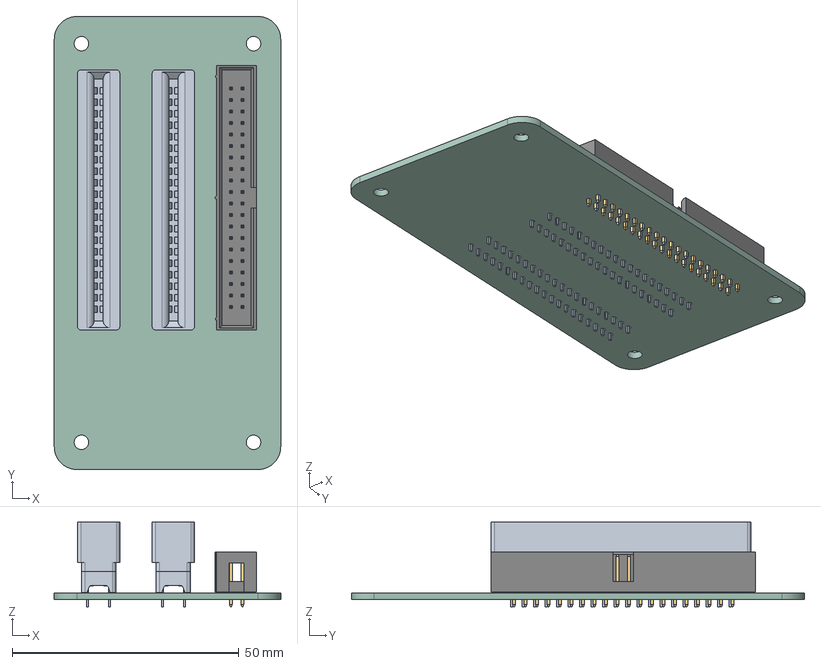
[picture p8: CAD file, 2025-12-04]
Assets/PCB Models/Backplane Helper/Rev 1.0/Backplane Helper.step
50.0 x 100.0 x 18.7 mm
6120xx21621_PIN x 40
Backplane Helper_PCB

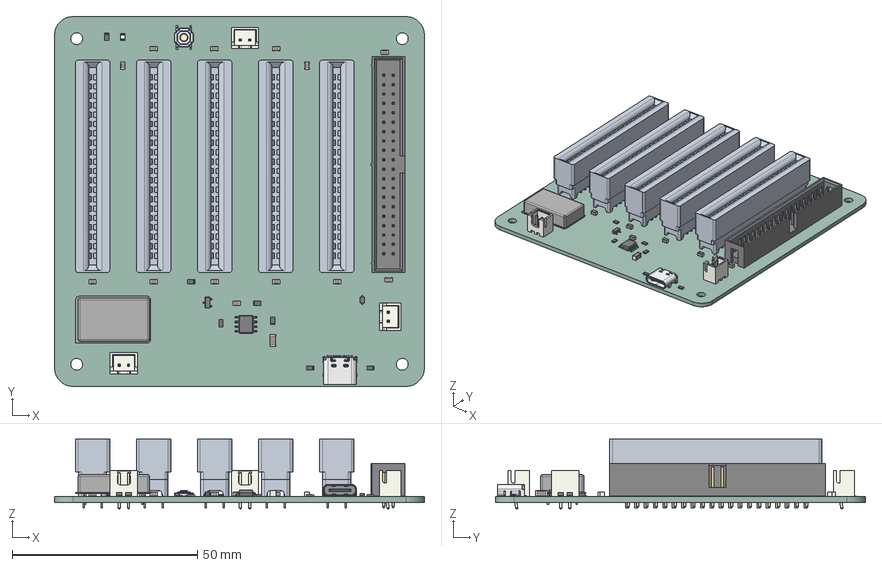
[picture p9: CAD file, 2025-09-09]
Assets/PCB Models/Backplane Pro/Rev 1.0/Backplane Pro.step
100.0 x 100.0 x 18.9 mm
C_0805_2012Metric x 13
LED_0805_2012Metric
ConPins
PcbPins
Mold
Frame
JST_XH_B2B-XH-A_1x02_P2.50mm_Vertical x 3
R_0805_2012Metric x 7
6120xx21621_PIN x 40
D_SOD-323F
C_1206_3216Metric
SOT-23
TS-1187A-B-A-B
SOIC-8_3.9x4.9mm_P1.27mm
Oscillator_DIP-14
Backplane Pro_PCB

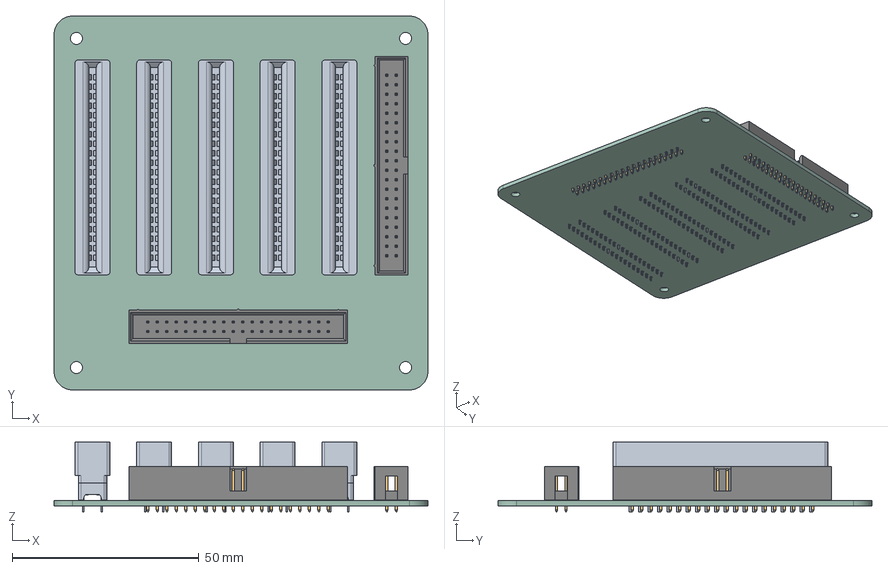
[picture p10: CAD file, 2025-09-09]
Assets/PCB Models/Backplane/Rev 1.0/Backplane.step
100.0 x 100.0 x 18.7 mm
6120xx21621_PIN x 80
Backplane_PCB

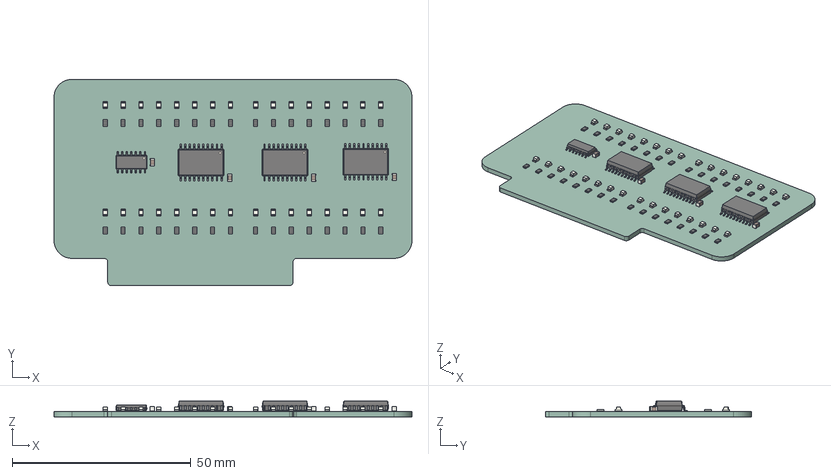
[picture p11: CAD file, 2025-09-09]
Assets/PCB Models/Blinkenlights Card/Rev 1.0/Blinkenlights Card.step
100.0 x 57.6 x 4.34 mm
R_0805_2012Metric x 32
LED_0805_2012Metric x 32
C_0805_2012Metric x 4
SOIC-14_3.9x8.7mm_P1.27mm
SOIC-20W_7.5x12.8mm_P1.27mm x 3
Blinkenlights Card_PCB

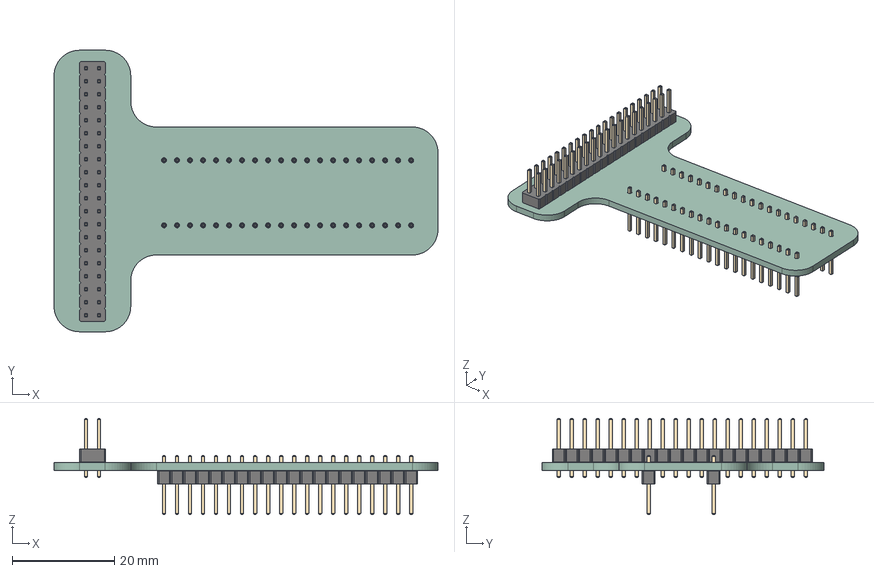
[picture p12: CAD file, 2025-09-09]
Assets/PCB Models/Breadboard Helper/Rev 1.0/Breadboard Helper.step
75.0 x 55.0 x 18.8 mm
PinHeader_2x20_P2.54mm_Vertical
PinHeader_1x20_P2.54mm_Vertical x 2
Breadboard Helper_PCB

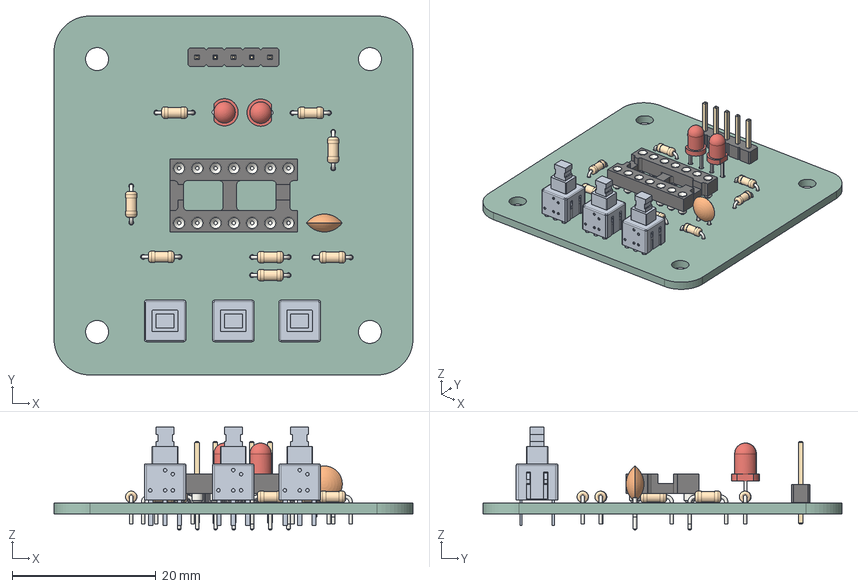
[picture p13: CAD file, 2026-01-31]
Assets/PCB Models/Clock Helper/Rev 1.0/Clock Helper.step
50.0 x 50.0 x 14.3 mm
R_Axial_DIN0204_L3.6mm_D1.6mm_P5.08mm_Horizontal x 8
XKB5858 x 3
LED_D3.0mm x 2
C_Disc_D5.0mm_W2.5mm_P2.50mm
DIP-14_W7.62mm_Socket
PinHeader_1x05_P2.54mm_Vertical
Clock Helper_PCB

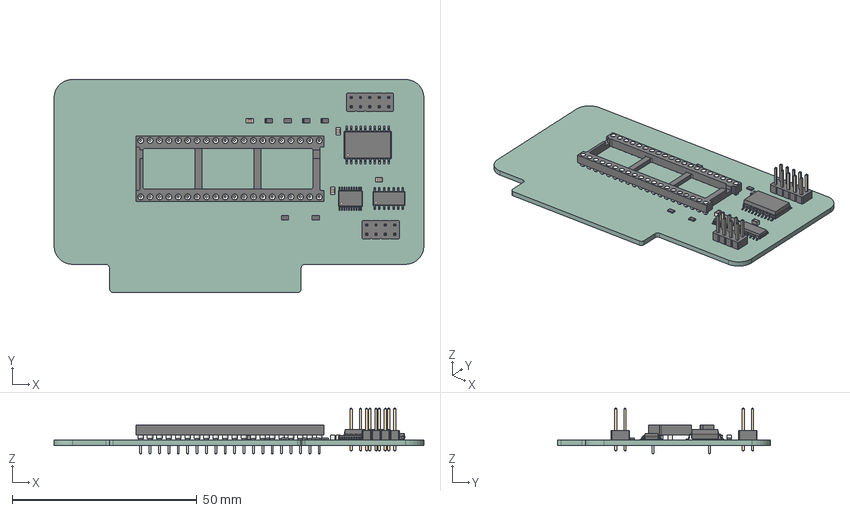
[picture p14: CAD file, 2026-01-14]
Assets/PCB Models/CPU Card Pro/Rev 1.0/CPU Card Pro.step
100.0 x 57.6 x 12.3 mm
R_0805_2012Metric x 6
DIP-40_W15.24mm_Socket
C_0805_2012Metric x 4
SOIC-14_3.9x8.7mm_P1.27mm
PinHeader_2x05_P2.54mm_Vertical
SOIC-20W_7.5x12.8mm_P1.27mm
TSSOP-20_4.4x6.5mm_P0.65mm
PinHeader_2x04_P2.54mm_Vertical
CPU Card Pro_PCB

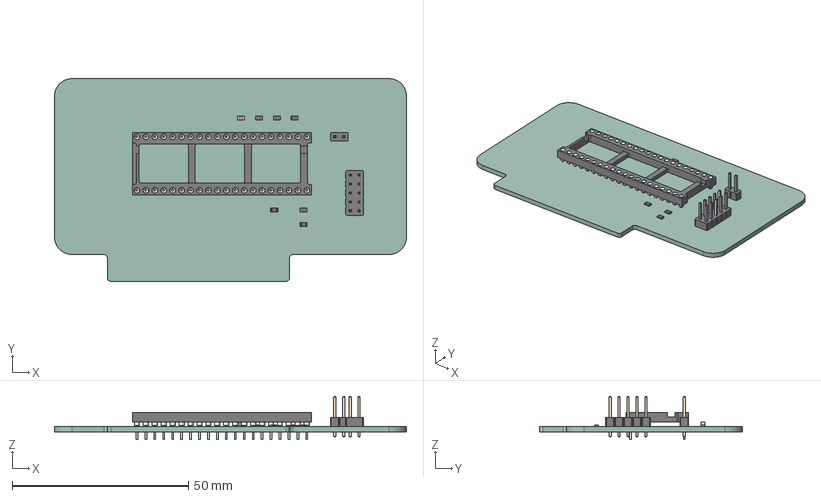
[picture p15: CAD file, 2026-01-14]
Assets/PCB Models/CPU Card/Rev 1.0/CPU Card.step
100.0 x 57.6 x 12.3 mm
R_0805_2012Metric x 6
DIP-40_W15.24mm_Socket
C_0805_2012Metric
PinHeader_1x02_P2.54mm_Vertical
PinHeader_2x05_P2.54mm_Vertical
CPU Card_PCB

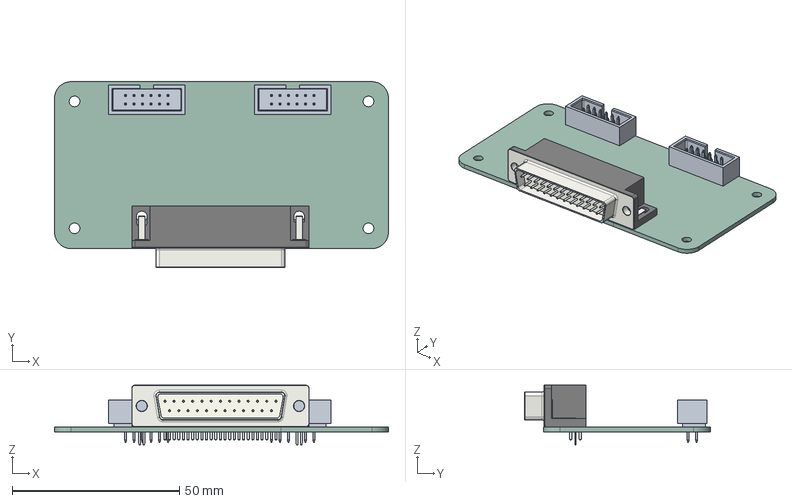
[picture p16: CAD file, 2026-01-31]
Assets/PCB Models/DB25 Helper/Rev 1.0/DB25 Helper.step
100.0 x 55.6 x 17.9 mm
DSUB-25_Pins_Horizontal_P2.77x2.84mm_EdgePinOffset7.70mm_Housed_ MountingHolesOffset9.12mm
DB25 Helper_PCB

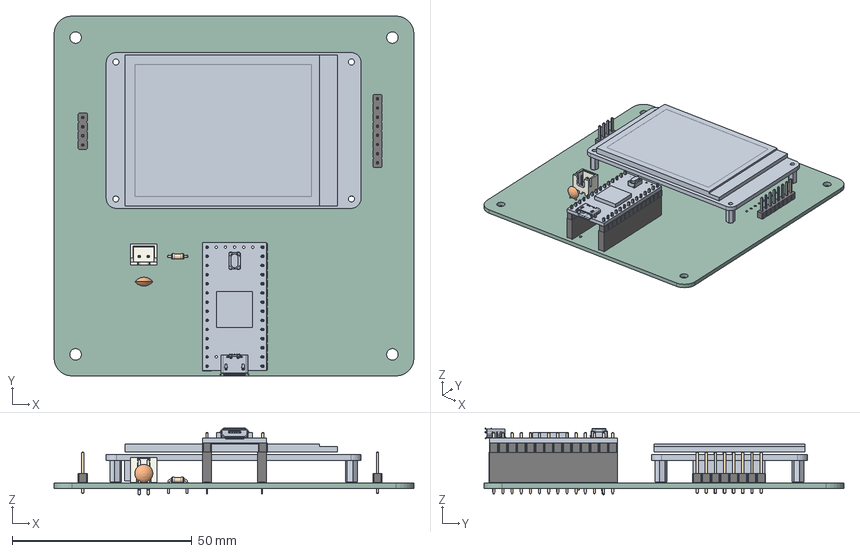
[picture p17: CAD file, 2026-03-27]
Assets/PCB Models/Dev Output Board/Rev 1.0/Dev Output Board.step
100.0 x 100.0 x 18.6 mm
C_Disc_D5.0mm_W2.5mm_P2.50mm
Waveshare 2.4in LCD
R_Axial_DIN0204_L3.6mm_D1.6mm_P5.08mm_Horizontal
PinHeader_1x08_P2.54mm_Vertical
Teensy_4.0_PCB
Micro USB-B Female 5Pin SMD
NXP iMXRT1062
SKRPACE010 v4
PinSocket_1x14_P2.54mm_Vertical x 2
PinHeader_1x14_P2.54mm_Vertical x 2
PinHeader_1x04_P2.54mm_Vertical
JST_XH_B2B-XH-A_1x02_P2.50mm_Vertical
Dev Output Board_PCB

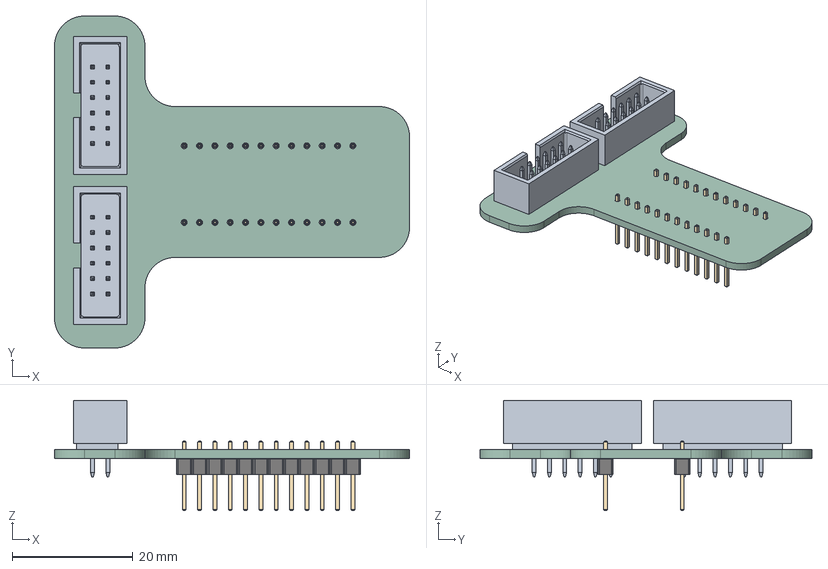
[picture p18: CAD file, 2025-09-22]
Assets/PCB Models/GPIO Breadboard Helper/Rev 1.0/GPIO Breadboard Helper.step
58.8 x 55.0 x 18.3 mm
PinHeader_1x12_P2.54mm_Vertical x 2
GPIO Breadboard Helper_PCB

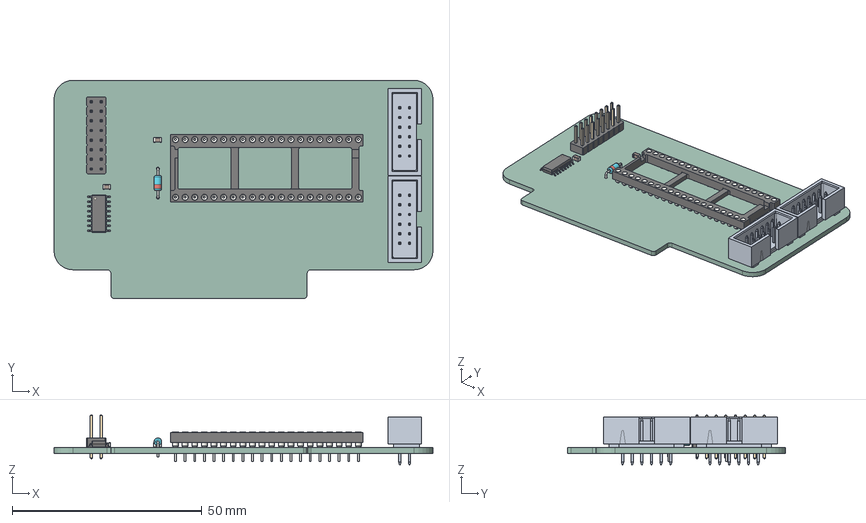
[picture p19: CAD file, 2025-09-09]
Assets/PCB Models/GPIO Card/Rev 1.0/GPIO Card.step
100.0 x 57.6 x 13.2 mm
D_DO-35_SOD27_P7.62mm_Horizontal
SOIC-16_3.9x9.9mm_P1.27mm
DIP-40_W15.24mm_Socket
PinHeader_2x08_P2.54mm_Vertical
C_0805_2012Metric x 2
GPIO Card_PCB

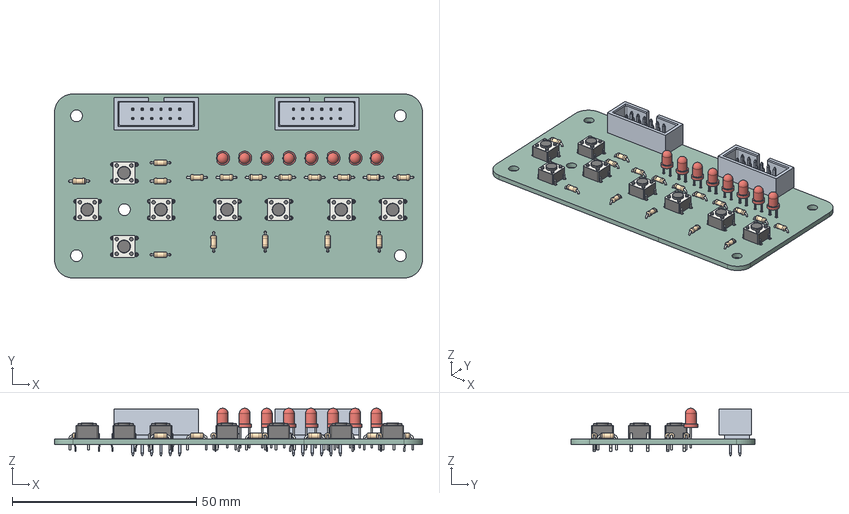
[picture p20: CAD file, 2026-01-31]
Assets/PCB Models/GPIO Helper/Rev 1.0/GPIO Helper.step
100.0 x 50.0 x 12.9 mm
LED_D3.0mm x 8
R_Axial_DIN0204_L3.6mm_D1.6mm_P5.08mm_Horizontal x 16
SW_PUSH_6mm x 8
GPIO Helper_PCB

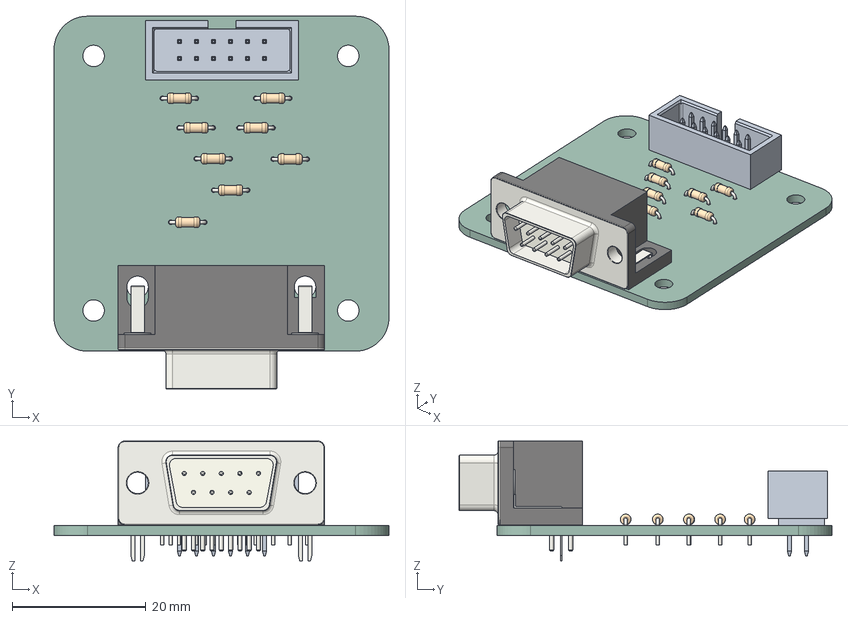
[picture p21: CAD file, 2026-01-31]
Assets/PCB Models/Joystick Helper/Rev 1.0/Joystick Helper.step
50.0 x 55.6 x 17.9 mm
R_Axial_DIN0204_L3.6mm_D1.6mm_P5.08mm_Horizontal x 8
DSUB-9_Pins_Horizontal_P2.77x2.84mm_EdgePinOffset7.70mm_Housed_ MountingHolesOffset9.12mm
Joystick Helper_PCB

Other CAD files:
Assets/PCB Models/Keyboard Encoder Helper/Rev 1.0/Keyboard Encoder Helper.step
Assets/PCB Models/Keyboard Helper/Rev 1.0/Keyboard Helper.step
Assets/PCB Models/Keypad Helper/Rev 1.0/Keypad Helper.step
Assets/PCB Models/Keypad LCD Helper/Rev 1.0/Keypad LCD Helper.step
Assets/PCB Models/Keyboard Helper/Rev 1.0/Keypad Helper.step
Assets/PCB Models/LCD Card/Rev 1.0/LCD Card.step
Assets/PCB Models/Mega Helper/Rev 1.0/Mega Helper.step
Assets/PCB Models/Memory Card/Rev 1.0/Memory Card.step
Assets/PCB Models/Output Board/Rev 1.0/Output Board.step
Assets/PCB Models/PS2 Helper/Rev 1.0/PS2 Helper.step
Assets/PCB Models/RAM Card/Rev 1.0/RAM Card.step
Assets/PCB Models/ROM Cart/Rev 0.0/ROM Cart.step
Assets/PCB Models/ROM Cart/Rev 1.0a/ROM Cart.step
Assets/PCB Models/ROM Cart/Rev 1.0b/ROM Cart.step
Assets/PCB Models/RTC Card/Rev 1.0/RTC Card.step
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

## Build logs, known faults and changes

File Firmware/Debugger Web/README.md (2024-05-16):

# Debugger Web

Embedded web application for 6502 Debugger supporting 6502 Dev Board and Retroshield

## Project Setup

```sh
npm install
```

### Compile and Hot-Reload for Development

```sh
npm run dev
```

### Type-Check, Compile and Minify for Production

```sh
npm run build
```

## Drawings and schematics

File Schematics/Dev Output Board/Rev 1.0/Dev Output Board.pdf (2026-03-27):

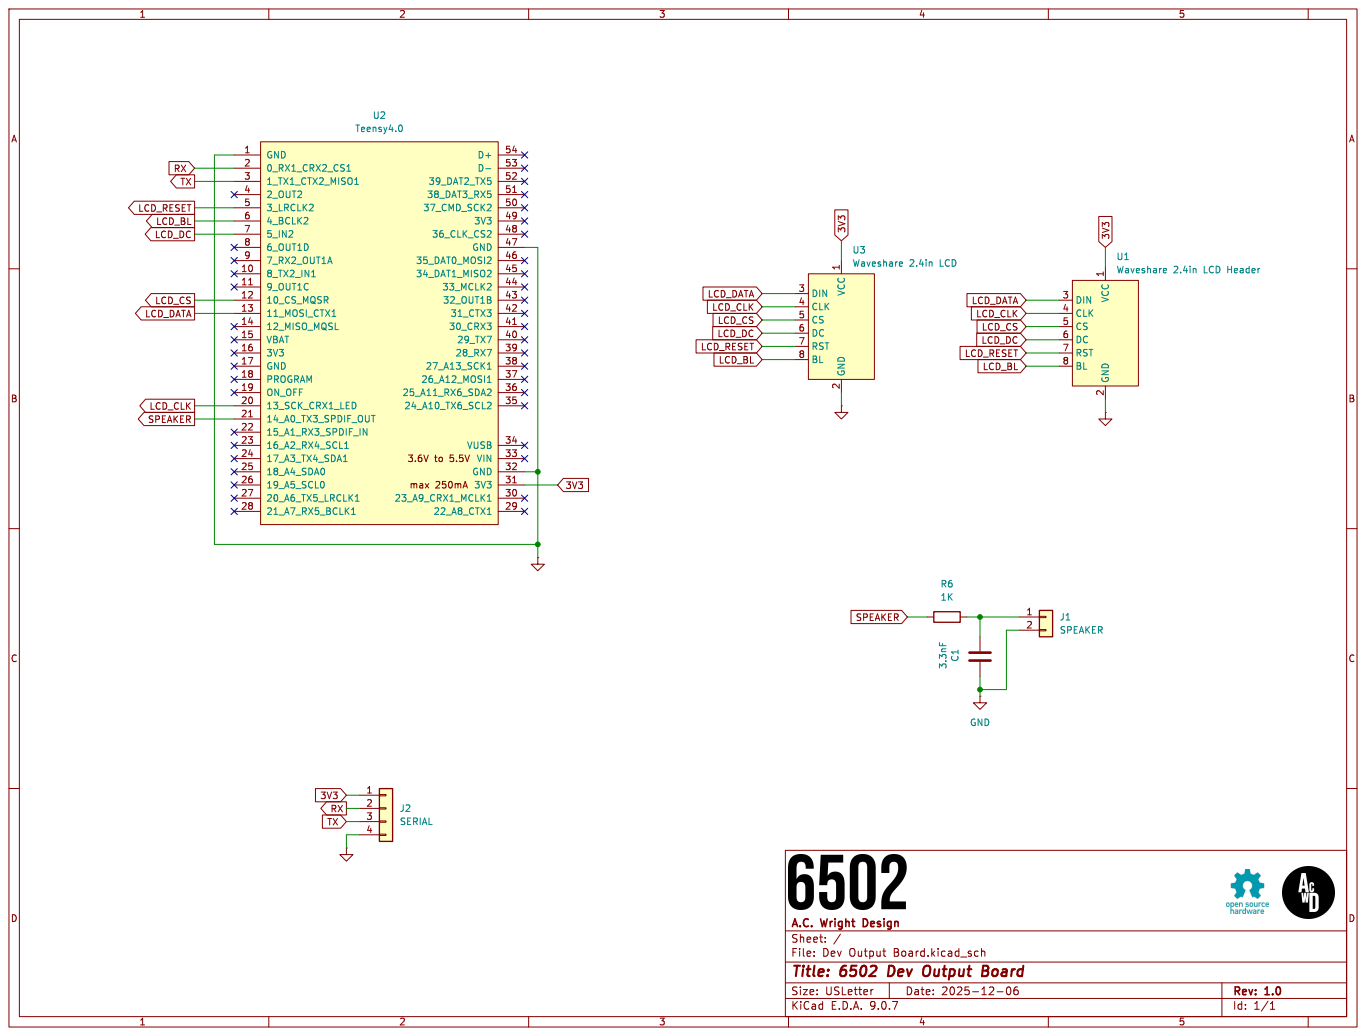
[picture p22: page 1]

2 U1 Waveshare 2.4in LCD Header RX

Id: 1/1 Title: 6502 Dev Output Board

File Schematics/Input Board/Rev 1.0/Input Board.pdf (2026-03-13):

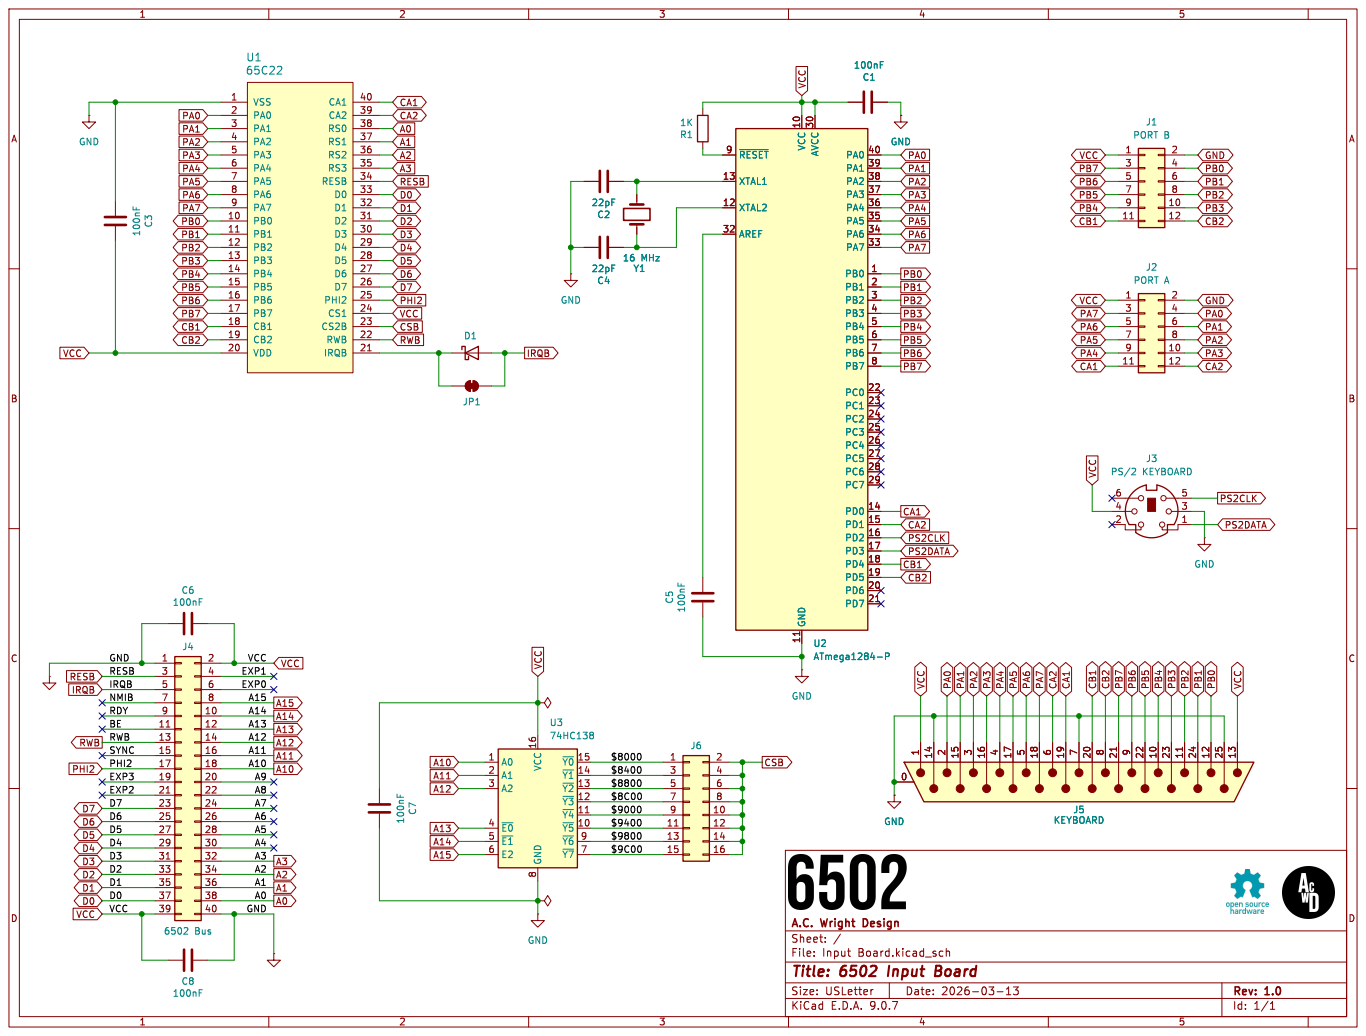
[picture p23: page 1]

Id: 1/1 Title: 6502 Input Board

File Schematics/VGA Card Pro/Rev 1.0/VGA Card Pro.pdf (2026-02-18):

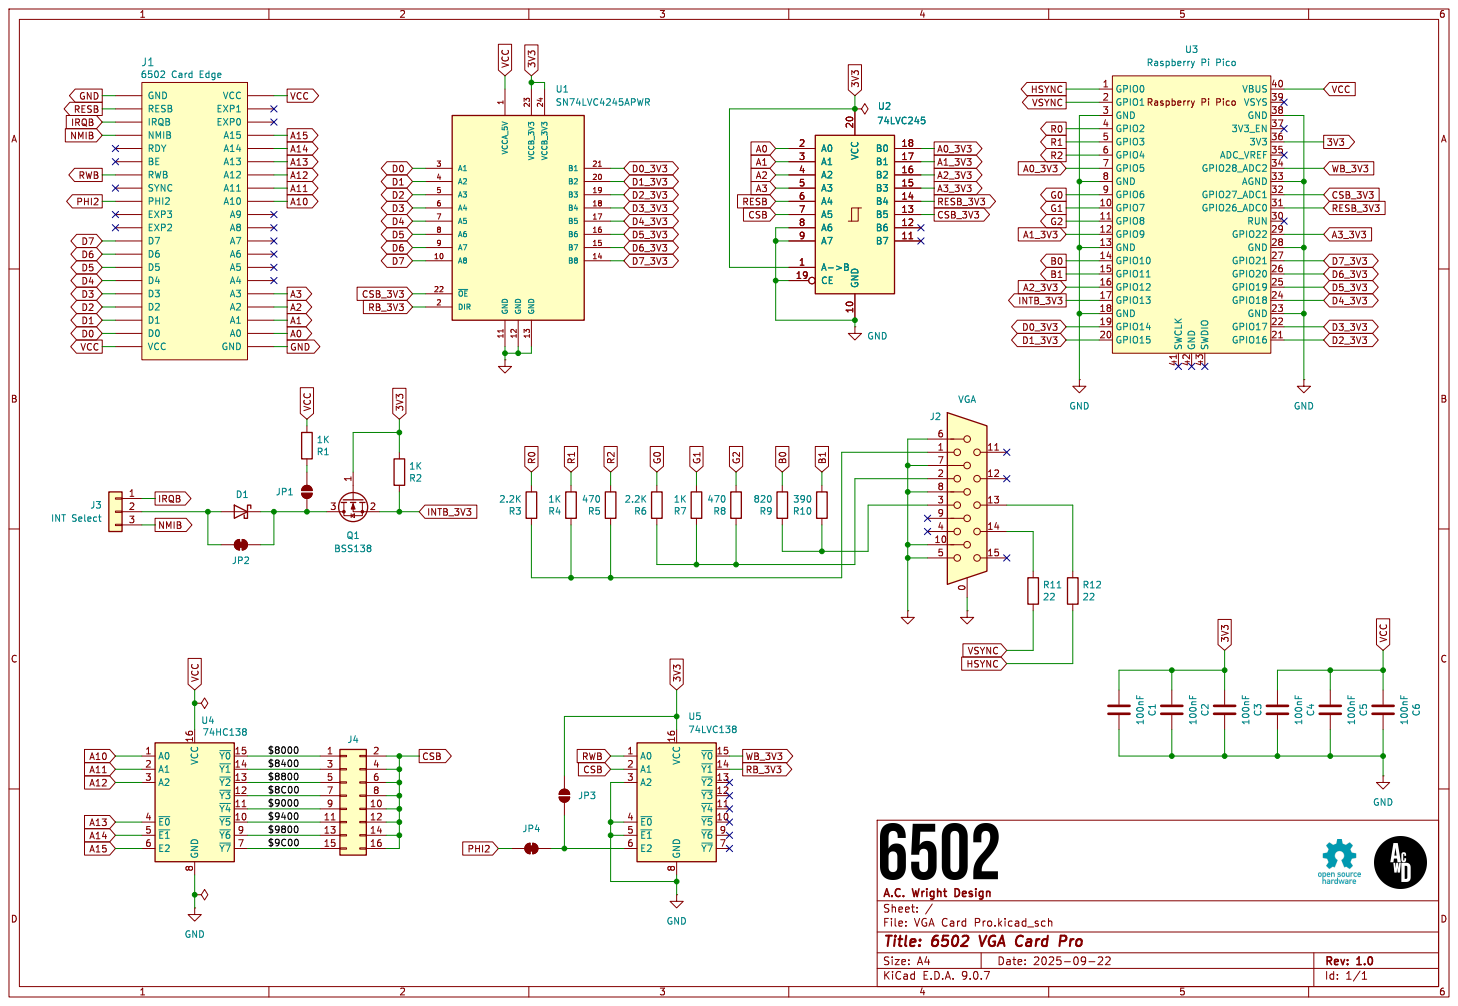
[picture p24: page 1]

1 GND 11 GND 12 VCCB_3V3 23 GND 13 VCCB_3V3 24 B1 21 B2 20 B3 19 B4 18 B5 17 B6 16 B7 15 B8 14 U1SN74LVC4245APWR GND
RESB
IRQB NMIB RDY

Id: 1/1 Title: 6502 VGA Card Pro

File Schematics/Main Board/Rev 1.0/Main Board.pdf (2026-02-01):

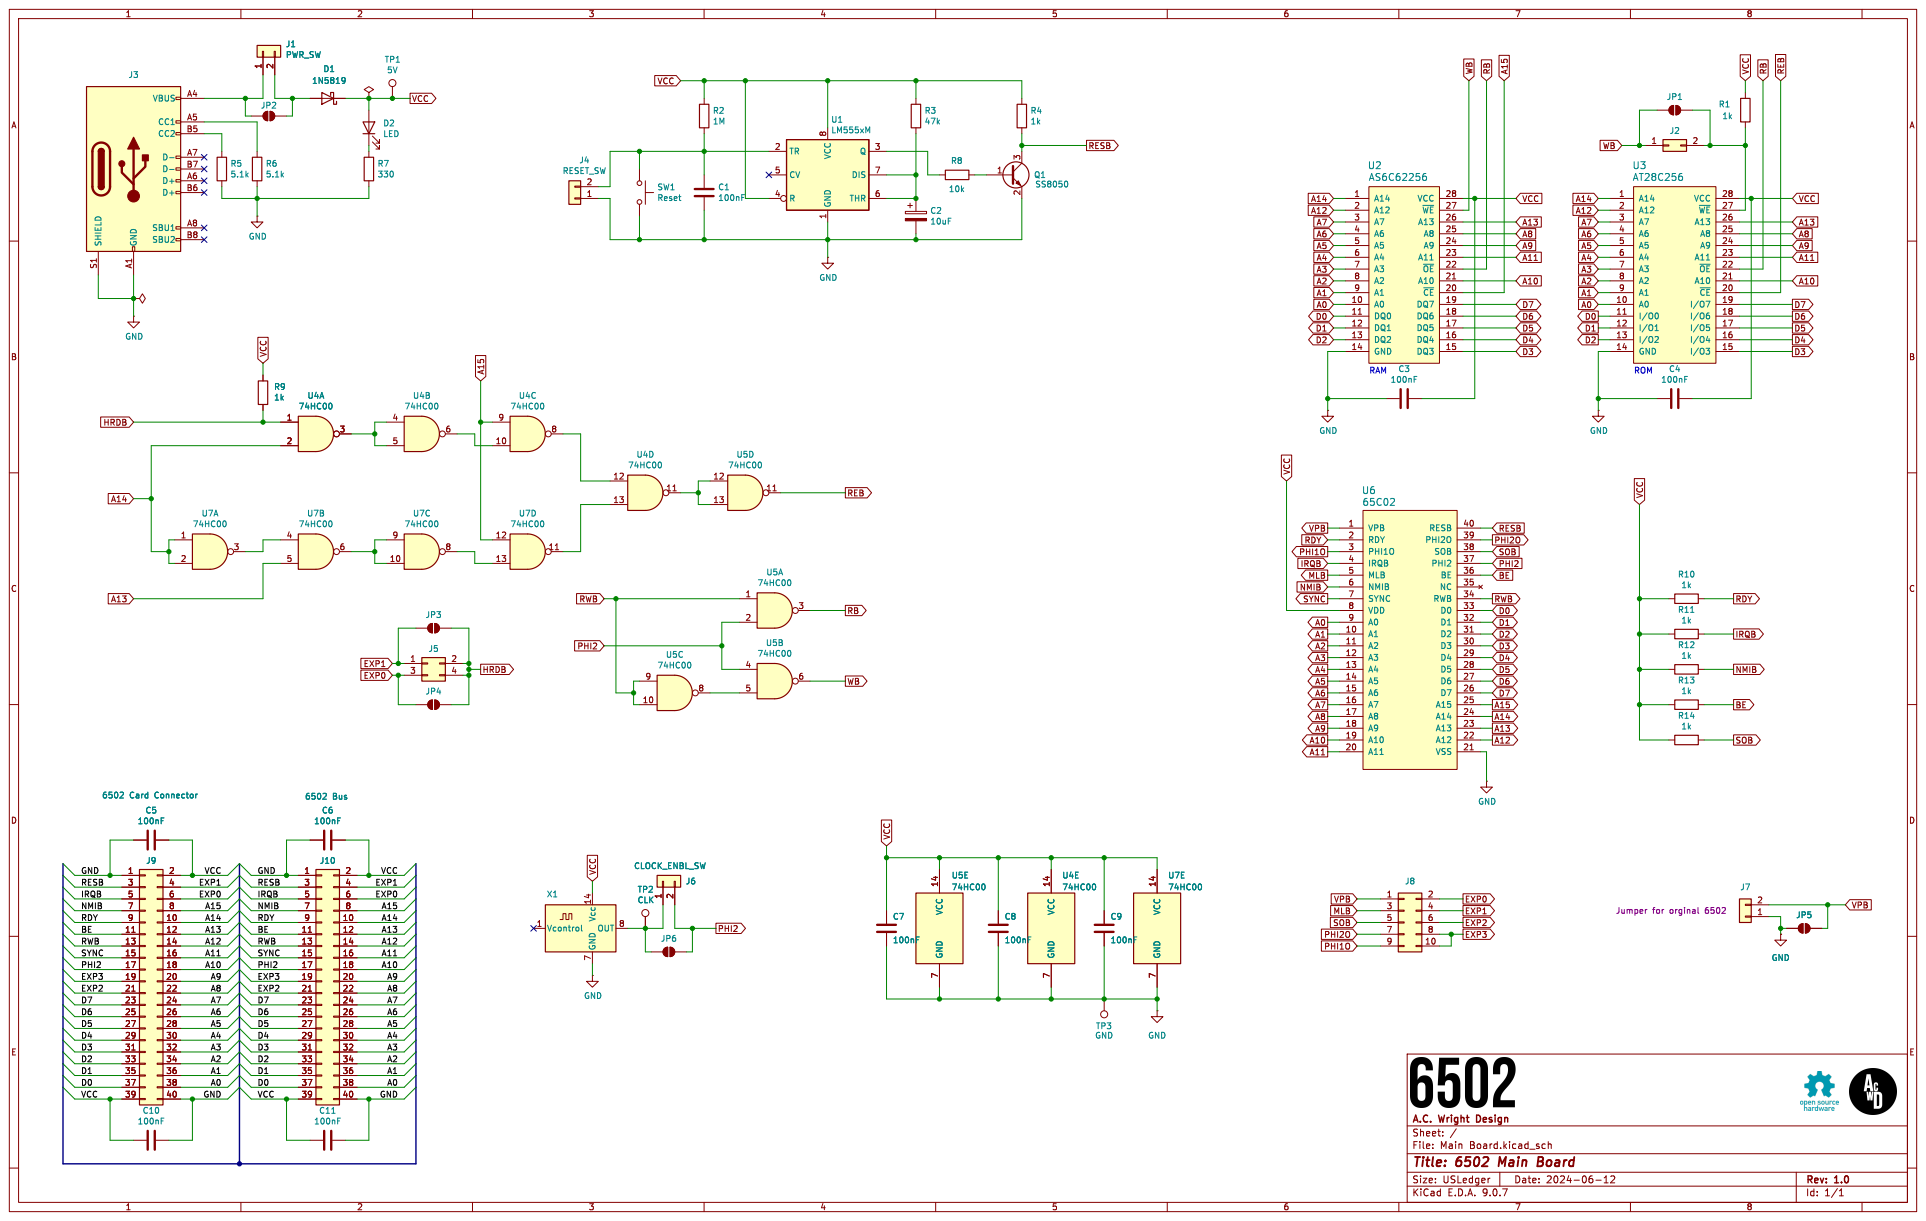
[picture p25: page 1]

Id: 1/1 Title: 6502 Main Board

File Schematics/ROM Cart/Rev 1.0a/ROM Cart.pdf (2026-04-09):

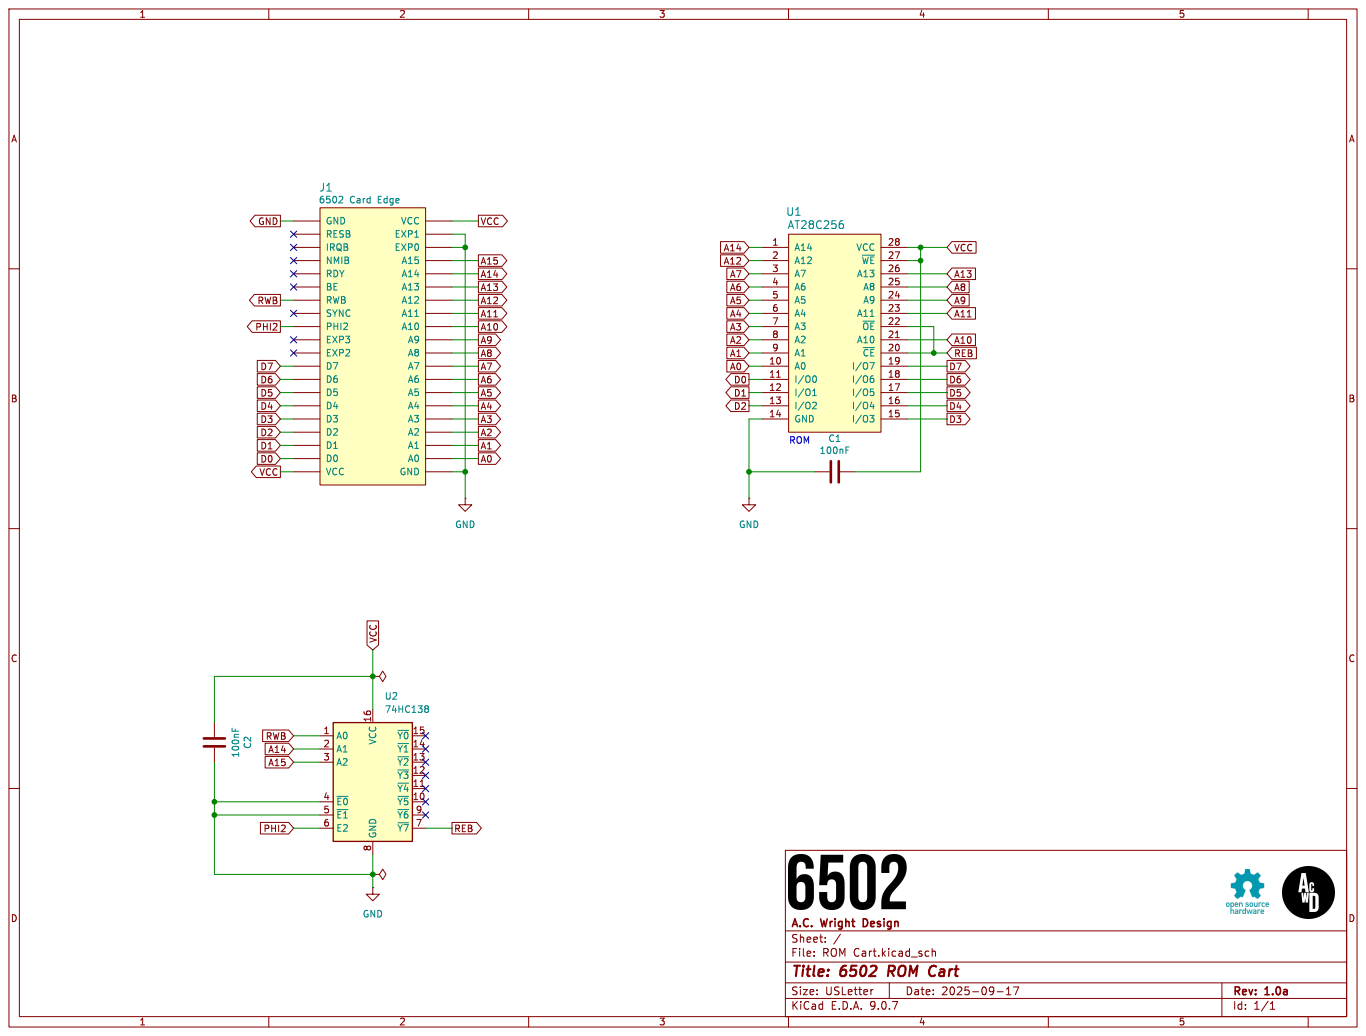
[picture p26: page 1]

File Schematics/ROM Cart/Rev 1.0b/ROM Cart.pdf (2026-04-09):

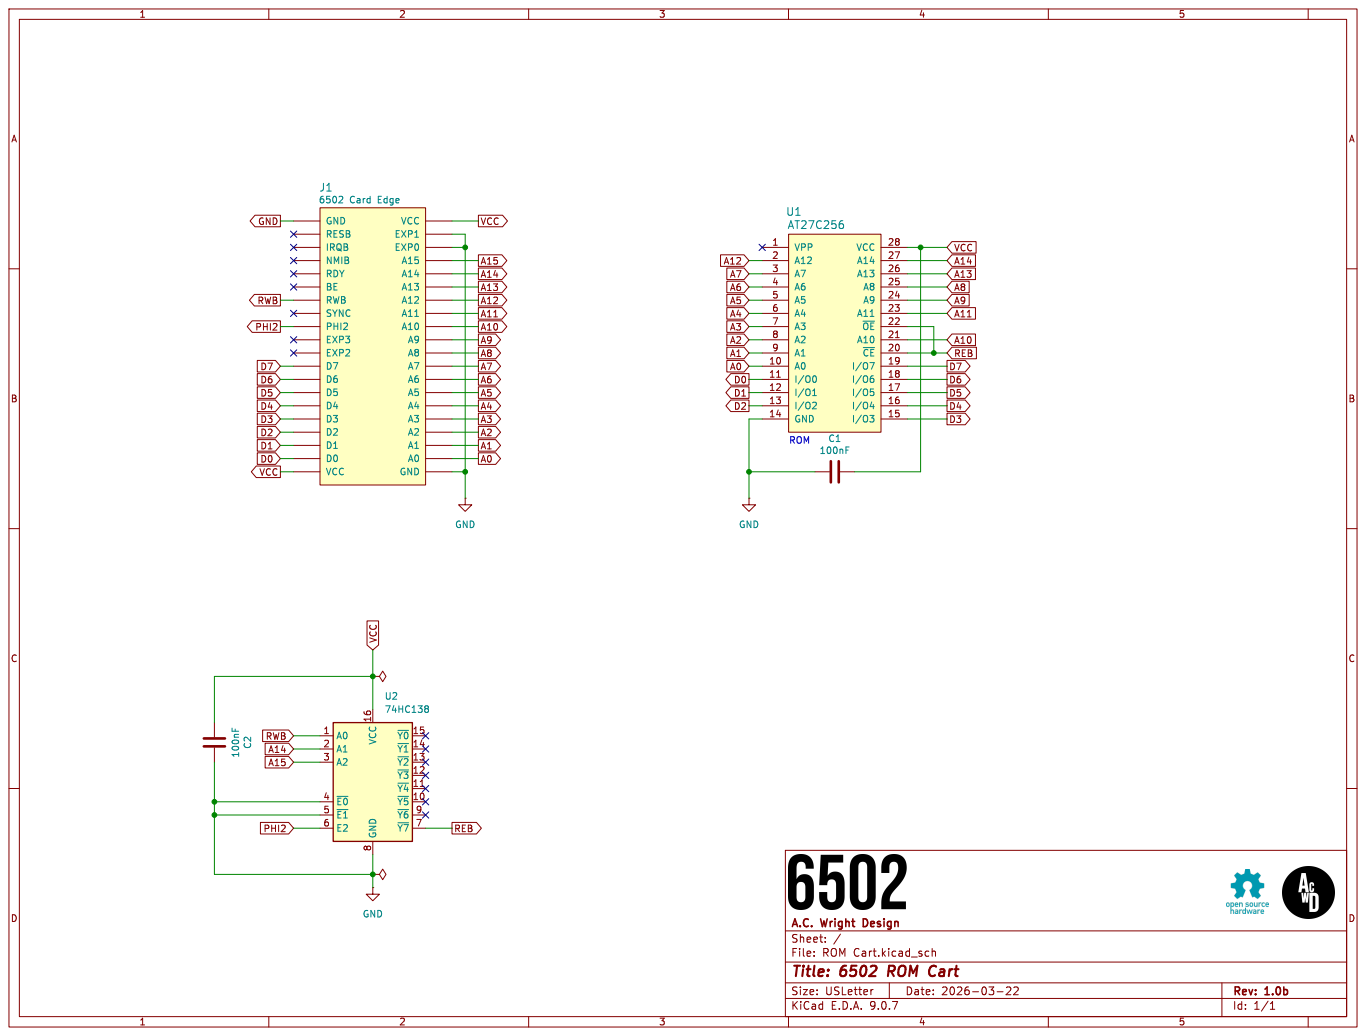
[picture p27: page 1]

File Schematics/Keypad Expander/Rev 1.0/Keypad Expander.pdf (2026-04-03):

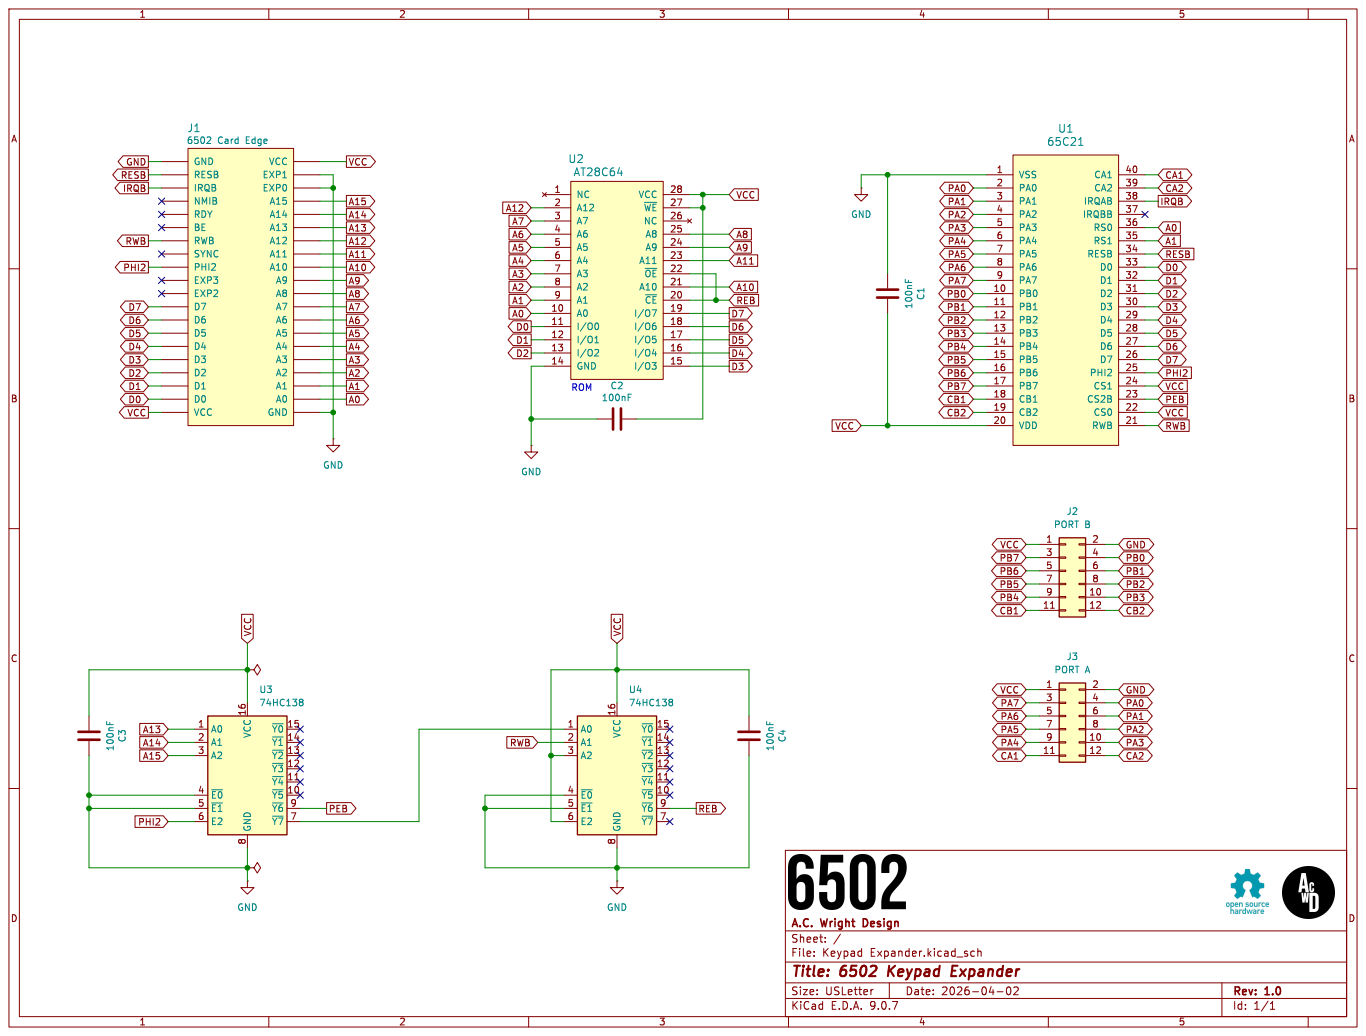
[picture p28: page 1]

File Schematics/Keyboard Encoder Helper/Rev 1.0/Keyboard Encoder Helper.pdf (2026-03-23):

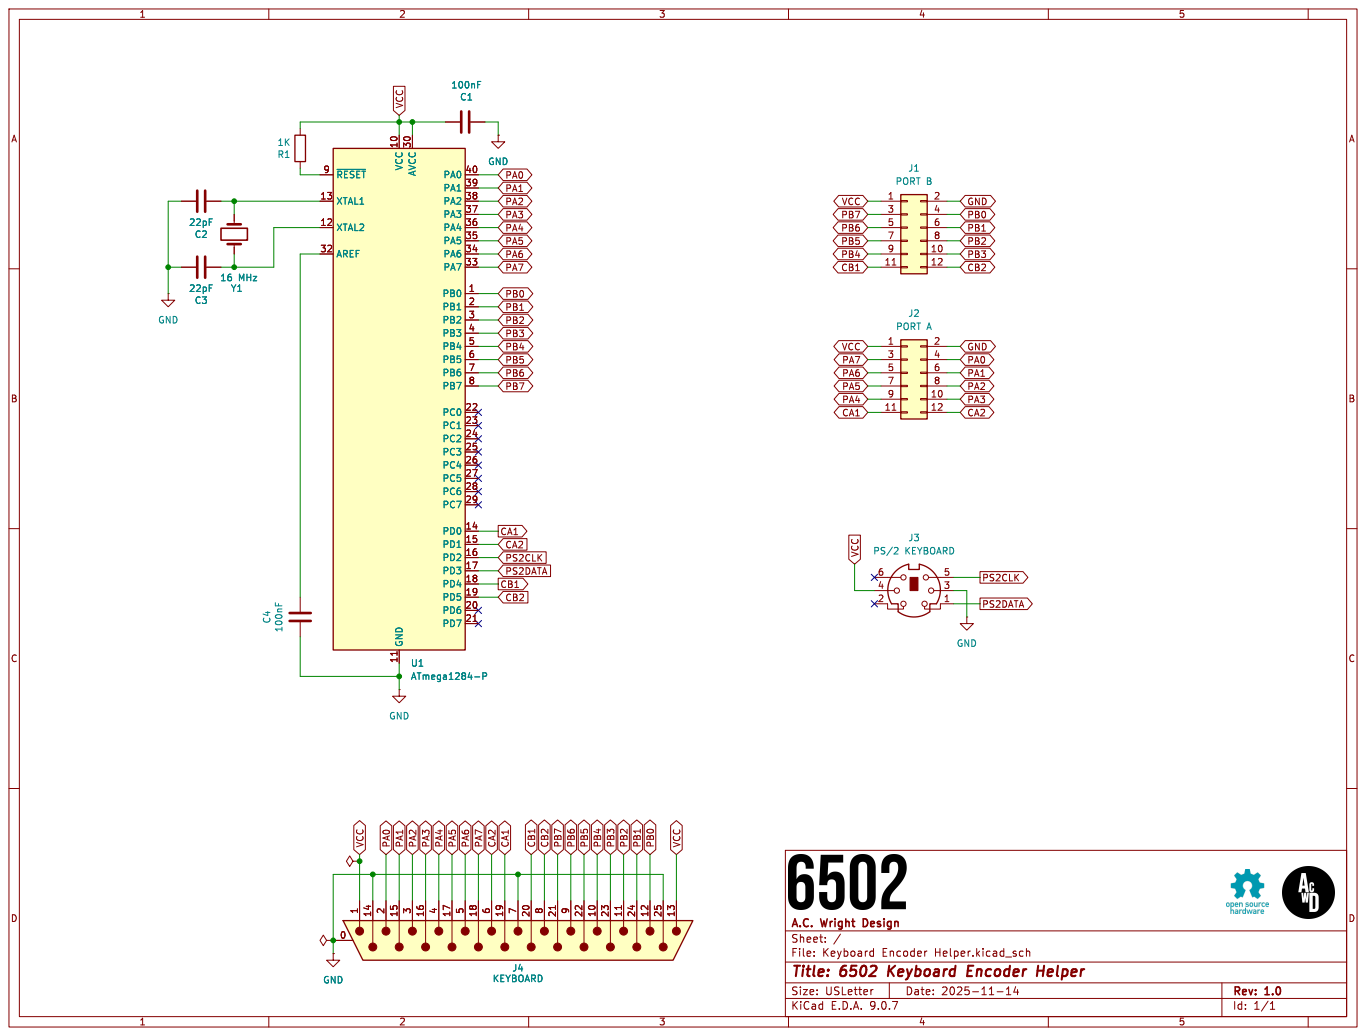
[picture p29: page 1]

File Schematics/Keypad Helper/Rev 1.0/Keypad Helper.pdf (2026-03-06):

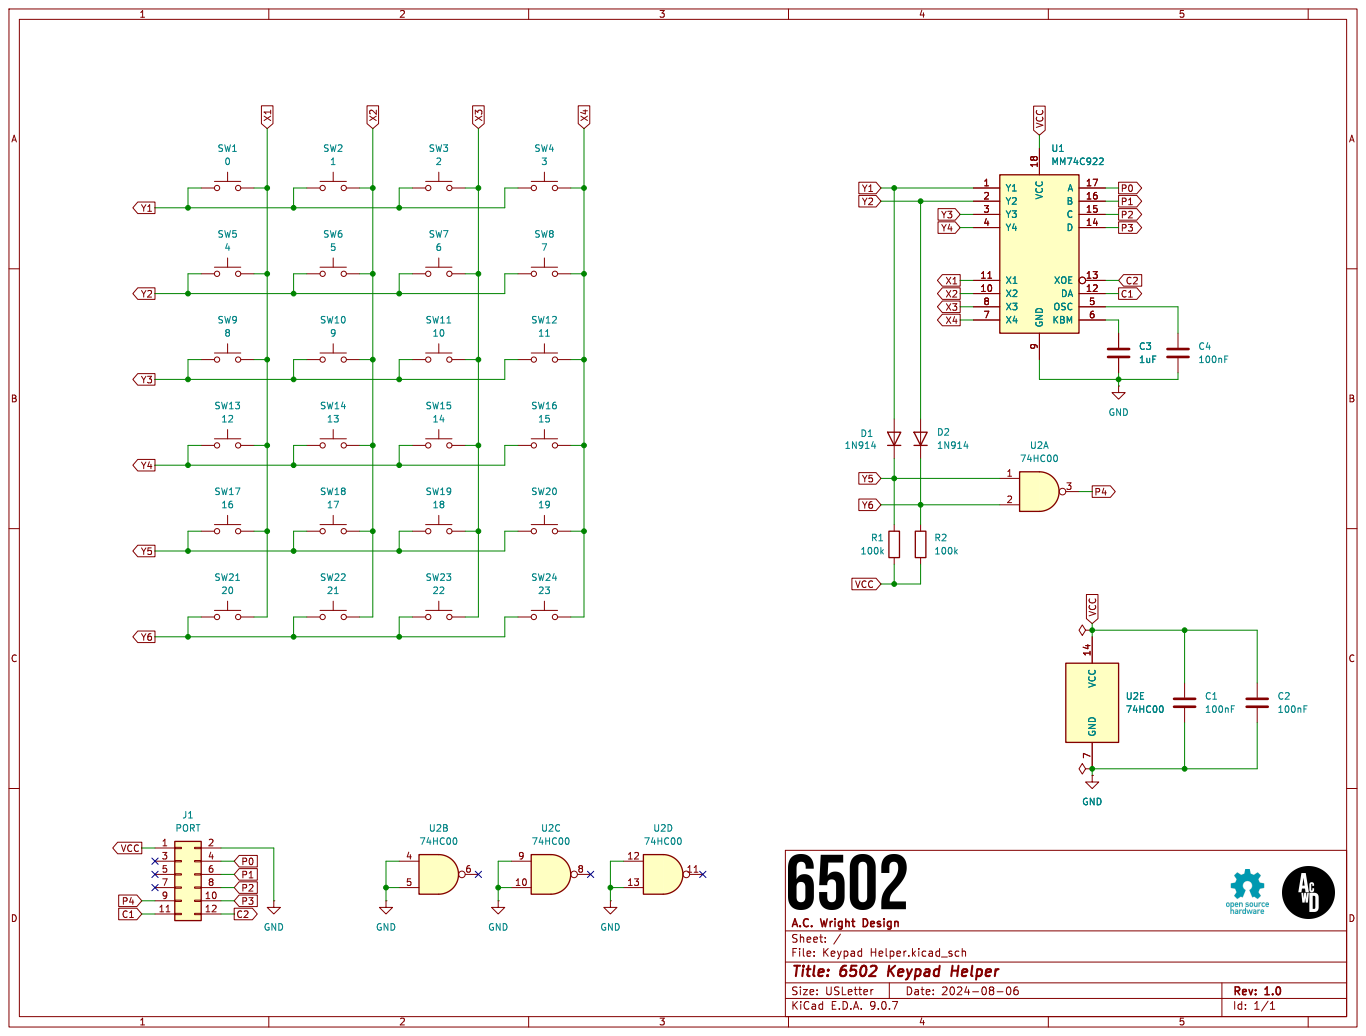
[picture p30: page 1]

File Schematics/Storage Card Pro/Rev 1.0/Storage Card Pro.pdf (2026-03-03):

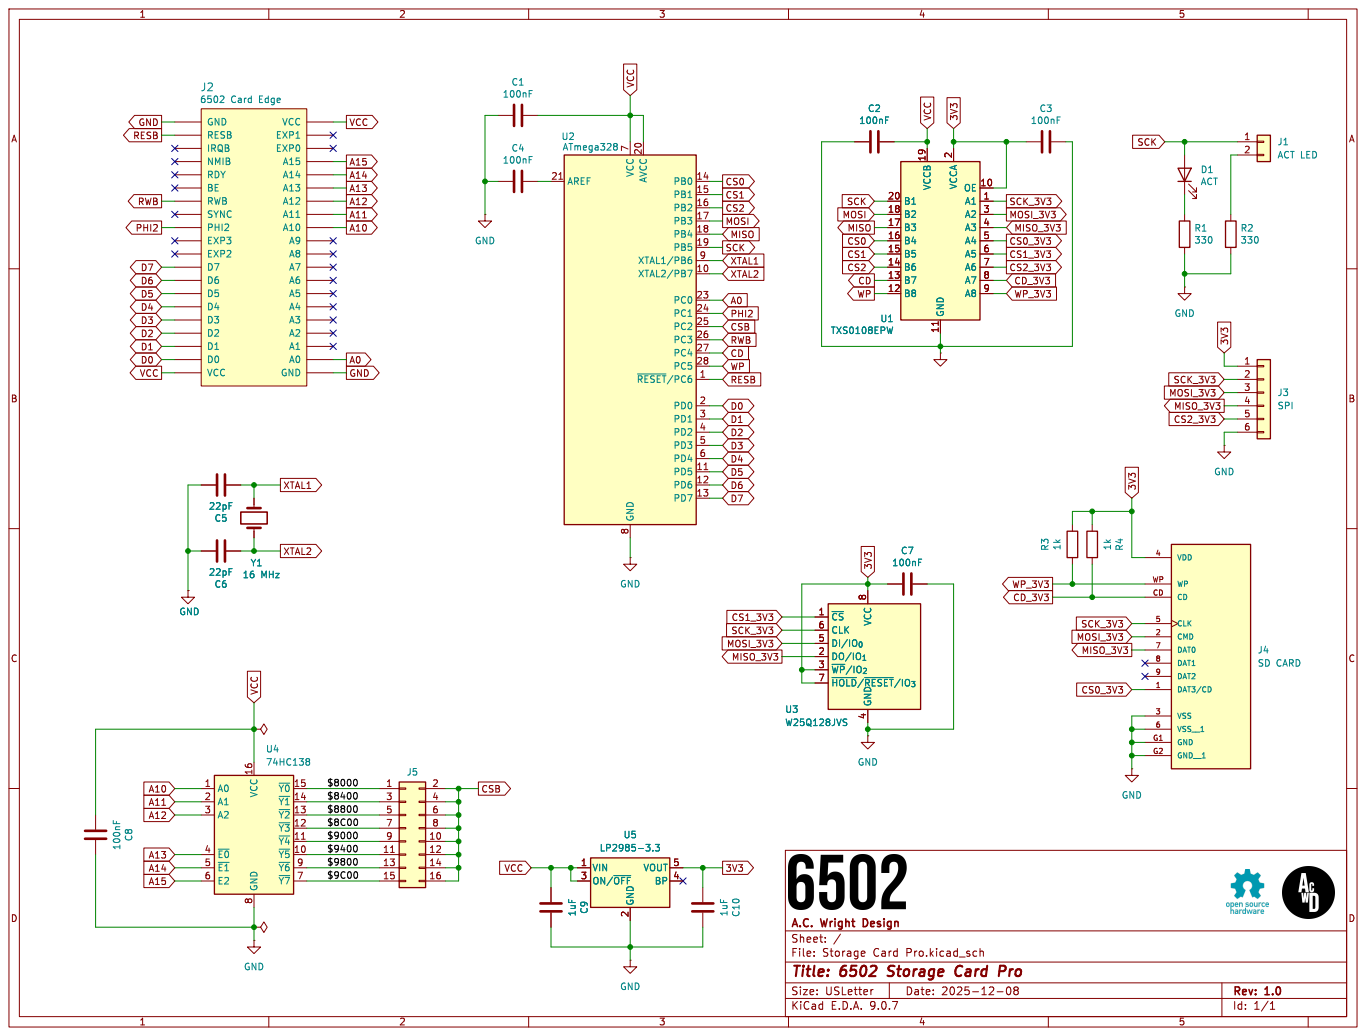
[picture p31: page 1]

Id: 1/1 Title: 6502 Storage Card Pro

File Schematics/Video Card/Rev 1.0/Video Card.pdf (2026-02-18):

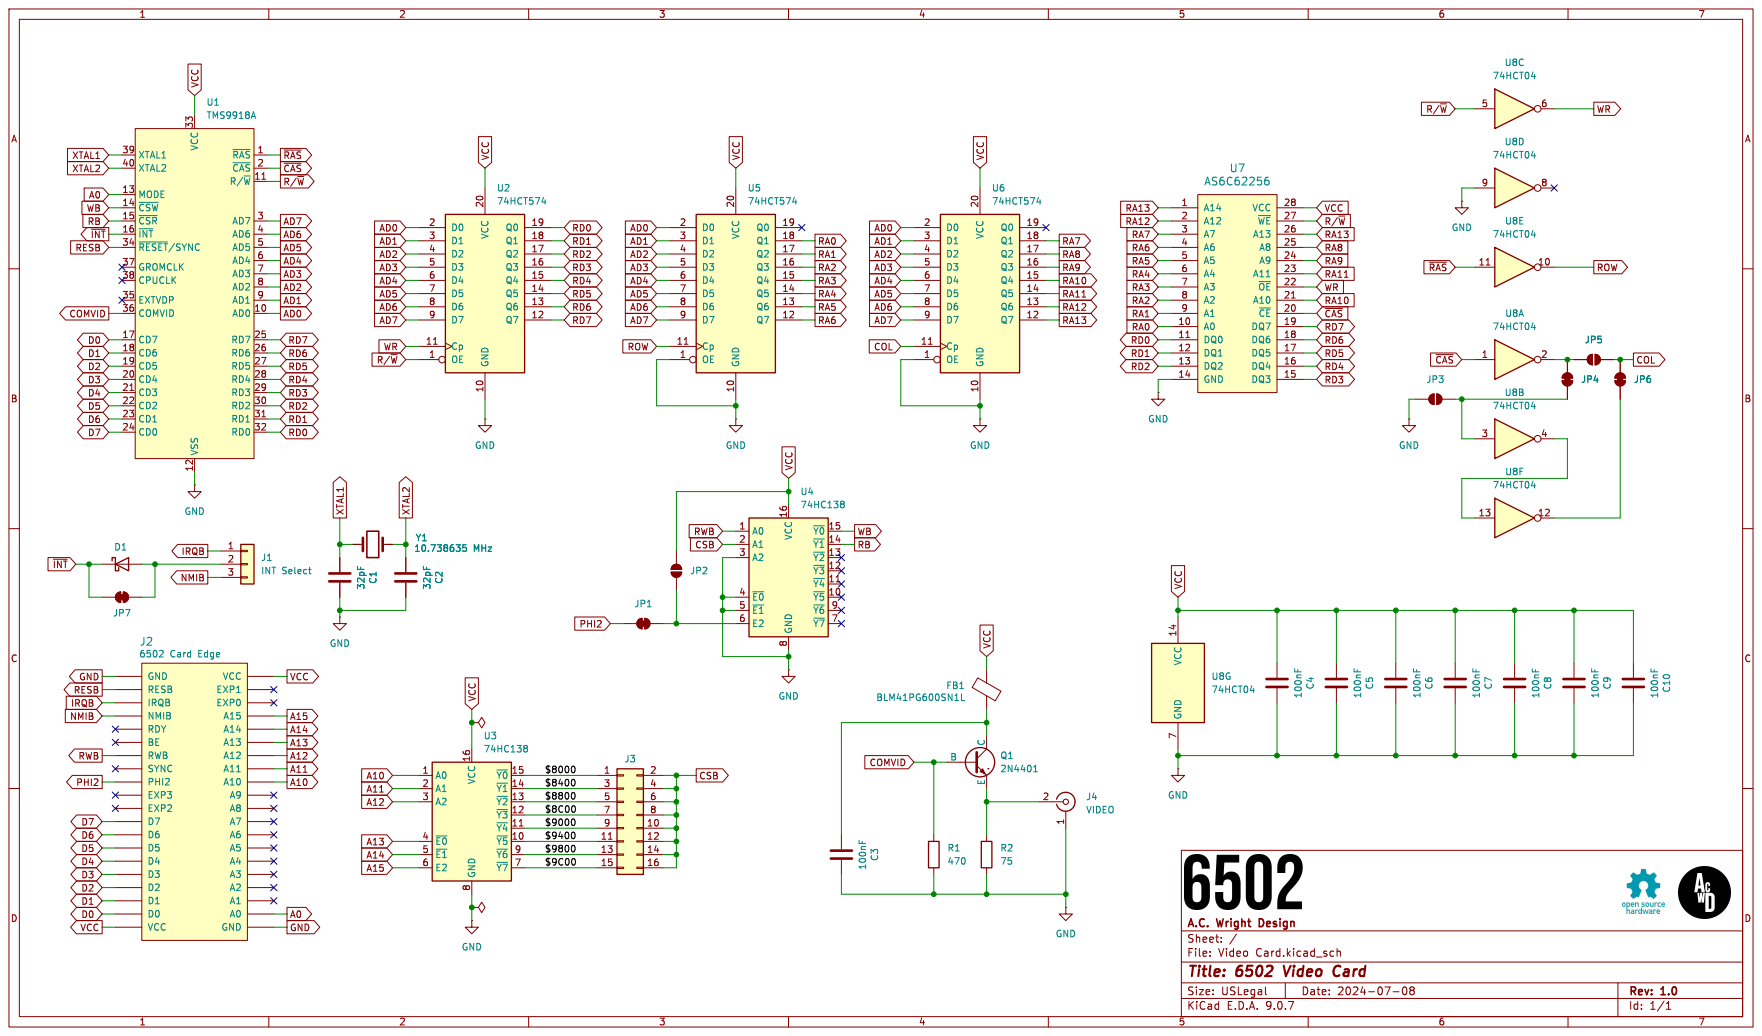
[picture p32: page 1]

Id: 1/1 Title: 6502 Video Card

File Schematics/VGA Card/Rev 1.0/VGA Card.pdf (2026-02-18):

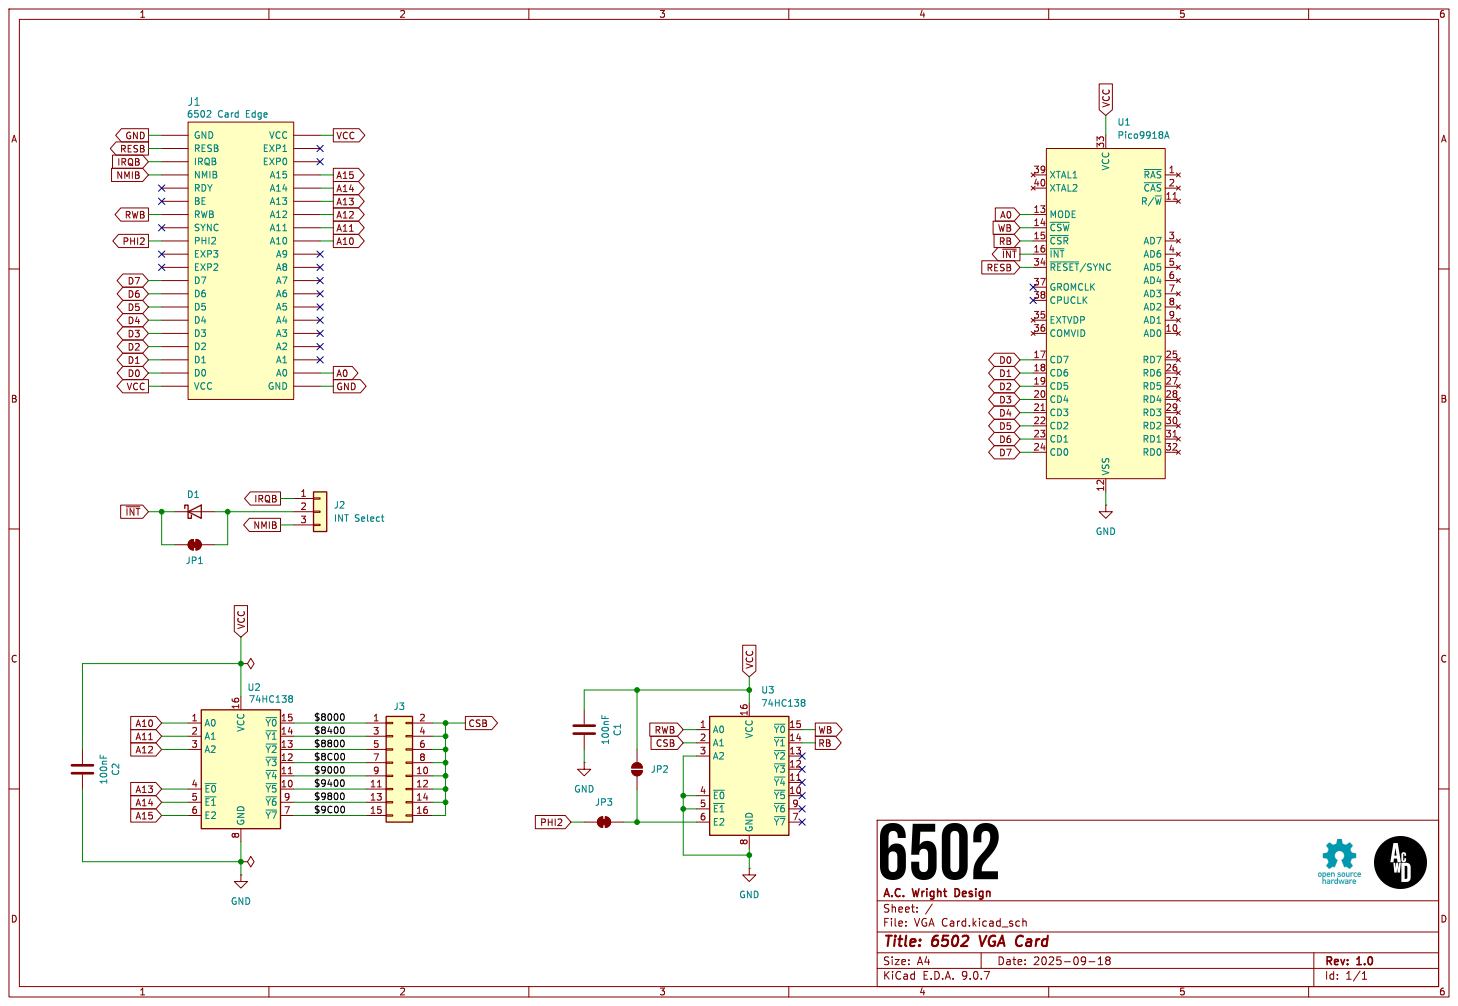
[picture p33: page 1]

Id: 1/1 Title: 6502 VGA Card

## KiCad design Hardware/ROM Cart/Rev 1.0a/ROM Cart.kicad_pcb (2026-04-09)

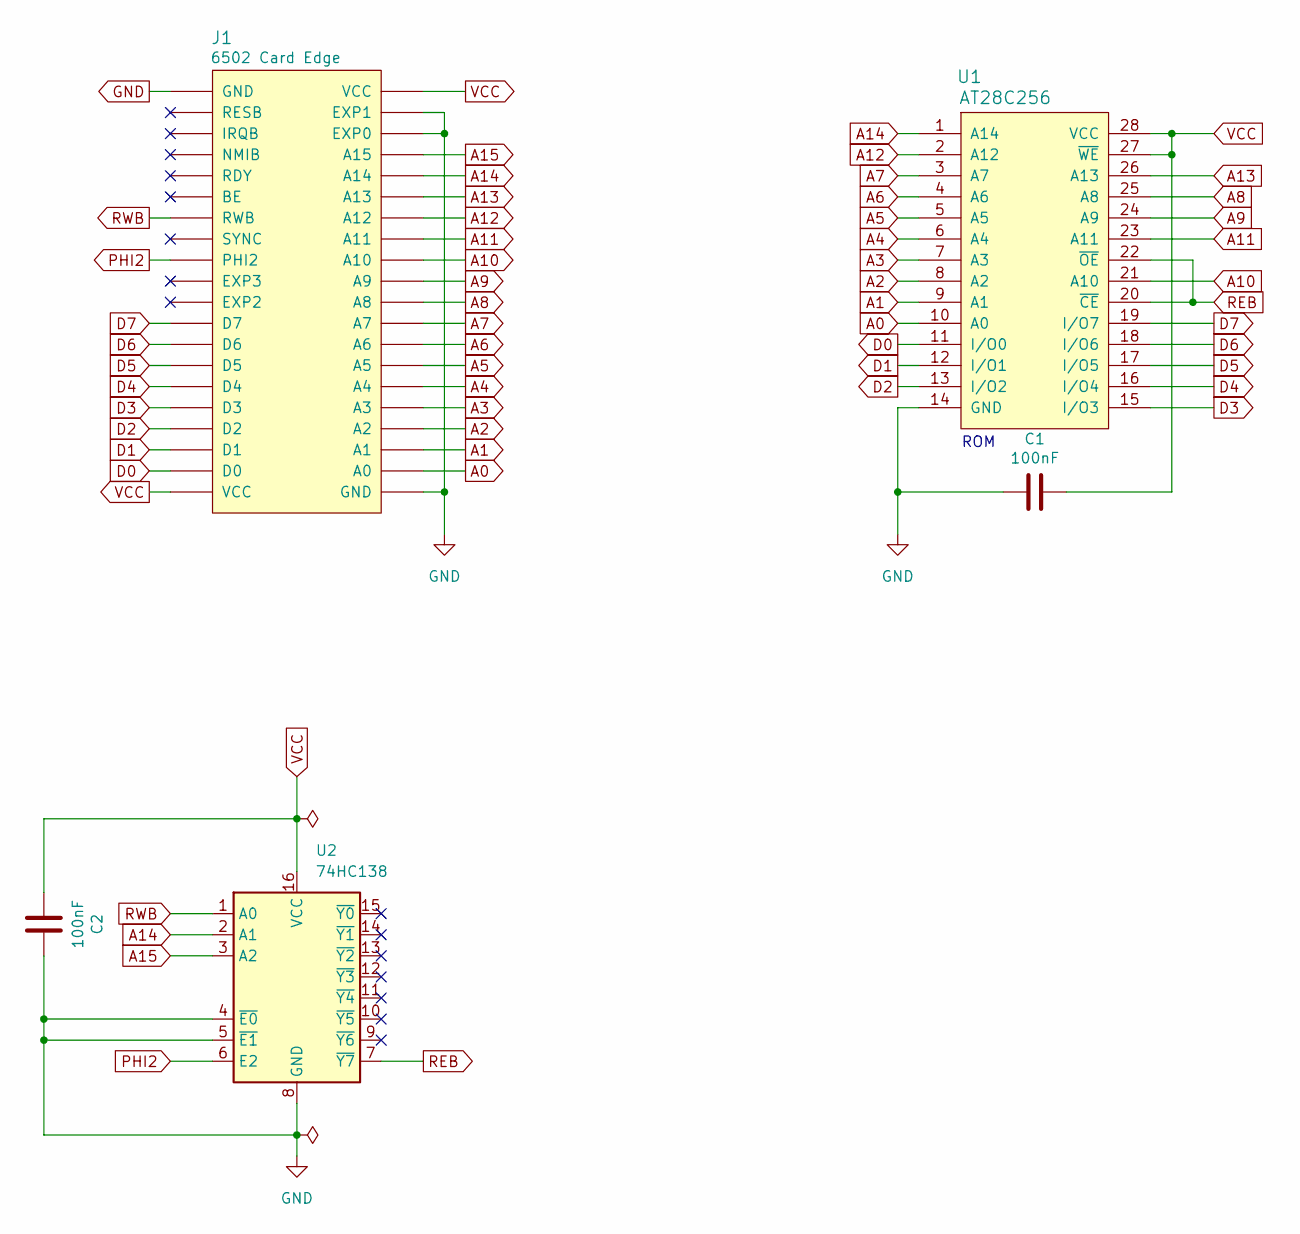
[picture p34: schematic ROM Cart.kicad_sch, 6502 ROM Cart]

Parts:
C1, C2: 100nF; C_Disc_D5.0mm_W2.5mm_P5.00mm
J1: 6502 Card Edge
U1: AT28C256; DIP-28_W15.24mm_Socket_LongPads
U2: 74HC138; DIP-16_W7.62mm_Socket_LongPads

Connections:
A0: J1.A0, U1.10 (A0)
A1: J1.A1, U1.9 (A1)
A2: J1.A2, U1.8 (A2)
A3: J1.A3, U1.7 (A3)
A4: J1.A4, U1.6 (A4)
A5: J1.A5, U1.5 (A5)
A6: J1.A6, U1.4 (A6)
A7: J1.A7, U1.3 (A7)
A8: J1.A8, U1.25 (A8)
A9: J1.A9, U1.24 (A9)
A10: J1.A10, U1.21 (A10)
A11: J1.A11, U1.23 (A11)
A12: J1.A12, U1.2 (A12)
A13: J1.A13, U1.26 (A13)
A14: J1.A14, U1.1 (A14), U2.2 (A1)
A15: J1.A15, U2.3 (A2)
D0: J1.D0, U1.11 (I/O0)
D1: J1.D1, U1.12 (I/O1)
D2: J1.D2, U1.13 (I/O2)
D3: J1.D3, U1.15 (I/O3)
D4: J1.D4, U1.16 (I/O4)
D5: J1.D5, U1.17 (I/O5)
D6: J1.D6, U1.18 (I/O6)
D7: J1.D7, U1.19 (I/O7)
GND: C1.2, C2.2, J1.EXP0, J1.EXP1, J1.GND, U1.14 (GND), U2.4 (~E0), U2.5 (~E1), U2.8 (GND)
PHI2: J1.PHI2, U2.6 (E2)
RB: U1.20 (~CE), U1.22 (~OE), U2.7 (~Y7)
RWB: J1.RWB, U2.1 (A0)
VCC: C1.1, C2.1, J1.VCC, U1.27 (~WE), U1.28 (VCC), U2.16 (VCC)

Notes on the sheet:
ROM

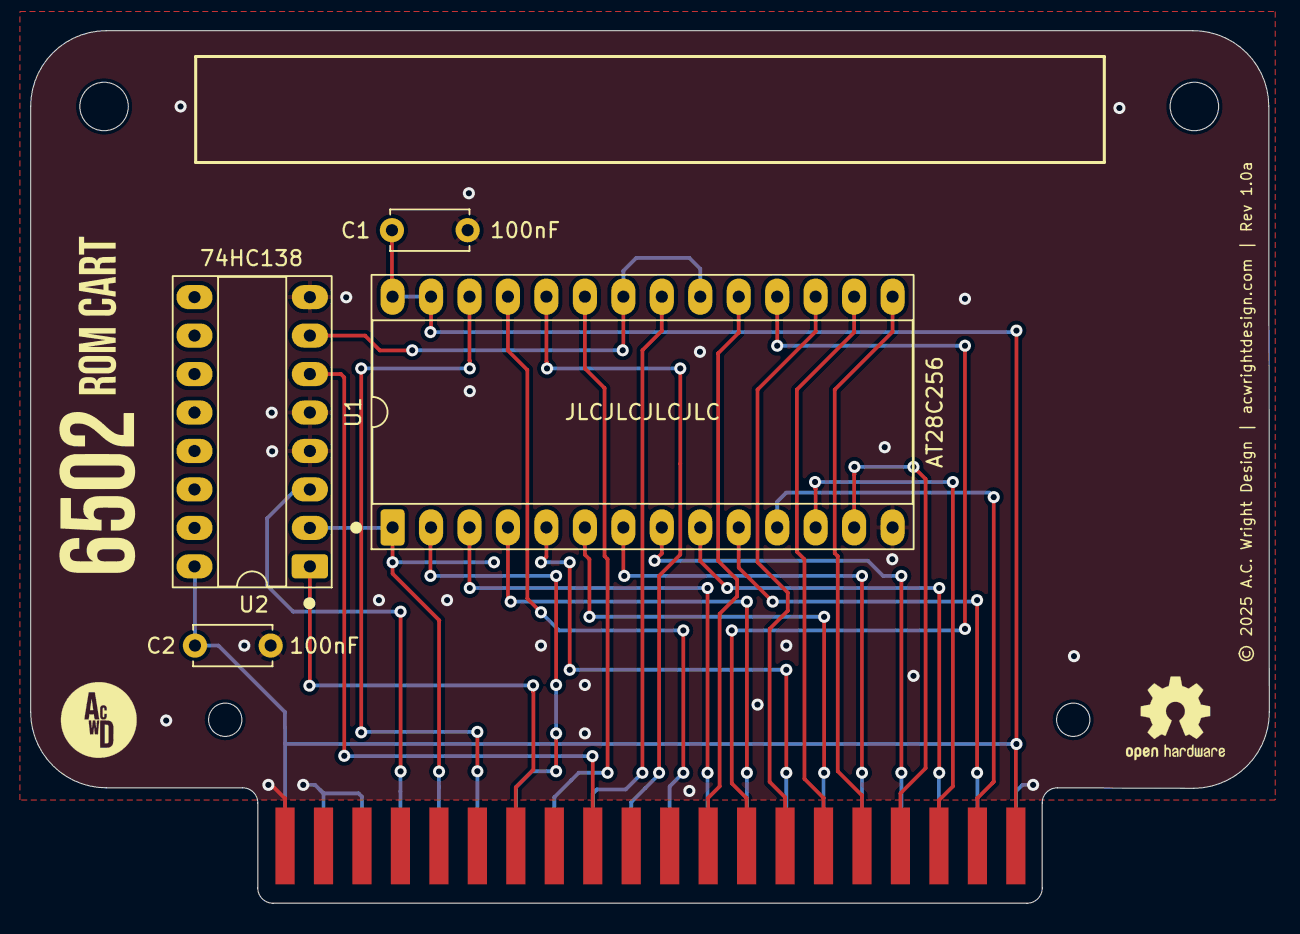
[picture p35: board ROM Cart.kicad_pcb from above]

Board: 2 copper layers, 81.8 x 57.6 mm, 9 parts (0 on the bottom side), 29 nets.

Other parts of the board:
H1, H2: MountingHole; MountingHole_3.2mm_M3
H3, H4: MountingHole; MountingHole_2.2mm_M2

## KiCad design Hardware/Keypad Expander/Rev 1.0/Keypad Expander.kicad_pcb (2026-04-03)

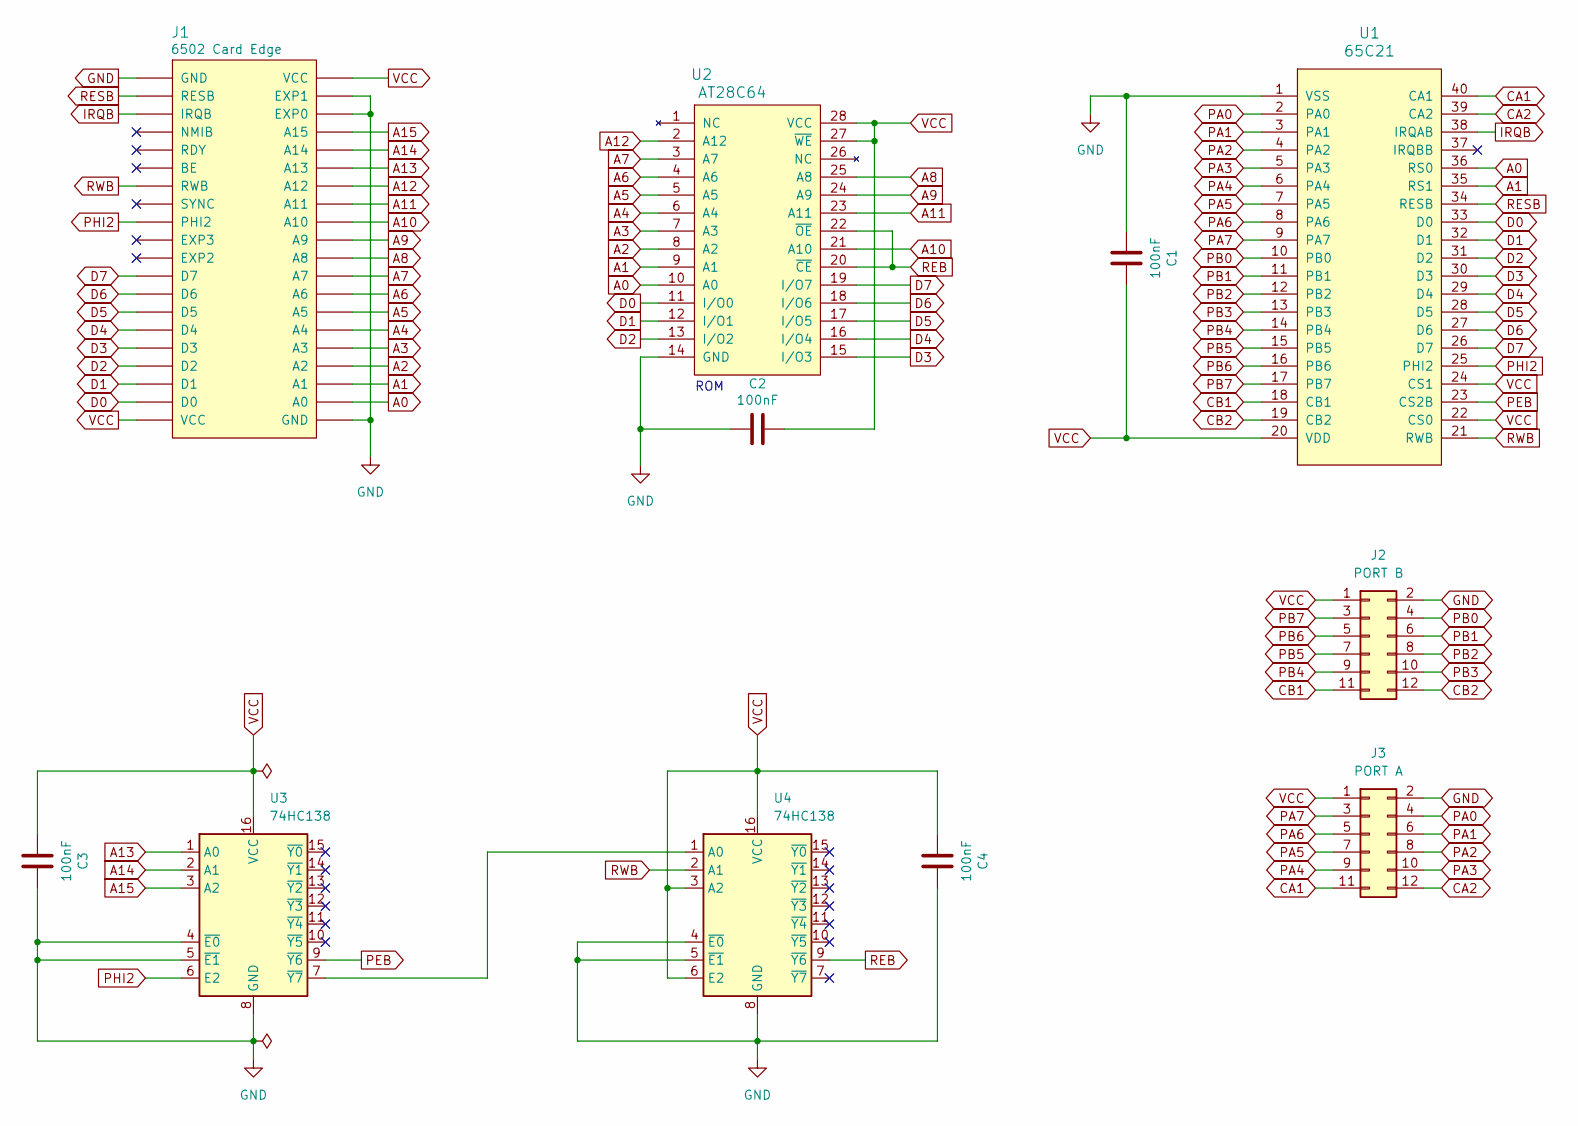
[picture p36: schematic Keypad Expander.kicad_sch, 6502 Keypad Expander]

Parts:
C1: 100nF; C_Disc_D5.0mm_W2.5mm_P5.00mm; LCSC C49678
C2, C3, C4: 100nF; C_Disc_D5.0mm_W2.5mm_P5.00mm
J1: 6502 Card Edge
J2: PORT B; 6502 GPIO Connector
J3: PORT A; 6502 GPIO Connector
U1: 65C21; DIP-40_W15.24mm_Socket_LongPads
U2: AT28C64; DIP-28_W15.24mm_Socket_LongPads
U3, U4: 74HC138; DIP-16_W7.62mm_Socket_LongPads

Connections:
A0: J1.A0, U1.36 (RS0), U2.10 (A0)
A1: J1.A1, U1.35 (RS1), U2.9 (A1)
A2: J1.A2, U2.8 (A2)
A3: J1.A3, U2.7 (A3)
A4: J1.A4, U2.6 (A4)
A5: J1.A5, U2.5 (A5)
A6: J1.A6, U2.4 (A6)
A7: J1.A7, U2.3 (A7)
A8: J1.A8, U2.25 (A8)
A9: J1.A9, U2.24 (A9)
A10: J1.A10, U2.21 (A10)
A11: J1.A11, U2.23 (A11)
A12: J1.A12, U2.2 (A12)
A13: J1.A13, U3.1 (A0)
A14: J1.A14, U3.2 (A1)
A15: J1.A15, U3.3 (A2)
CA1: J3.11, U1.40 (CA1)
CA2: J3.12, U1.39 (CA2)
CB1: J2.11, U1.18 (CB1)
CB2: J2.12, U1.19 (CB2)
D0: J1.D0, U1.33 (D0), U2.11 (I/O0)
D1: J1.D1, U1.32 (D1), U2.12 (I/O1)
D2: J1.D2, U1.31 (D2), U2.13 (I/O2)
D3: J1.D3, U1.30 (D3), U2.15 (I/O3)
D4: J1.D4, U1.29 (D4), U2.16 (I/O4)
D5: J1.D5, U1.28 (D5), U2.17 (I/O5)
D6: J1.D6, U1.27 (D6), U2.18 (I/O6)
D7: J1.D7, U1.26 (D7), U2.19 (I/O7)
GND: C1.1, C2.2, C3.2, C4.2, J1.EXP0, J1.EXP1, J1.GND, J2.2, J3.2, U1.1 (VSS), U2.14 (GND), U3.4 (~E0), U3.5 (~E1), U3.8 (GND), U4.4 (~E0), U4.5 (~E1), U4.8 (GND)
IRQB: J1.IRQB, U1.38 (IRQAB)
unnamed: U3.7 (~Y7), U4.1 (A0)
PA0: J3.4, U1.2 (PA0)
PA1: J3.6, U1.3 (PA1)
PA2: J3.8, U1.4 (PA2)
PA3: J3.10, U1.5 (PA3)
PA4: J3.9, U1.6 (PA4)
PA5: J3.7, U1.7 (PA5)
PA6: J3.5, U1.8 (PA6)
PA7: J3.3, U1.9 (PA7)
PB0: J2.4, U1.10 (PB0)
PB1: J2.6, U1.11 (PB1)
PB2: J2.8, U1.12 (PB2)
PB3: J2.10, U1.13 (PB3)
PB4: J2.9, U1.14 (PB4)
PB5: J2.7, U1.15 (PB5)
PB6: J2.5, U1.16 (PB6)
PB7: J2.3, U1.17 (PB7)
PEB: U1.23 (CS2B), U3.9 (~Y6)
PHI2: J1.PHI2, U1.25 (PHI2), U3.6 (E2)
REB: U2.20 (~CE), U2.22 (~OE), U4.9 (~Y6)
RESB: J1.RESB, U1.34 (RESB)
RWB: J1.RWB, U1.21 (RWB), U4.2 (A1)
VCC: C1.2, C2.1, C3.1, C4.1, J1.VCC, J2.1, J3.1, U1.20 (VDD), U1.22 (CS0), U1.24 (CS1), U2.27 (~WE), U2.28 (VCC), U3.16 (VCC), U4.3 (A2), U4.6 (E2), U4.16 (VCC)

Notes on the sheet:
ROM

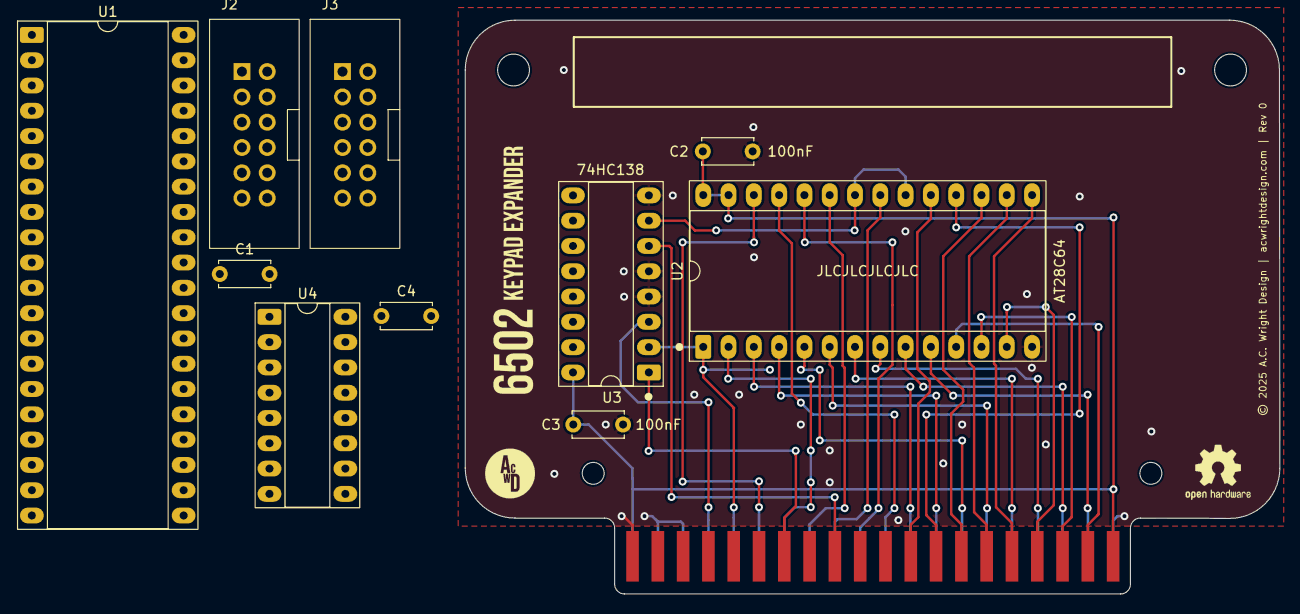
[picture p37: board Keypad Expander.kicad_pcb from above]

Board: 2 copper layers, 81.8 x 57.6 mm, 15 parts (0 on the bottom side), 53 nets.

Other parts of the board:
H1, H2: MountingHole; MountingHole_3.2mm_M3
H3, H4: MountingHole; MountingHole_2.2mm_M2

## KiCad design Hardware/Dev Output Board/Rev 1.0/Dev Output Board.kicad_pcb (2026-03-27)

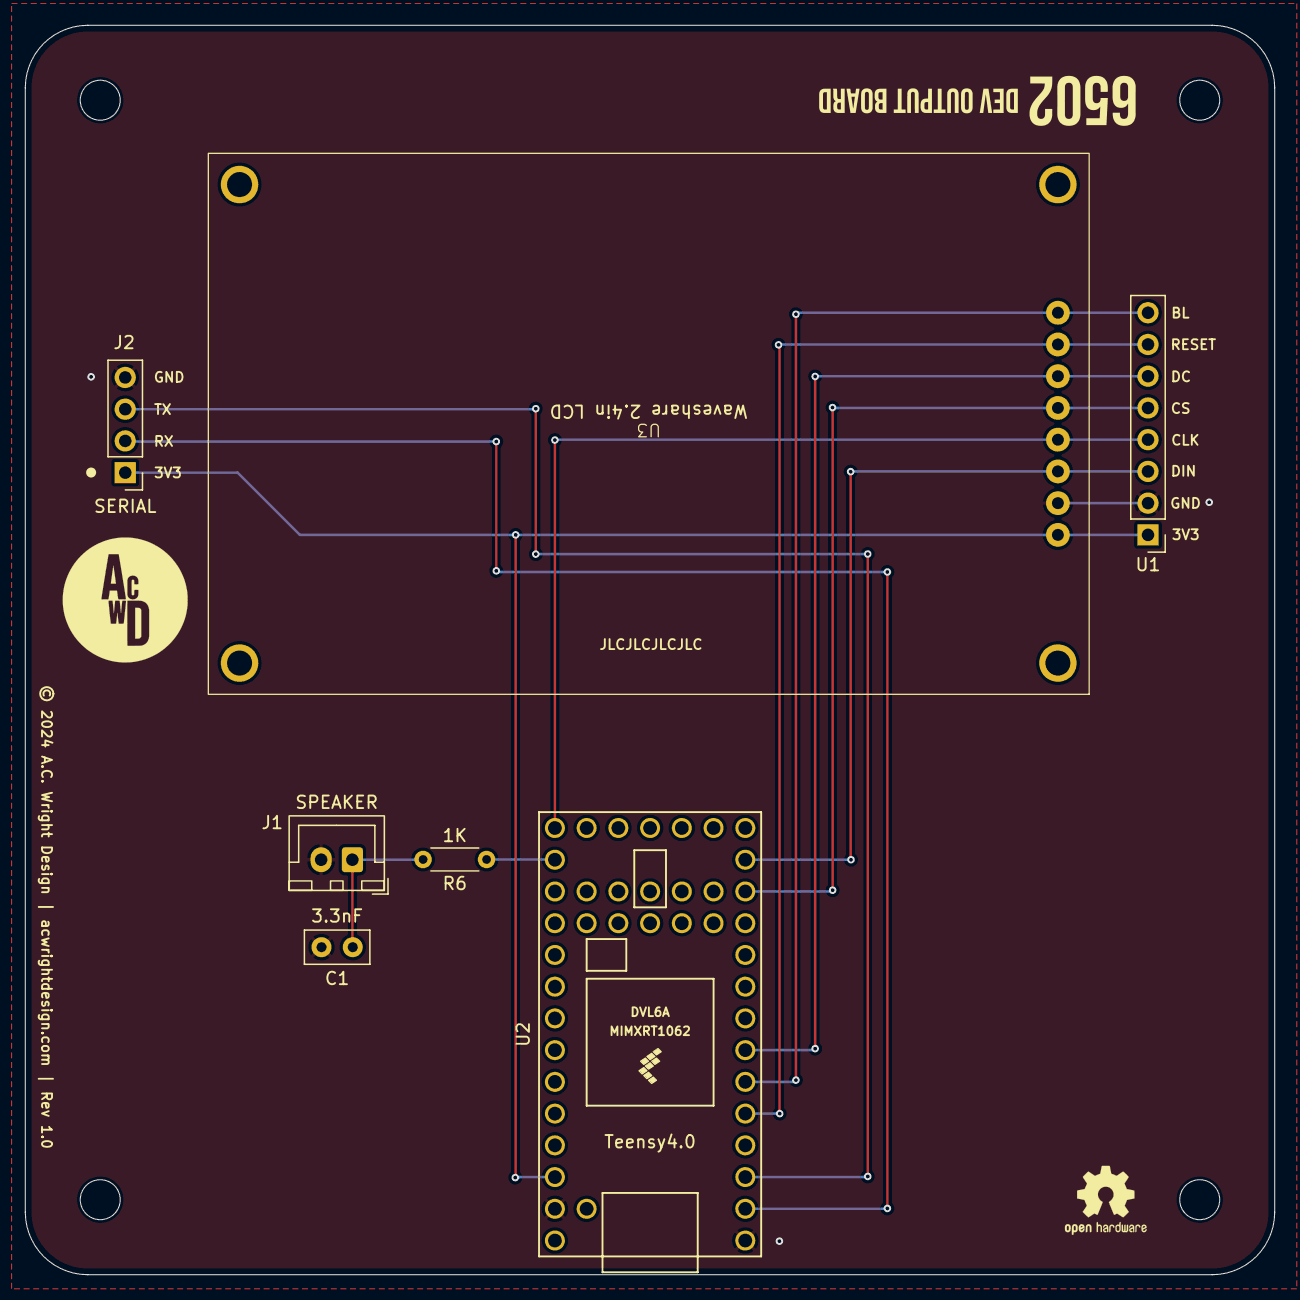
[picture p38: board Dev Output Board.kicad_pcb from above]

Board: 2 copper layers, 100.0 x 100.0 mm, 11 parts (0 on the bottom side), 12 nets.

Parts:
C1: 3.3nF; C_Disc_D5.0mm_W2.5mm_P2.50mm
H1, H2, H3, H4: MountingHole; MountingHole_3.2mm_M3
J1: SPEAKER; JST_XH_B2B-XH-A_1x02_P2.50mm_Vertical
J2: SERIAL; PinHeader_1x04_P2.54mm_Vertical
R6: 1K; R_Axial_DIN0204_L3.6mm_D1.6mm_P5.08mm_Horizontal
U1: Waveshare 2.4in LCD Header; PinHeader_1x08_P2.54mm_Vertical
U2: Teensy4.0; Teensy40
U3: Waveshare 2.4in LCD

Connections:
3V3: J2.1, U1.1 (VCC), U2.31 (3V3), U3.1 (VCC)
GND: C1.2, J1.2, J2.4, U1.2 (GND), U2.1 (GND), U2.32 (GND), U3.2 (GND)
LCD_BL: U1.8 (BL), U2.6 (4_BCLK2), U3.8 (BL)
LCD_CLK: U1.4 (CLK), U2.20 (13_SCK_CRX1_LED), U3.4 (CLK)
LCD_CS: U1.5 (CS), U2.12 (10_CS_MQSR), U3.5 (CS)
LCD_DATA: U1.3 (DIN), U2.13 (11_MOSI_CTX1), U3.3 (DIN)
LCD_DC: U1.6 (DC), U2.7 (5_IN2), U3.6 (DC)
LCD_RESET: U1.7 (RST), U2.5 (3_LRCLK2), U3.7 (RST)
unnamed: C1.1, J1.1, R6.2
RX: J2.2, U2.2 (0_RX1_CRX2_CS1)
SPEAKER: R6.1, U2.21 (14_A0_TX3_SPDIF_OUT)
TX: J2.3, U2.3 (1_TX1_CTX2_MISO1)

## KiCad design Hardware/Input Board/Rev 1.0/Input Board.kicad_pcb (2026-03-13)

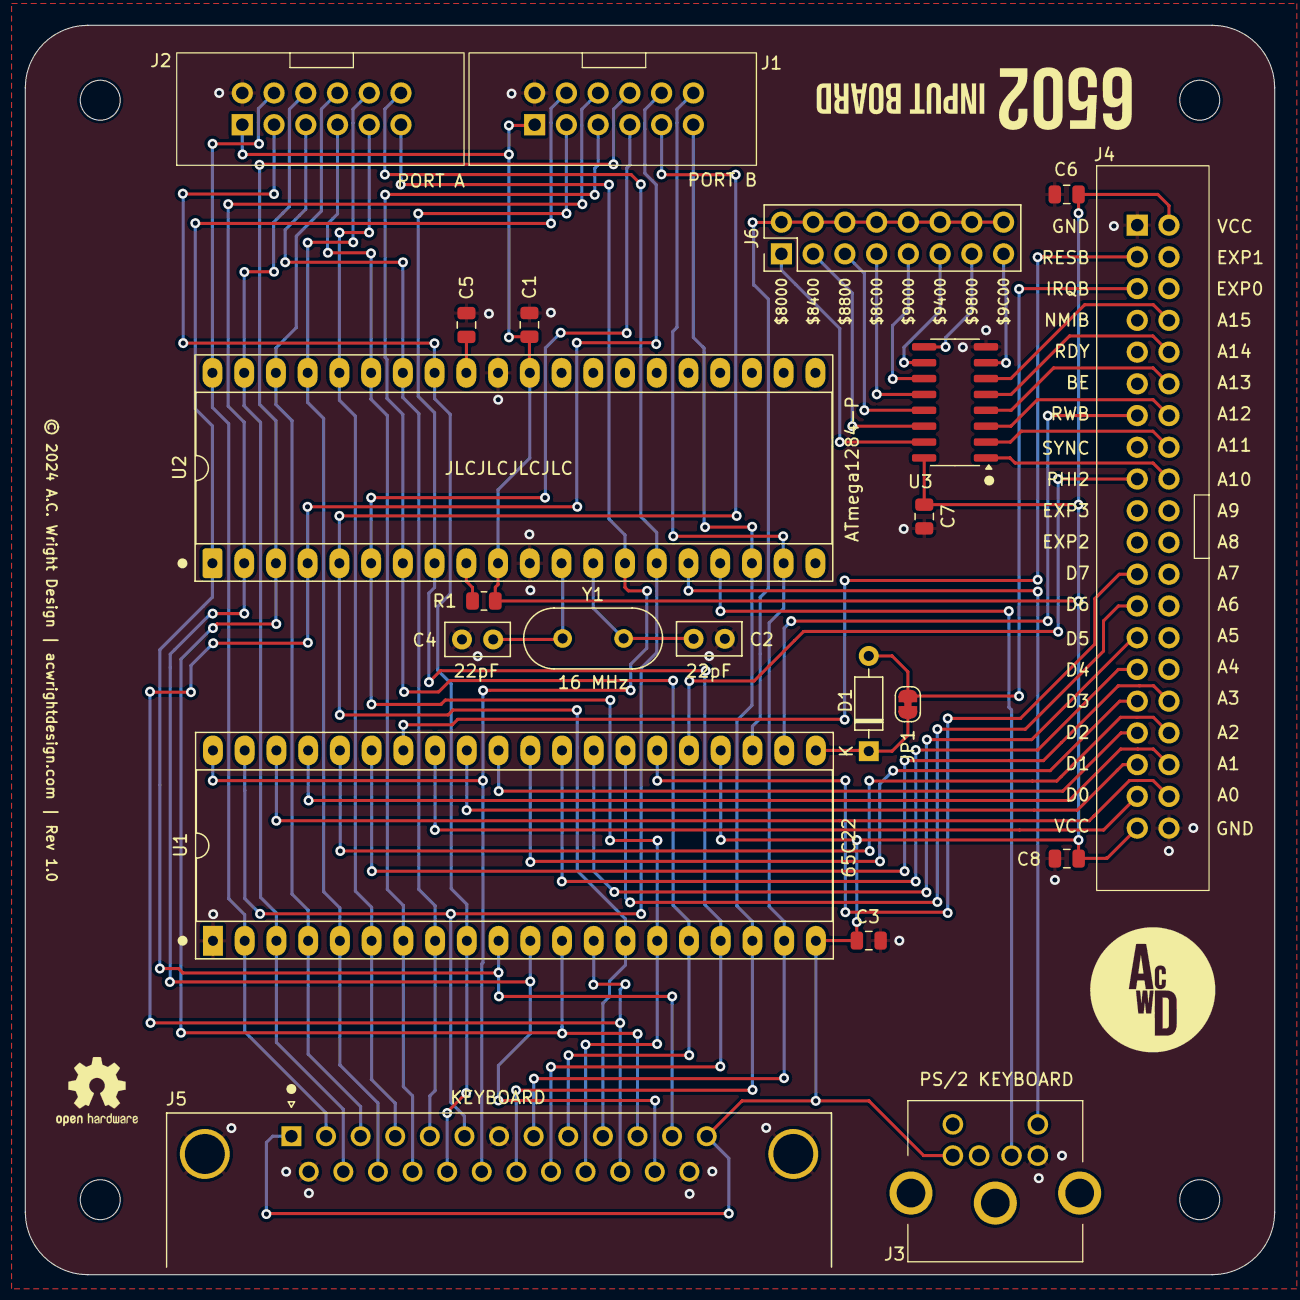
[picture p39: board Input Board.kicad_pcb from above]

Board: 2 copper layers, 100.0 x 100.0 mm, 25 parts (0 on the bottom side), 60 nets.

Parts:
C1, C3, C5, C6, C7, C8: 100nF; C_0805_2012Metric
C2, C4: 22pF; C_Disc_D5.0mm_W2.5mm_P2.50mm
D1: D_Schottky; D_DO-35_SOD27_P7.62mm_Horizontal
H1, H2, H3, H4: MountingHole; MountingHole_3.2mm_M3
J1: PORT B; 6502 GPIO Connector
J2: PORT A; 6502 GPIO Connector
J3: PS/2 KEYBOARD; KMDGX-6S-BS
J4: 6502 Bus; 6502 Bus Connector
J5: KEYBOARD; DSUB-25_Pins_Horizontal_P2.77x2.84mm_EdgePinOffset7.70mm_Ho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
J6: Conn_02x08_Odd_Even; PinHeader_2x08_P2.54mm_Vertical
JP1: SolderJumper_2_Bridged; SolderJumper-2_P1.3mm_Bridged_RoundedPad1.0x1.5mm
R1: 1K; R_0805_2012Metric
U1: 65C22; DIP-40_W15.24mm_Socket_LongPads
U2: ATmega1284-P; DIP-40_W15.24mm_Socket_LongPads
U3: 74HC138; SOIC-16_3.9x9.9mm_P1.27mm
Y1: 16 MHz; Crystal_HC49-U_Vertical

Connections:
/$8C00: J6.7, U3.12 (~Y3)
/$9C00: J6.15, U3.7 (~Y7)
/$8000: J6.1, U3.15 (~Y0)
/$8400: J6.3, U3.14 (~Y1)
/$8800: J6.5, U3.13 (~Y2)
/$9000: J6.9, U3.11 (~Y4)
/$9400: J6.11, U3.10 (~Y5)
/$9800: J6.13, U3.9 (~Y6)
A0: J4.38, U1.38 (RS0)
A1: J4.36, U1.37 (RS1)
A2: J4.34, U1.36 (RS2)
A3: J4.32, U1.35 (RS3)
A10: J4.18, U3.1 (A0)
A11: J4.16, U3.2 (A1)
A12: J4.14, U3.3 (A2)
A13: J4.12, U3.4 (~E0)
A14: J4.10, U3.5 (~E1)
A15: J4.8, U3.6 (E2)
CA1: J2.11, J5.19, U1.40 (CA1), U2.14 (PD0)
CA2: J2.12, J5.6, U1.39 (CA2), U2.15 (PD1)
CB1: J1.11, J5.20, U1.18 (CB1), U2.18 (PD4)
CB2: J1.12, J5.8, U1.19 (CB2), U2.19 (PD5)
CSB: J6.2, J6.4, J6.6, J6.8, J6.10, J6.12, J6.14, J6.16, U1.23 (CS2B)
D0: J4.37, U1.33 (D0)
D1: J4.35, U1.32 (D1)
D2: J4.33, U1.31 (D2)
D3: J4.31, U1.30 (D3)
D4: J4.29, U1.29 (D4)
D5: J4.27, U1.28 (D5)
D6: J4.25, U1.27 (D6)
D7: J4.23, U1.26 (D7)
GND: C1.1, C2.2, C3.1, C4.2, C5.1, C6.2, C7.2, C8.1, J1.2, J2.2, J3.3, J4.1, J4.40, J5.0 (PAD), J5.7, J5.14, J5.25, U1.1 (VSS), U2.11 (GND), U2.31 (GND), U3.8 (GND)
IRQB: D1.2 (A), J4.5, JP1.2 (B)
unnamed: D1.1 (K), JP1.1 (A), U1.21 (IRQB)
unnamed: C5.2, U2.32 (AREF)
unnamed: C2.1, U2.13 (XTAL1), Y1.2
unnamed: C4.1, U2.12 (XTAL2), Y1.1
unnamed: R1.2, U2.9 (~RESET)
PA0: J2.4, J5.2, U1.2 (PA0), U2.40 (PA0)
PA1: J2.6, J5.15, U1.3 (PA1), U2.39 (PA1)
PA2: J2.8, J5.3, U1.4 (PA2), U2.38 (PA2)
PA3: J2.10, J5.16, U1.5 (PA3), U2.37 (PA3)
PA4: J2.9, J5.4, U1.6 (PA4), U2.36 (PA4)
PA5: J2.7, J5.17, U1.7 (PA5), U2.35 (PA5)
PA6: J2.5, J5.5, U1.8 (PA6), U2.34 (PA6)
PA7: J2.3, J5.18, U1.9 (PA7), U2.33 (PA7)
PB0: J1.4, J5.12, U1.10 (PB0), U2.1 (PB0)
PB1: J1.6, J5.24, U1.11 (PB1), U2.2 (PB1)
PB2: J1.8, J5.11, U1.12 (PB2), U2.3 (PB2)
PB3: J1.10, J5.23, U1.13 (PB3), U2.4 (PB3)
PB4: J1.9, J5.10, U1.14 (PB4), U2.5 (PB4)
PB5: J1.7, J5.22, U1.15 (PB5), U2.6 (PB5)
PB6: J1.5, J5.9, U1.16 (PB6), U2.7 (PB6)
PB7: J1.3, J5.21, U1.17 (PB7), U2.8 (PB7)
PHI2: J4.17, U1.25 (PHI2)
PS2CLK: J3.5, U2.16 (PD2)
PS2DATA: J3.1, U2.17 (PD3)
RESB: J4.3, U1.34 (RESB)
RWB: J4.13, U1.22 (RWB)
VCC: C1.2, C3.2, C6.1, C7.1, C8.2, J1.1, J2.1, J3.4, J4.2, J4.39, J5.1, J5.13, R1.1, U1.20 (VDD), U1.24 (CS1), U2.10 (VCC), U2.30 (AVCC), U3.16 (VCC)

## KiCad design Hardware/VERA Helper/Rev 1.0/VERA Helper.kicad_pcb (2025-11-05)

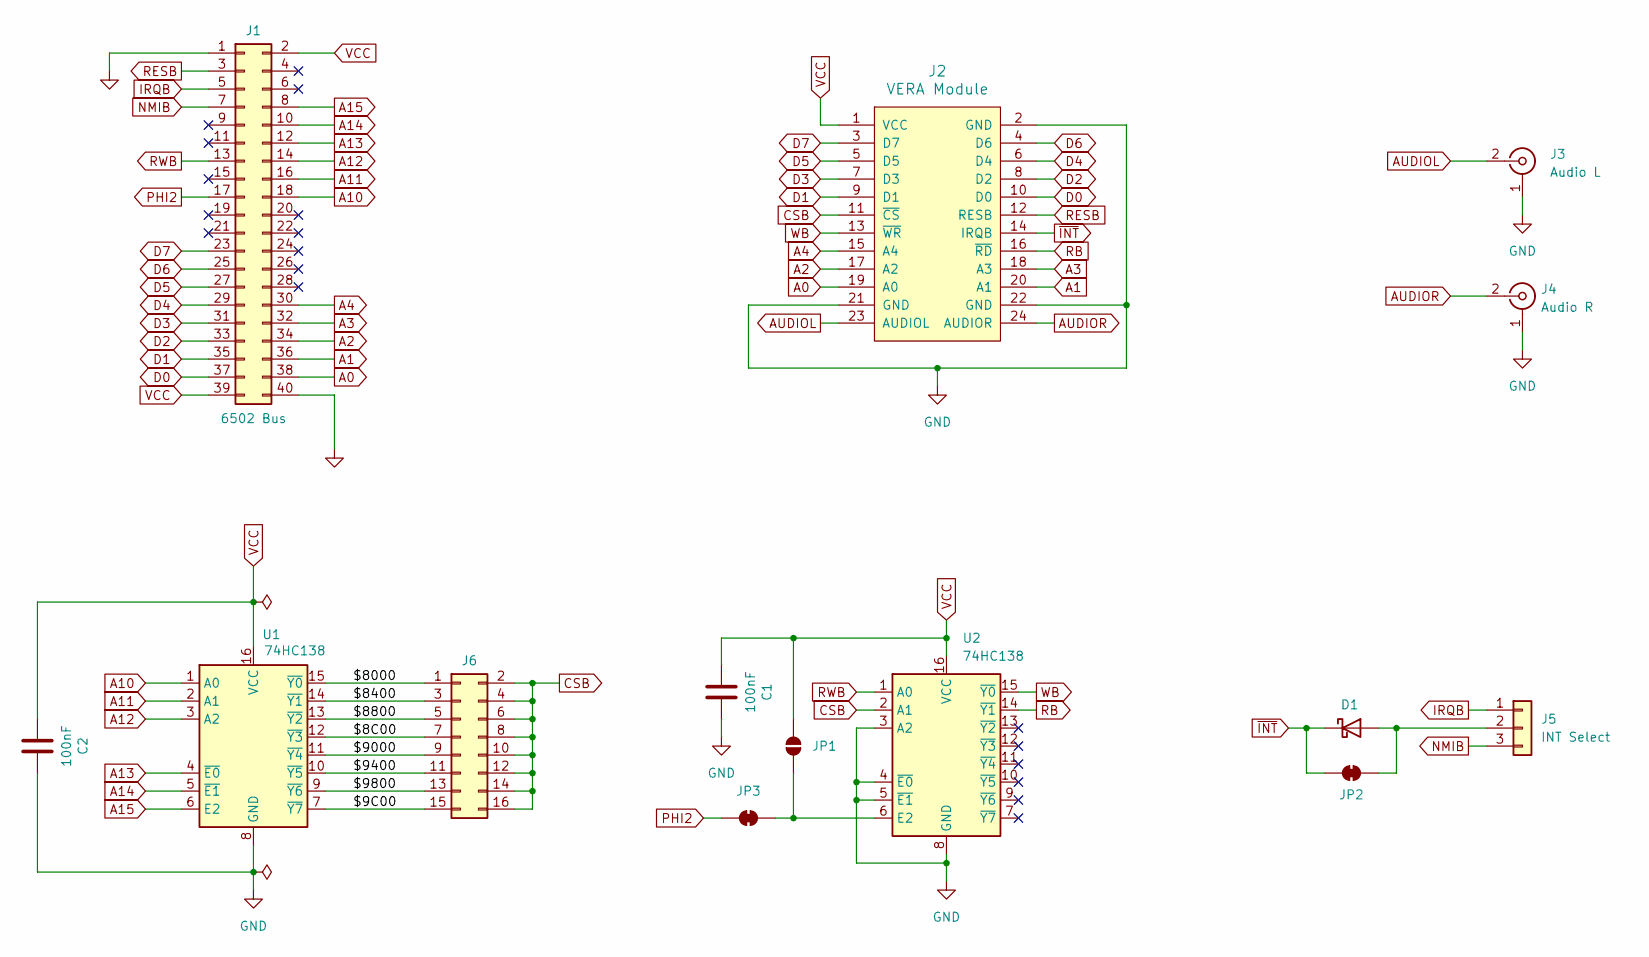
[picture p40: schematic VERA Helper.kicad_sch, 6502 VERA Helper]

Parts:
C1, C2: 100nF; C_Disc_D5.0mm_W2.5mm_P5.00mm; LCSC C49678
D1: D_Schottky; D_DO-35_SOD27_P7.62mm_Horizontal
J1: 6502 Bus; 6502 Bus Connector
J2: VERA Module; PinHeader_2x12_P2.54mm_Vertical
J3: Audio L; SWITCHCRAFT_PJRAN1X1U02X
J4: Audio R; SWITCHCRAFT_PJRAN1X1U02X
J5: INT Select; PinHeader_1x03_P2.54mm_Vertical
J6: Conn_02x08_Odd_Even; PinHeader_2x08_P2.54mm_Vertical
JP1: SolderJumper_2_Open; SolderJumper-2_P1.3mm_Open_RoundedPad1.0x1.5mm
JP2, JP3: SolderJumper_2_Bridged; SolderJumper-2_P1.3mm_Bridged_RoundedPad1.0x1.5mm
U1, U2: 74HC138; DIP-16_W7.62mm_Socket_LongPads; LCSC C5602

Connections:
/$8C00: J6.7, U1.12 (~Y3)
/$9C00: J6.15, U1.7 (~Y7)
/$8000: J6.1, U1.15 (~Y0)
/$8400: J6.3, U1.14 (~Y1)
/$8800: J6.5, U1.13 (~Y2)
/$9000: J6.9, U1.11 (~Y4)
/$9400: J6.11, U1.10 (~Y5)
/$9800: J6.13, U1.9 (~Y6)
A0: J1.38, J2.19 (A0)
A1: J1.36, J2.20 (A1)
A2: J1.34, J2.17 (A2)
A3: J1.32, J2.18 (A3)
A4: J1.30, J2.15 (A4)
A10: J1.18, U1.1 (A0)
A11: J1.16, U1.2 (A1)
A12: J1.14, U1.3 (A2)
A13: J1.12, U1.4 (~E0)
A14: J1.10, U1.5 (~E1)
A15: J1.8, U1.6 (E2)
AUDIOL: J2.23 (AUDIOL), J3.2 (In)
AUDIOR: J2.24 (AUDIOR), J4.2 (In)
CSB: J2.11 (~CS), J6.2, J6.4, J6.6, J6.8, J6.10, J6.12, J6.14, J6.16, U2.2 (A1)
D0: J1.37, J2.10 (D0)
D1: J1.35, J2.9 (D1)
D2: J1.33, J2.8 (D2)
D3: J1.31, J2.7 (D3)
D4: J1.29, J2.6 (D4)
D5: J1.27, J2.5 (D5)
D6: J1.25, J2.4 (D6)
D7: J1.23, J2.3 (D7)
GND: C1.2, C2.2, J1.1, J1.40, J2.2 (GND), J2.21 (GND), J2.22 (GND), J3.1 (Ext), J4.1 (Ext), U1.8 (GND), U2.3 (A2), U2.4 (~E0), U2.5 (~E1), U2.8 (GND)
IRQB: J1.5, J5.1
NMIB: J1.7, J5.3
unnamed: D1.2 (A), J5.2, JP2.2 (B)
unnamed: JP1.2 (B), JP3.1 (A), U2.6 (E2)
PHI2: J1.17, JP3.2 (B)
RB: J2.16 (~RD), U2.14 (~Y1)
RESB: J1.3, J2.12 (RESB)
RWB: J1.13, U2.1 (A0)
VCC: C1.1, C2.1, J1.2, J1.39, J2.1 (VCC), JP1.1 (A), U1.16 (VCC), U2.16 (VCC)
WB: J2.13 (~WR), U2.15 (~Y0)
~INT: D1.1 (K), J2.14 (IRQB), JP2.1 (A)

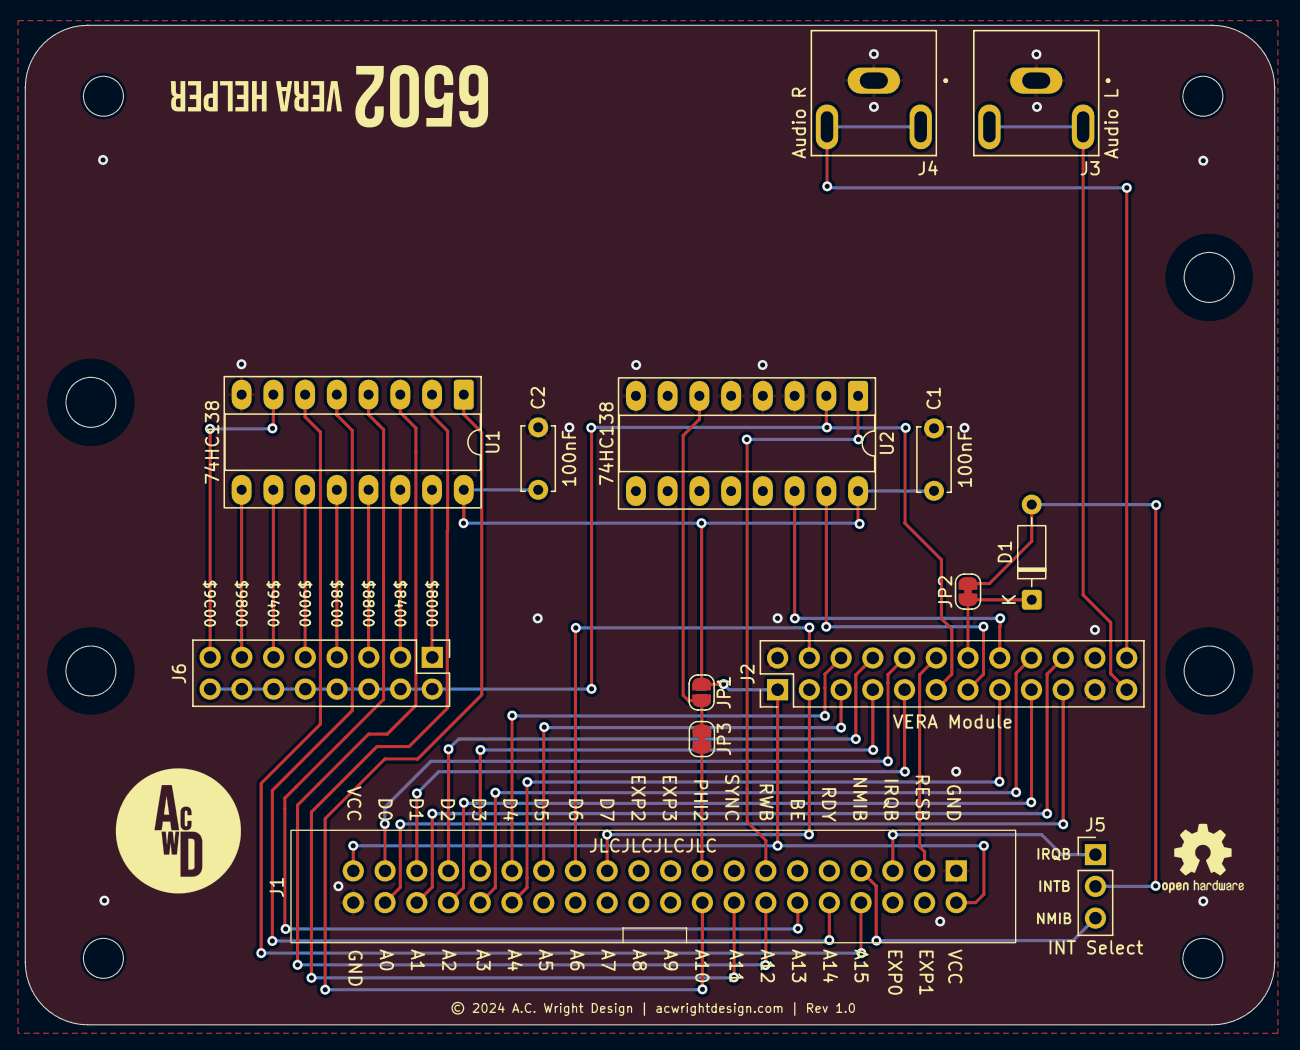
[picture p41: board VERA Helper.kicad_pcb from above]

Board: 2 copper layers, 100.0 x 80.0 mm, 18 parts (0 on the bottom side), 42 nets.

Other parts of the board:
H1, H2, H3, H4: MountingHole; MountingHole_3.2mm_M3

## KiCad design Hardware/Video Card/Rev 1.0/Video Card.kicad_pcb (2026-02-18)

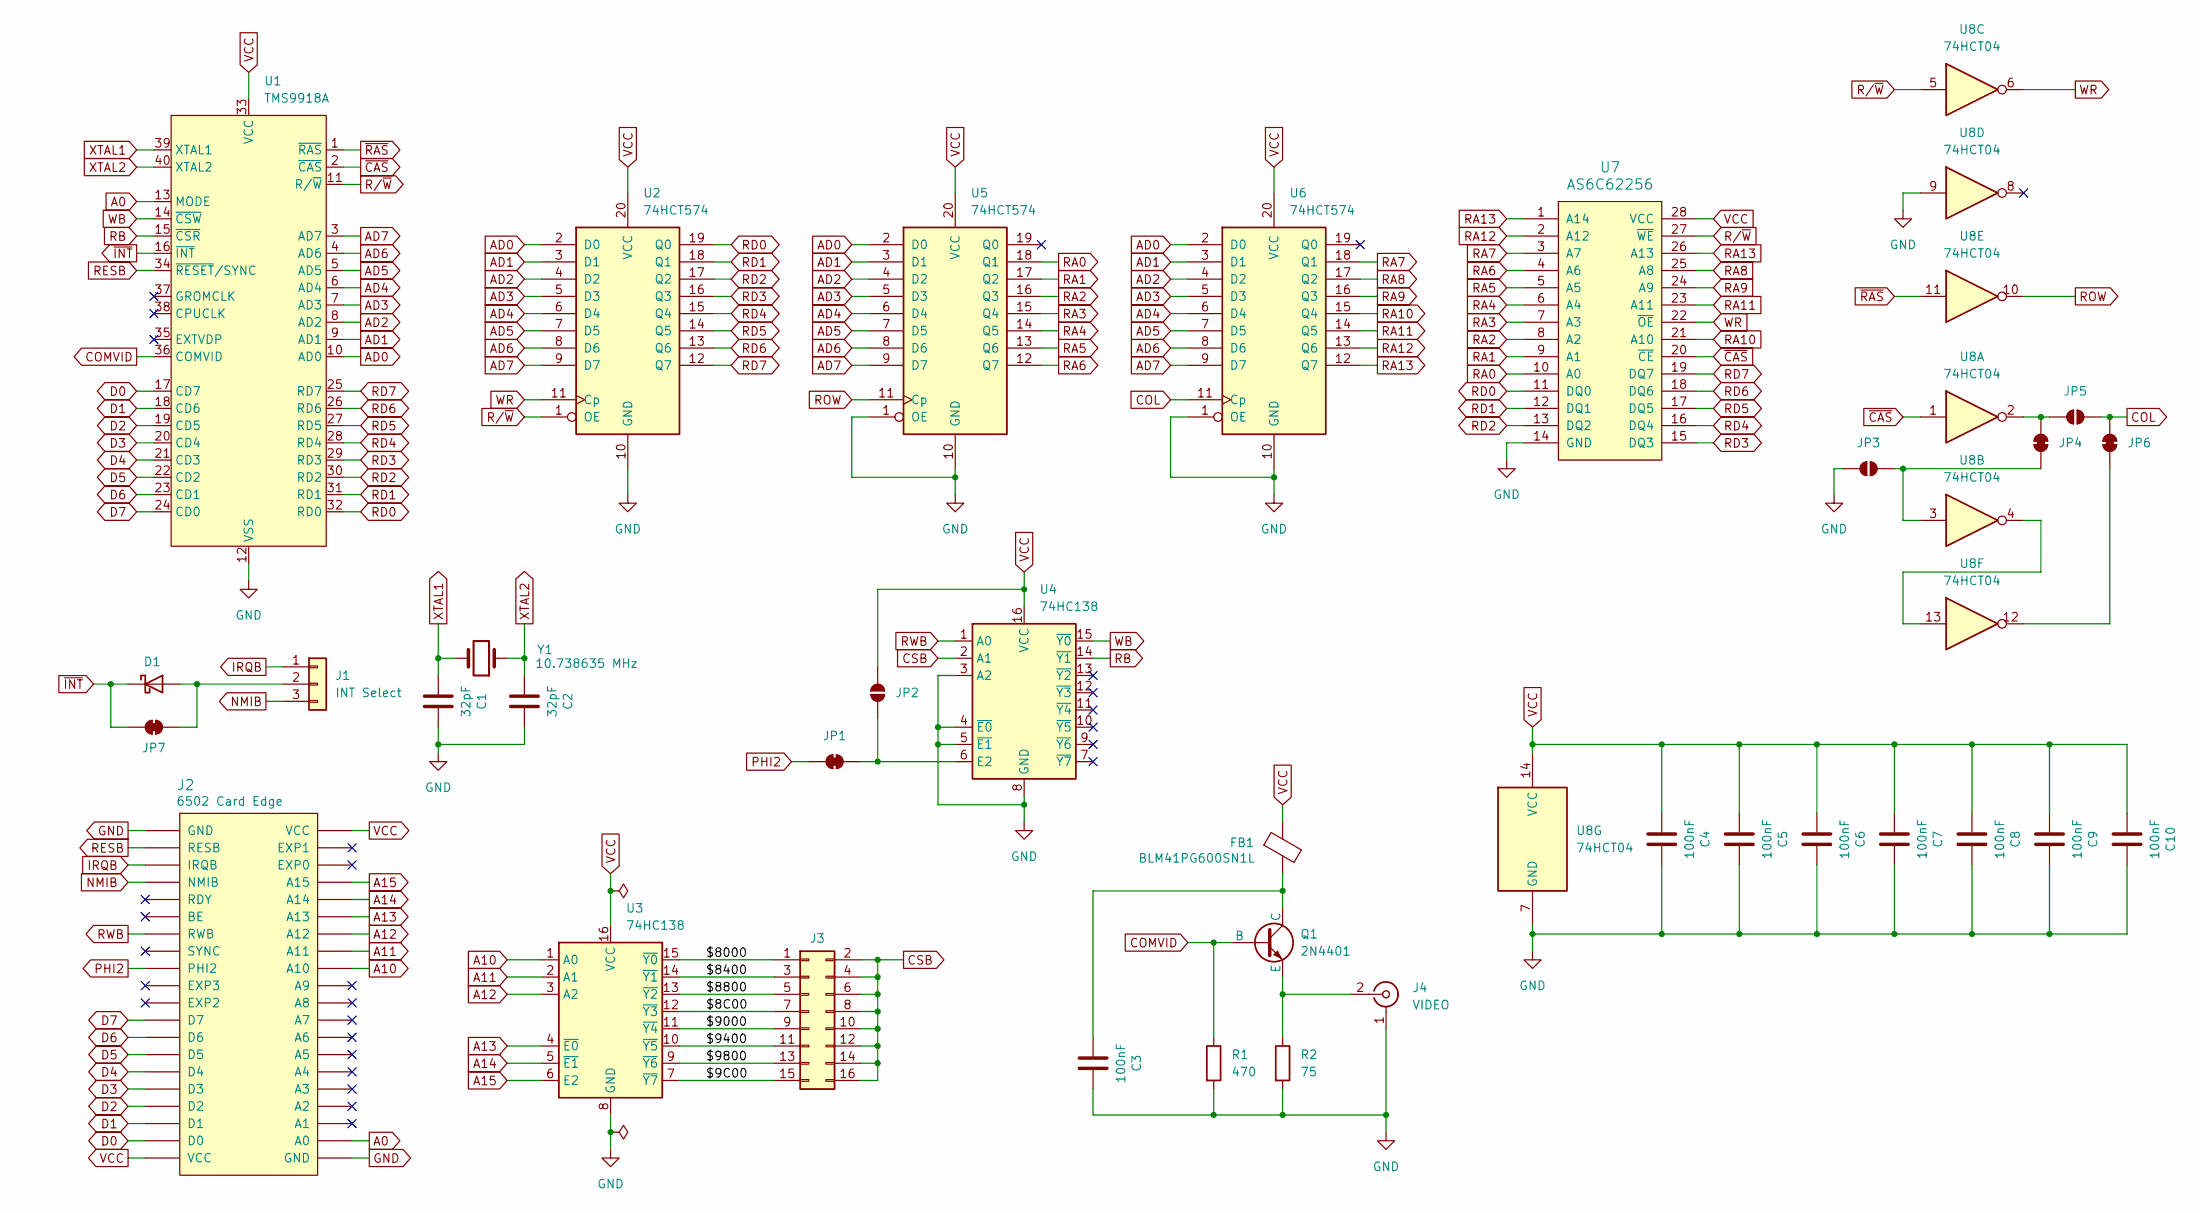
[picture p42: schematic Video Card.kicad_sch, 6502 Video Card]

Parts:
C1, C2: 32pF; C_Disc_D5.0mm_W2.5mm_P2.50mm; LCSC C107114
C3, C4, C5, C6, C7, C8, C9, C10: 100nF; C_0805_2012Metric; LCSC C49678
D1: D_Schottky; D_DO-35_SOD27_P7.62mm_Horizontal
FB1: BLM41PG600SN1L; L_1806_4516Metric; LCSC C85844
J1: INT Select; PinHeader_1x03_P2.54mm_Vertical
J2: 6502 Card Edge
J3: Conn_02x08_Odd_Even; PinHeader_2x08_P2.54mm_Vertical
J4: VIDEO; SWITCHCRAFT_PJRAN1X1U04X
JP1, JP4, JP6, JP7: SolderJumper_2_Bridged; SolderJumper-2_P1.3mm_Bridged_RoundedPad1.0x1.5mm
JP2, JP3, JP5: SolderJumper_2_Open; SolderJumper-2_P1.3mm_Open_RoundedPad1.0x1.5mm
Q1: 2N4401; TO-92_HandSolder
R1: 470; R_0805_2012Metric; LCSC C17710
R2: 75; R_0805_2012Metric; LCSC C17820
U1: TMS9918A; DIP-40_W15.24mm_Socket_LongPads
U2, U5, U6: 74HCT574; SOIC-20W_7.5x12.8mm_P1.27mm; LCSC C6001
U3, U4: 74HC138; SOIC-16_3.9x9.9mm_P1.27mm; LCSC C5602
U7: AS6C62256; DIP-28_W15.24mm_Socket_LongPads
U8: 74HCT04; SO-14_3.9x8.65mm_P1.27mm; LCSC C672096
Y1: 10.738635 MHz; Crystal_HC49-U_Vertical; Mouser 774-MP107-E

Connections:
/$8C00: J3.7, U3.12 (~Y3)
/$9C00: J3.15, U3.7 (~Y7)
/$8000: J3.1, U3.15 (~Y0)
/$8400: J3.3, U3.14 (~Y1)
/$8800: J3.5, U3.13 (~Y2)
/$9000: J3.9, U3.11 (~Y4)
/$9400: J3.11, U3.10 (~Y5)
/$9800: J3.13, U3.9 (~Y6)
A0: J2.A0, U1.13 (MODE)
A10: J2.A10, U3.1 (A0)
A11: J2.A11, U3.2 (A1)
A12: J2.A12, U3.3 (A2)
A13: J2.A13, U3.4 (~E0)
A14: J2.A14, U3.5 (~E1)
A15: J2.A15, U3.6 (E2)
AD0: U1.10 (AD0), U2.2 (D0), U5.2 (D0), U6.2 (D0)
AD1: U1.9 (AD1), U2.3 (D1), U5.3 (D1), U6.3 (D1)
AD2: U1.8 (AD2), U2.4 (D2), U5.4 (D2), U6.4 (D2)
AD3: U1.7 (AD3), U2.5 (D3), U5.5 (D3), U6.5 (D3)
AD4: U1.6 (AD4), U2.6 (D4), U5.6 (D4), U6.6 (D4)
AD5: U1.5 (AD5), U2.7 (D5), U5.7 (D5), U6.7 (D5)
AD6: U1.4 (AD6), U2.8 (D6), U5.8 (D6), U6.8 (D6)
AD7: U1.3 (AD7), U2.9 (D7), U5.9 (D7), U6.9 (D7)
COL: JP5.1 (A), JP6.2 (B), U6.11 (Cp)
COMVID: Q1.2 (B), R1.1, U1.36 (COMVID)
CSB: J3.2, J3.4, J3.6, J3.8, J3.10, J3.12, J3.14, J3.16, U4.2 (A1)
D0: J2.D0, U1.17 (CD7)
D1: J2.D1, U1.18 (CD6)
D2: J2.D2, U1.19 (CD5)
D3: J2.D3, U1.20 (CD4)
D4: J2.D4, U1.21 (CD3)
D5: J2.D5, U1.22 (CD2)
D6: J2.D6, U1.23 (CD1)
D7: J2.D7, U1.24 (CD0)
GND: C1.2, C2.2, C3.2, C4.2, C5.2, C6.2, C7.2, C8.2, C9.2, C10.2, J2.GND, J4.1 (Ext), JP3.2 (B), R1.2, R2.2, U1.12 (VSS), U2.10 (GND), U3.8 (GND), U4.3 (A2), U4.4 (~E0), U4.5 (~E1), U4.8 (GND), U5.1 (OE), U5.10 (GND), U6.1 (OE), U6.10 (GND), U7.14 (GND), U8.7 (GND), U8.9
IRQB: J1.1, J2.IRQB
NMIB: J1.3, J2.NMIB
unnamed: D1.2 (A), J1.2, JP7.2 (B)
unnamed: J4.2 (In), Q1.3 (E), R2.1
unnamed: JP1.1 (A), JP2.2 (B), U4.6 (E2)
unnamed: JP3.1 (A), JP4.1 (A), U8.3
unnamed: JP4.2 (B), JP5.2 (B), U8.2
unnamed: JP6.1 (A), U8.12
unnamed: C3.1, FB1.2, Q1.1 (C)
unnamed: U8.4, U8.13
PHI2: J2.PHI2, JP1.2 (B)
RA0: U5.18 (Q1), U7.10 (A0)
RA1: U5.17 (Q2), U7.9 (A1)
RA2: U5.16 (Q3), U7.8 (A2)
RA3: U5.15 (Q4), U7.7 (A3)
RA4: U5.14 (Q5), U7.6 (A4)
RA5: U5.13 (Q6), U7.5 (A5)
RA6: U5.12 (Q7), U7.4 (A6)
RA7: U6.18 (Q1), U7.3 (A7)
RA8: U6.17 (Q2), U7.25 (A8)
RA9: U6.16 (Q3), U7.24 (A9)
RA10: U6.15 (Q4), U7.21 (A10)
RA11: U6.14 (Q5), U7.23 (A11)
RA12: U6.13 (Q6), U7.2 (A12)
RA13: U6.12 (Q7), U7.1 (A14), U7.26 (A13)
RB: U1.15 (~CSR), U4.14 (~Y1)
RD0: U1.32 (RD0), U2.19 (Q0), U7.11 (DQ0)
RD1: U1.31 (RD1), U2.18 (Q1), U7.12 (DQ1)
RD2: U1.30 (RD2), U2.17 (Q2), U7.13 (DQ2)
RD3: U1.29 (RD3), U2.16 (Q3), U7.15 (DQ3)
RD4: U1.28 (RD4), U2.15 (Q4), U7.16 (DQ4)
RD5: U1.27 (RD5), U2.14 (Q5), U7.17 (DQ5)
RD6: U1.26 (RD6), U2.13 (Q6), U7.18 (DQ6)
RD7: U1.25 (RD7), U2.12 (Q7), U7.19 (DQ7)
RESB: J2.RESB, U1.34 (~RESET/SYNC)
ROW: U5.11 (Cp), U8.10
RWB: J2.RWB, U4.1 (A0)
R/~W: U1.11 (R/~W), U2.1 (OE), U7.27 (~WE), U8.5
VCC: C4.1, C5.1, C6.1, C7.1, C8.1, C9.1, C10.1, FB1.1, J2.VCC, JP2.1 (A), U1.33 (VCC), U2.20 (VCC), U3.16 (VCC), U4.16 (VCC), U5.20 (VCC), U6.20 (VCC), U7.28 (VCC), U8.14 (VCC)
WB: U1.14 (~CSW), U4.15 (~Y0)
WR: U2.11 (Cp), U7.22 (~OE), U8.6
XTAL1: C1.1, U1.39 (XTAL1), Y1.2
XTAL2: C2.1, U1.40 (XTAL2), Y1.1
~CAS: U1.2 (~CAS), U7.20 (~CE), U8.1
~INT: D1.1 (K), JP7.1 (A), U1.16 (~INT)
~RAS: U1.1 (~RAS), U8.11

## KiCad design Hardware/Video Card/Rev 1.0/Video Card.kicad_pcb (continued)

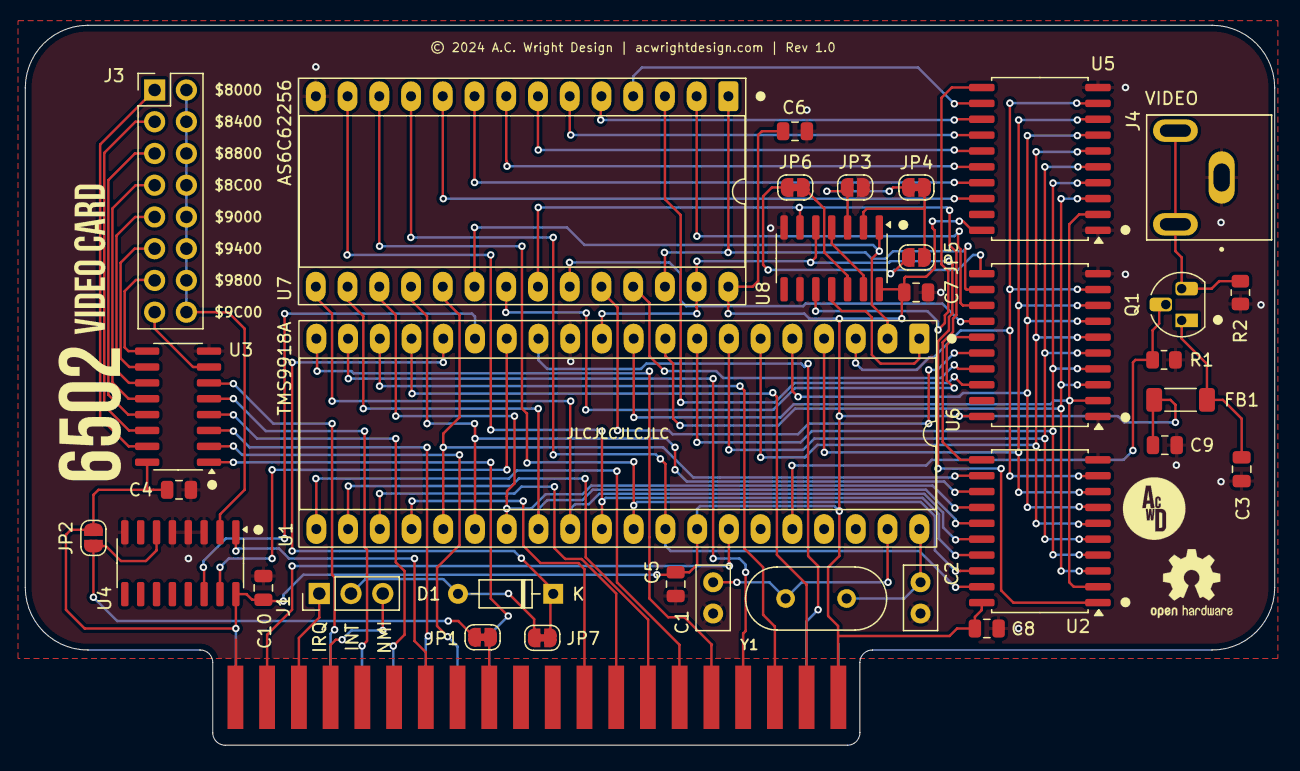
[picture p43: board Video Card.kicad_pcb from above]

Board: 2 copper layers, 100.0 x 57.6 mm, 35 parts (0 on the bottom side), 81 nets.

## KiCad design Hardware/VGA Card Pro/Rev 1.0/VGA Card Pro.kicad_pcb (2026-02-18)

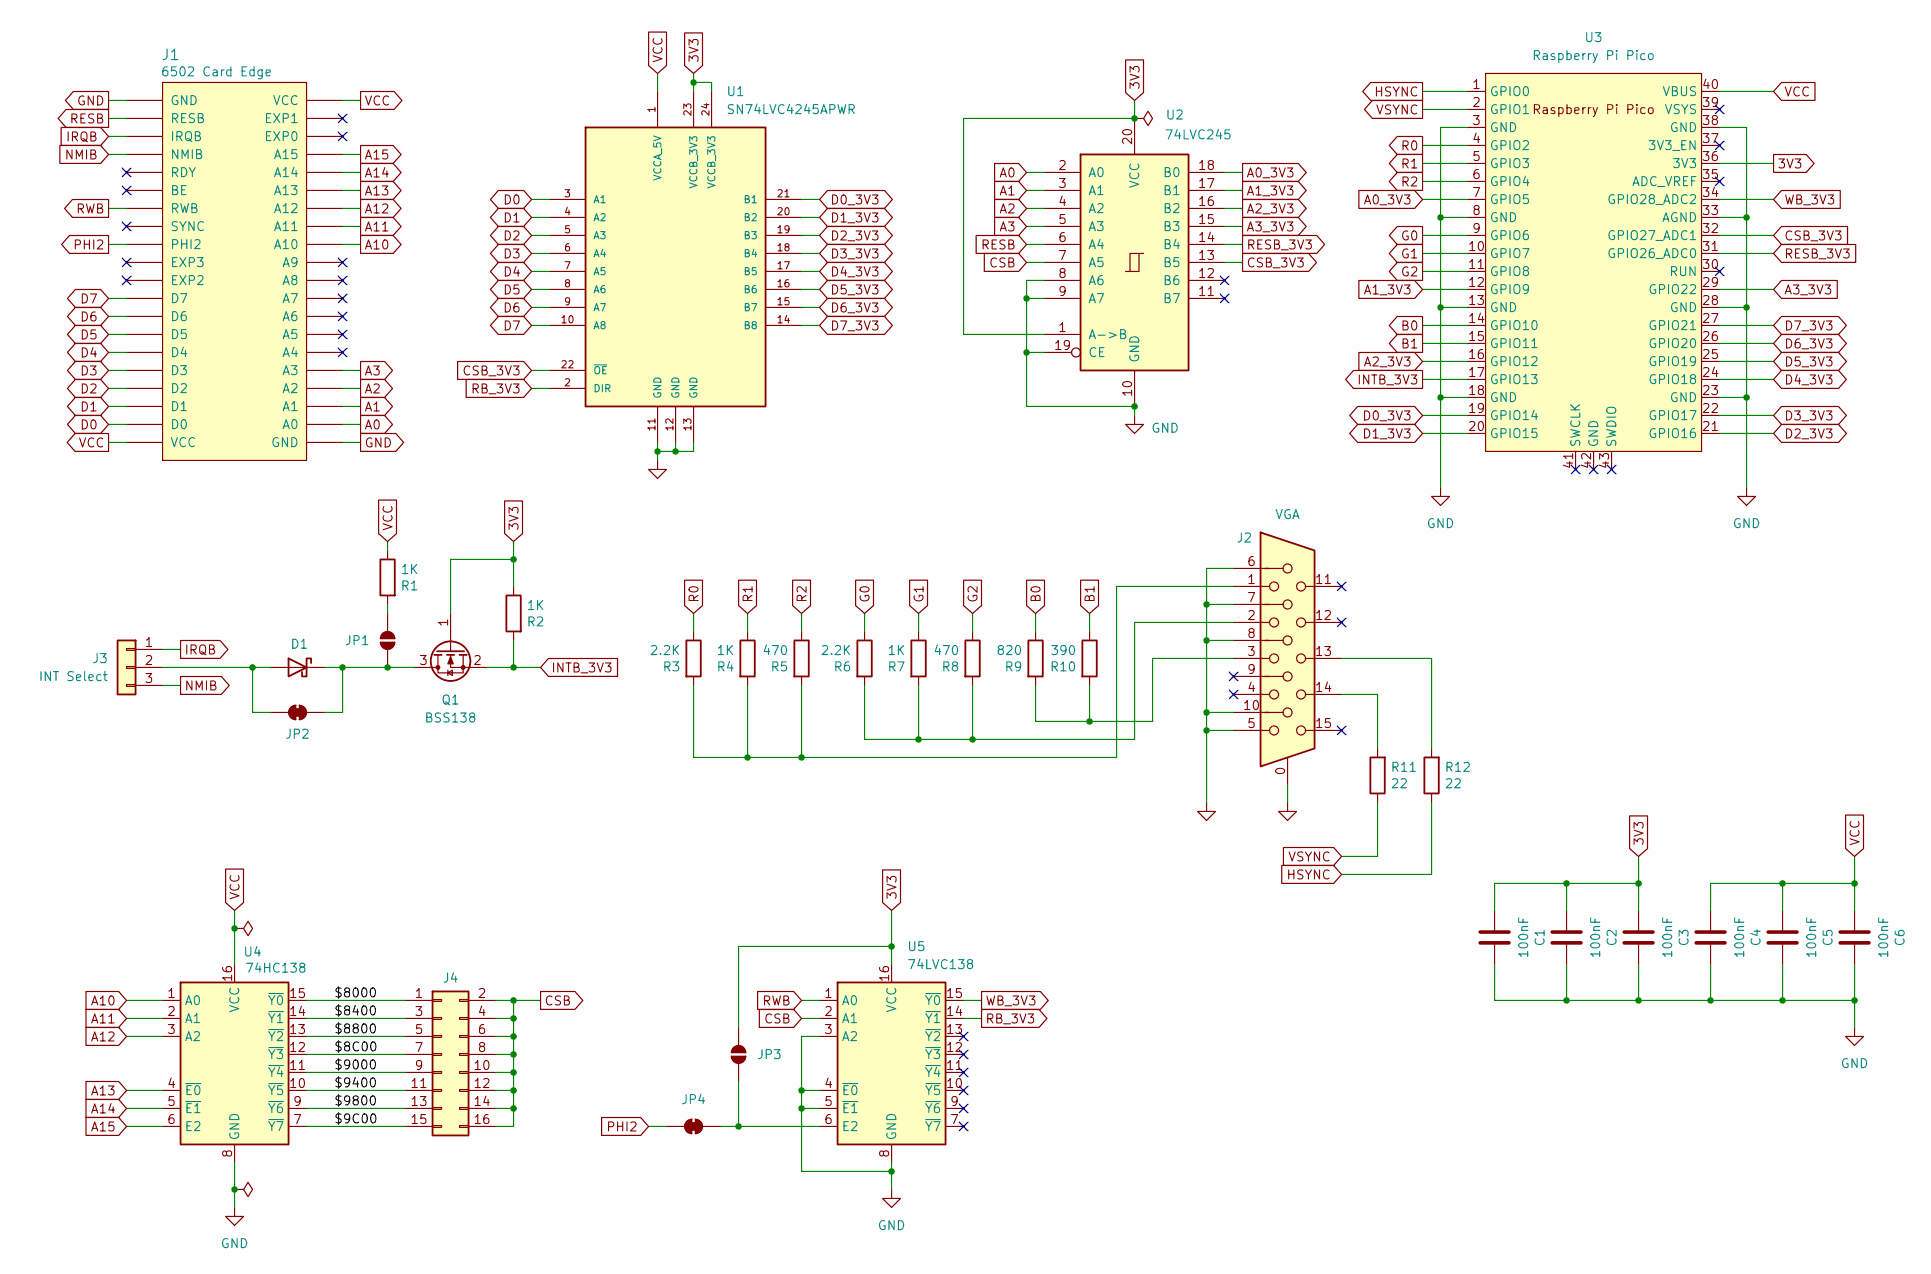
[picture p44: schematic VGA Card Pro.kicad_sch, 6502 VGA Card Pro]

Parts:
C1, C2, C3, C4, C5, C6: 100nF; C_0805_2012Metric; LCSC C49678
D1: D_Schottky; D_DO-35_SOD27_P7.62mm_Horizontal
J1: 6502 Card Edge
J2: VGA; DSUB-15-HD_Socket_Horizontal_P2.29x1.90mm_EdgePinOffset3.03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
J3: INT Select; PinHeader_1x03_P2.54mm_Vertical
J4: Conn_02x08_Odd_Even; PinHeader_2x08_P2.54mm_Vertical
JP1, JP3: SolderJumper_2_Open; SolderJumper-2_P1.3mm_Open_RoundedPad1.0x1.5mm
JP2, JP4: SolderJumper_2_Bridged; SolderJumper-2_P1.3mm_Bridged_RoundedPad1.0x1.5mm
Q1: BSS138; SOT-23; LCSC C78284
R1, R2, R4, R7: 1K; R_0805_2012Metric; LCSC C17513
R3, R6: 2.2K; R_0805_2012Metric; LCSC C17520
R5, R8: 470; R_0805_2012Metric; LCSC C17710
R9: 820; R_0805_2012Metric; LCSC C17837
R10: 390; R_0805_2012Metric; LCSC C17655
R11, R12: 22; R_0805_2012Metric; LCSC C17561
U1: SN74LVC4245APWR; TSSOP-24_4.4x7.8mm_P0.65mm; LCSC C7859
U2: 74LVC245; TSSOP-20_4.4x6.5mm_P0.65mm; LCSC C6082
U3: Raspberry Pi Pico
U4: 74HC138; SOIC-16_3.9x9.9mm_P1.27mm; LCSC C5602
U5: 74LVC138; SOIC-16_3.9x9.9mm_P1.27mm; LCSC C6061

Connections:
3V3: C1.1, C2.1, C3.1, JP3.1 (A), Q1.1 (G), R2.1, U1.23 (VCCB_3V3), U1.24 (VCCB_3V3), U2.1 (A->B), U2.20 (VCC), U3.36 (3V3), U5.16 (VCC)
/$8C00: J4.7, U4.12 (~Y3)
/$9C00: J4.15, U4.7 (~Y7)
/$8000: J4.1, U4.15 (~Y0)
/$8400: J4.3, U4.14 (~Y1)
/$8800: J4.5, U4.13 (~Y2)
/$9000: J4.9, U4.11 (~Y4)
/$9400: J4.11, U4.10 (~Y5)
/$9800: J4.13, U4.9 (~Y6)
A0: J1.A0, U2.2 (A0)
A0_3V3: U2.18 (B0), U3.7 (GPIO5)
A1: J1.A1, U2.3 (A1)
A1_3V3: U2.17 (B1), U3.12 (GPIO9)
A2: J1.A2, U2.4 (A2)
A2_3V3: U2.16 (B2), U3.16 (GPIO12)
A3: J1.A3, U2.5 (A3)
A3_3V3: U2.15 (B3), U3.29 (GPIO22)
A10: J1.A10, U4.1 (A0)
A11: J1.A11, U4.2 (A1)
A12: J1.A12, U4.3 (A2)
A13: J1.A13, U4.4 (~E0)
A14: J1.A14, U4.5 (~E1)
A15: J1.A15, U4.6 (E2)
B0: R9.1, U3.14 (GPIO10)
B1: R10.1, U3.15 (GPIO11)
CSB: J4.2, J4.4, J4.6, J4.8, J4.10, J4.12, J4.14, J4.16, U2.7 (A5), U5.2 (A1)
CSB_3V3: U1.22 (~OE), U2.13 (B5), U3.32 (GPIO27_ADC1)
D0: J1.D0, U1.3 (A1)
D0_3V3: U1.21 (B1), U3.19 (GPIO14)
D1: J1.D1, U1.4 (A2)
D1_3V3: U1.20 (B2), U3.20 (GPIO15)
D2: J1.D2, U1.5 (A3)
D2_3V3: U1.19 (B3), U3.21 (GPIO16)
D3: J1.D3, U1.6 (A4)
D3_3V3: U1.18 (B4), U3.22 (GPIO17)
D4: J1.D4, U1.7 (A5)
D4_3V3: U1.17 (B5), U3.24 (GPIO18)
D5: J1.D5, U1.8 (A6)
D5_3V3: U1.16 (B6), U3.25 (GPIO19)
D6: J1.D6, U1.9 (A7)
D6_3V3: U1.15 (B7), U3.26 (GPIO20)
D7: J1.D7, U1.10 (A8)
D7_3V3: U1.14 (B8), U3.27 (GPIO21)
G0: R6.1, U3.9 (GPIO6)
G1: R7.1, U3.10 (GPIO7)
G2: R8.1, U3.11 (GPIO8)
GND: C1.2, C2.2, C3.2, C4.2, C5.2, C6.2, J1.GND, J2.0, J2.5, J2.6, J2.7, J2.8, J2.10, U1.11 (GND), U1.12 (GND), U1.13 (GND), U2.8 (A6), U2.9 (A7), U2.10 (GND), U2.19 (CE), U3.3 (GND), U3.8 (GND), U3.13 (GND), U3.18 (GND), U3.23 (GND), U3.28 (GND), U3.33 (AGND), U3.38 (GND), U4.8 (GND), U5.3 (A2), U5.4 (~E0), U5.5 (~E1), U5.8 (GND)
HSYNC: R12.1, U3.1 (GPIO0)
INTB_3V3: Q1.2 (S), R2.2, U3.17 (GPIO13)
IRQB: J1.IRQB, J3.1
NMIB: J1.NMIB, J3.3
unnamed: D1.2 (A), J3.2, JP2.2 (B)
unnamed: D1.1 (K), JP1.2 (B), JP2.1 (A), Q1.3 (D)
unnamed: J2.1, R3.2, R4.2, R5.2
unnamed: J2.2, R6.2, R7.2, R8.2
unnamed: J2.3, R9.2, R10.2
unnamed: J2.13, R12.2
unnamed: J2.14, R11.2
unnamed: JP1.1 (A), R1.2
unnamed: JP3.2 (B), JP4.1 (A), U5.6 (E2)
PHI2: J1.PHI2, JP4.2 (B)
R0: R3.1, U3.4 (GPIO2)
R1: R4.1, U3.5 (GPIO3)
R2: R5.1, U3.6 (GPIO4)
RB_3V3: U1.2 (DIR), U5.14 (~Y1)
RESB: J1.RESB, U2.6 (A4)
RESB_3V3: U2.14 (B4), U3.31 (GPIO26_ADC0)
RWB: J1.RWB, U5.1 (A0)
VCC: C4.1, C5.1, C6.1, J1.VCC, R1.1, U1.1 (VCCA_5V), U3.40 (VBUS), U4.16 (VCC)
VSYNC: R11.1, U3.2 (GPIO1)
WB_3V3: U3.34 (GPIO28_ADC2), U5.15 (~Y0)

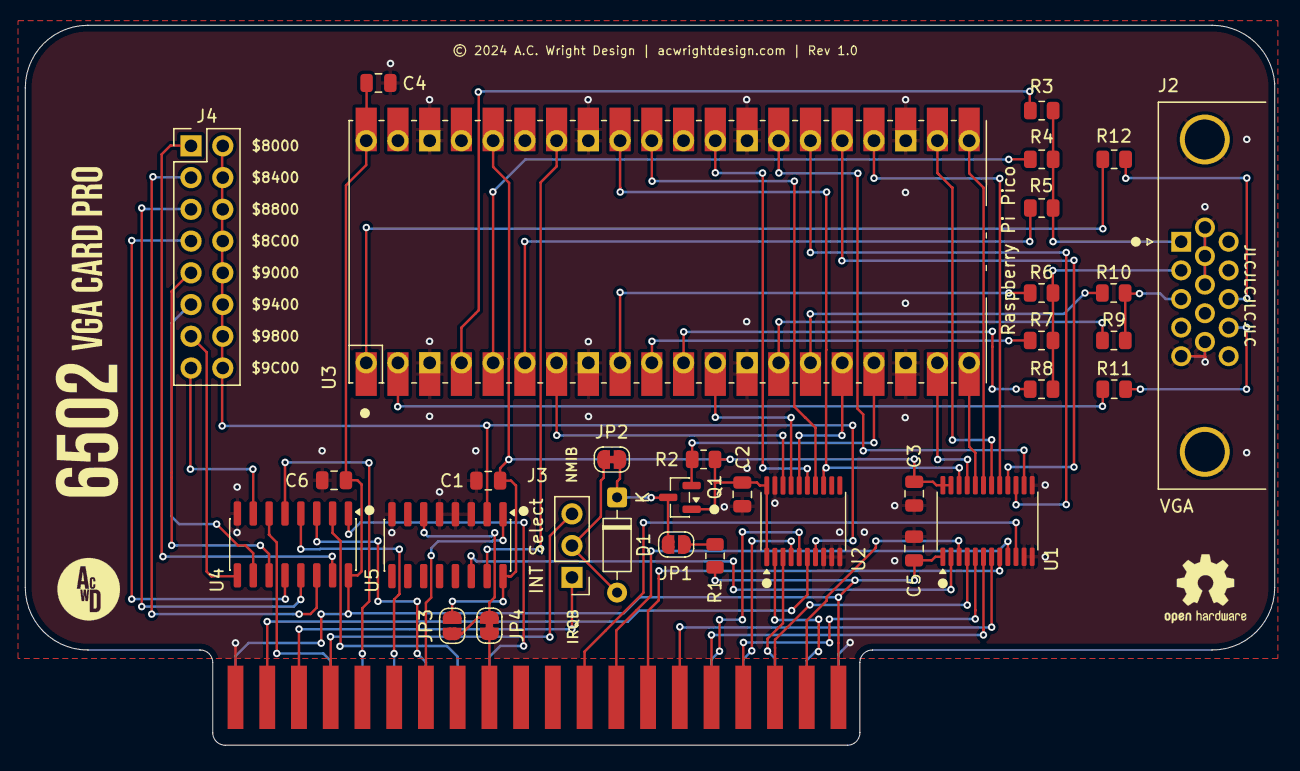
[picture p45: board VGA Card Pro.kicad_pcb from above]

Board: 2 copper layers, 100.0 x 57.6 mm, 33 parts (0 on the bottom side), 71 nets.

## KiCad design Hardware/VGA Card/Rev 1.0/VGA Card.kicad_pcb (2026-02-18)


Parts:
C1, C2: 100nF; C_0805_2012Metric; LCSC C49678
D1: D_Schottky; D_DO-35_SOD27_P7.62mm_Horizontal
J1: 6502 Card Edge
J2: INT Select; PinHeader_1x03_P2.54mm_Vertical
J3: Conn_02x08_Odd_Even; PinHeader_2x08_P2.54mm_Vertical
JP1, JP3: SolderJumper_2_Bridged; SolderJumper-2_P1.3mm_Bridged_RoundedPad1.0x1.5mm
JP2: SolderJumper_2_Open; SolderJumper-2_P1.3mm_Open_RoundedPad1.0x1.5mm
U1: Pico9918A; DIP-40_W15.24mm_LongPads
U2, U3: 74HC138; SOIC-16_3.9x9.9mm_P1.27mm; LCSC C5602

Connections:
/$8C00: J3.7, U2.12 (~Y3)
/$9C00: J3.15, U2.7 (~Y7)
/$8000: J3.1, U2.15 (~Y0)
/$8400: J3.3, U2.14 (~Y1)
/$8800: J3.5, U2.13 (~Y2)
/$9000: J3.9, U2.11 (~Y4)
/$9400: J3.11, U2.10 (~Y5)
/$9800: J3.13, U2.9 (~Y6)
A0: J1.A0, U1.13 (MODE)
A10: J1.A10, U2.1 (A0)
A11: J1.A11, U2.2 (A1)
A12: J1.A12, U2.3 (A2)
A13: J1.A13, U2.4 (~E0)
A14: J1.A14, U2.5 (~E1)
A15: J1.A15, U2.6 (E2)
CSB: J3.2, J3.4, J3.6, J3.8, J3.10, J3.12, J3.14, J3.16, U3.2 (A1)
D0: J1.D0, U1.17 (CD7)
D1: J1.D1, U1.18 (CD6)
D2: J1.D2, U1.19 (CD5)
D3: J1.D3, U1.20 (CD4)
D4: J1.D4, U1.21 (CD3)
D5: J1.D5, U1.22 (CD2)
D6: J1.D6, U1.23 (CD1)
D7: J1.D7, U1.24 (CD0)
GND: C1.2, C2.2, J1.GND, U1.12 (VSS), U2.8 (GND), U3.3 (A2), U3.4 (~E0), U3.5 (~E1), U3.8 (GND)
IRQB: J1.IRQB, J2.1
NMIB: J1.NMIB, J2.3
unnamed: D1.2 (A), J2.2, JP1.2 (B)
unnamed: JP2.2 (B), JP3.1 (A), U3.6 (E2)
PHI2: J1.PHI2, JP3.2 (B)
RB: U1.15 (~CSR), U3.14 (~Y1)
RESB: J1.RESB, U1.34 (~RESET/SYNC)
RWB: J1.RWB, U3.1 (A0)
VCC: C1.1, C2.1, J1.VCC, JP2.1 (A), U1.33 (VCC), U2.16 (VCC), U3.16 (VCC)
WB: U1.14 (~CSW), U3.15 (~Y0)
~INT: D1.1 (K), JP1.1 (A), U1.16 (~INT)


Board: 2 copper layers, 100.0 x 57.6 mm, 12 parts (0 on the bottom side), 36 nets.

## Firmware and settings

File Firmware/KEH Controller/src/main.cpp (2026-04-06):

#define CIRCULAR_BUFFER_INT_SAFE

#include <Arduino.h>
#include <CircularBuffer.hpp>

// ============================================================================
// Keyboard Matrix Mapping 
// ============================================================================
// Rows: PA0-PA7 (VIA Port A)
// Columns: PB0-PB7 (VIA Port B)
//
//      PB0    PB1    PB2    PB3    PB4    PB5    PB6    PB7
// PA0:  `      1      2      3      4      5      6      7
// PA1:  8      9      0      -      =      BS     ESC    TAB
// PA2:  q      w      e      r      t      y      u      i
// PA3:  o      p      [      ]      \      INS    CAPS   a
// PA4:  s      d      f      g      h      j      k      l
// PA5:  ;      '      ENTER  DEL    SHIFT  z      x      c
// PA6:  v      b      n      m      ,      .      /      UP
// PA7:  CTRL   GUI    ALT    SPACE  FN     LEFT   DOWN   RIGHT
//
// Notes:
// - BS = Backspace (0x08), ESC = Escape (0x1B), TAB (0x09)
// - INS = Insert (0x1A), DEL = Delete (0x7F), ENTER (0x0D)
// - Arrow keys: UP (0x1E), LEFT (0x1C), DOWN (0x1F), RIGHT (0x1D)
// - Function keys F1-F10 are mapped as FN + number keys 1-0
// ============================================================================

// ATMega1284 PORT A / 6522 VIA PORT A
#define VIA_PA0 24
#define VIA_PA1 25
#define VIA_PA2 26
#define VIA_PA3 27
#define VIA_PA4 28
#define VIA_PA5 29
#define VIA_PA6 30
#define VIA_PA7 31

// ATMega1284 PORT B / 6522 VIA PORT B
#define VIA_PB0 0
#define VIA_PB1 1
#define VIA_PB2 2
#define VIA_PB3 3
#define VIA_PB4 4
#define VIA_PB5 5
#define VIA_PB6 6
#define VIA_PB7 7

#define VIA_CA1 8
#define VIA_CA2 9
#define PS2CLK  10
#define PS2DATA 11
#define VIA_CB1 12
#define VIA_CB2 13

#define BUFFER_SIZE 16

CircularBuffer<uint8_t, BUFFER_SIZE> ps2Buffer;  // Buffer for PS/2 keyboard data
CircularBuffer<uint8_t, BUFFER_SIZE> matrixBuffer;  // Buffer for matrix keyboard data

// PS/2 keyboard state
bool ps2Enabled = false;
bool shiftPressed = false;
bool ctrlPressed = false;
bool breakCodeNext = false;
bool extendedCodeNext = false;

// Matrix keyboard state
bool matrixEnabled = false;
bool matrixShiftPressed = false;
bool matrixCtrlPressed = false;

// Matrix key debouncing
uint8_t matrixKeyState[8][8] = {0};  // Current state of each key
uint8_t matrixKeyLast[8][8] = {0};   // Last state of each key
unsigned long matrixLastScan = 0;
#define MATRIX_SCAN_INTERVAL 10  // Scan every 10ms
#define MATRIX_DEBOUNCE_COUNT 2  // Key must be stable for 2 scans

void onInterrupt();
void enablePS2();
void disablePS2();
void enableMatrix();
void disableMatrix();
void ps2ToAscii(uint8_t scancode);
void scanMatrix();
uint8_t mapMatrixToAscii(uint8_t row, uint8_t col);

// ============================================================================
// Keyboard Matrix to ASCII Mapping Table
// ============================================================================
// Maps each matrix position [row][col] to its base ASCII code (no modifiers)
// Special values: 0xFF = no key, 0xFE = modifier key (handled separately)
const uint8_t matrixMap[8][8] PROGMEM = {
  // PA0/Row 0: PB0    PB1    PB2    PB3    PB4    PB5    PB6    PB7
  {             0x60,  0x31,  0x32,  0x33,  0x34,  0x35,  0x36,  0x37 },  // ` 1 2 3 4 5 6 7
  // PA1/Row 1
  {             0x38,  0x39,  0x30,  0x2D,  0x3D,  0x08,  0x1B,  0x09 },  // 8 9 0 - = BS ESC TAB
  // PA2/Row 2
  {             0x51,  0x57,  0x45,  0x52,  0x54,  0x59,  0x55,  0x49 },  // Q W E R T Y U I
  // PA3/Row 3
  {             0x4F,  0x50,  0x5B,  0x5D,  0x5C,  0x1A,  0xFF,  0x41 },  // O P [ ] \ INS (ign) A
  // PA4/Row 4
  {             0x53,  0x44,  0x46,  0x47,  0x48,  0x4A,  0x4B,  0x4C },  // S D F G H J K L
  // PA5/Row 5
  {             0x3B,  0x27,  0x0D,  0x7F,  0xFE,  0x5A,  0x58,  0x43 },  // ; ' ENTER DEL SHIFT Z X C
  // PA6/Row 6
  {             0x56,  0x42,  0x4E,  0x4D,  0x2C,  0x2E,  0x2F,  0x1E },  // V B N M , . / UP
  // PA7/Row 7
  {             0xFE,  0xFF,  0xFF,  0x20,  0xFF,  0x1C,  0x1F,  0x1D }   // CTRL (ign) (ign) SPACE (ign) LEFT DOWN RIGHT
};

void setup() {
  pinMode(VIA_CA1, OUTPUT);
  pinMode(VIA_CA2, INPUT_PULLUP);
  pinMode(VIA_CB1, OUTPUT);
  pinMode(VIA_CB2, INPUT_PULLUP);
  pinMode(PS2CLK, INPUT_PULLUP);
  pinMode(PS2DATA, INPUT_PULLUP);

  digitalWrite(VIA_CA1, HIGH);
  digitalWrite(VIA_CB1, HIGH);
  
  attachInterrupt(digitalPinToInterrupt(PS2CLK), onInterrupt, FALLING);
}

void loop() {
  // Check PS/2 enable/disable (CA2)
  int ps2EnableState = digitalRead(VIA_CA2);
  if (ps2EnableState == LOW && !ps2Enabled) {
    enablePS2();
  } else if (ps2EnableState == HIGH && ps2Enabled) {
    disablePS2();
  }
  
  // Check matrix enable/disable (CB2)
  int matrixEnableState = digitalRead(VIA_CB2);
  if (matrixEnableState == LOW && !matrixEnabled) {
    enableMatrix();
  } else if (matrixEnableState == HIGH && matrixEnabled) {
    disableMatrix();
  }
  
  // Scan matrix keyboard if enabled
  if (matrixEnabled) {
    scanMatrix();
  }
  
  // Handle PS/2 keyboard output on Port A
  if (ps2Enabled && !ps2Buffer.isEmpty()) {
    uint8_t ascii = ps2Buffer.shift();
    
    // Ensure Port A is in output mode (matrix scanning leaves it as INPUT)
    pinMode(VIA_PA0, OUTPUT);
    pinMode(VIA_PA1, OUTPUT);
    pinMode(VIA_PA2, OUTPUT);
    pinMode(VIA_PA3, OUTPUT);
    pinMode(VIA_PA4, OUTPUT);
    pinMode(VIA_PA5, OUTPUT);
    pinMode(VIA_PA6, OUTPUT);
    pinMode(VIA_PA7, OUTPUT);

    // Write ASCII value to PORT A
    digitalWrite(VIA_PA0, (ascii >> 0) & 1);
    digitalWrite(VIA_PA1, (ascii >> 1) & 1);
    digitalWrite(VIA_PA2, (ascii >> 2) & 1);
    digitalWrite(VIA_PA3, (ascii >> 3) & 1);
    digitalWrite(VIA_PA4, (ascii >> 4) & 1);
    digitalWrite(VIA_PA5, (ascii >> 5) & 1);
    digitalWrite(VIA_PA6, (ascii >> 6) & 1);
    digitalWrite(VIA_PA7, (ascii >> 7) & 1);
    
    digitalWrite(VIA_CA1, LOW); // Signal that data is ready
    delayMicroseconds(5);
    digitalWrite(VIA_CA1, HIGH);
    delayMicroseconds(100); // Wait before next character
  }
  
  // Handle matrix keyboard output on Port B
  if (matrixEnabled && !matrixBuffer.isEmpty()) {
    // When two keys on the same row are held simultaneously, their switches
    // bridge Port B columns through the shared row wire.  This corrupts the
    // output byte because the ATmega's output drivers fight each other through
    // that path.  Defer output until no row has multiple pressed keys.
    bool hasRowConflict = false;
    for (uint8_t row = 0; row < 8; row++) {
      uint8_t count = 0;
      for (uint8_t col = 0; col < 8; col++) {
        if (matrixKeyState[row][col] >= MATRIX_DEBOUNCE_COUNT) {
          if (++count >= 2) {
            hasRowConflict = true;
            break;
          }
        }
      }
      if (hasRowConflict) break;
    }

    if (!hasRowConflict) {
      // Set Port A (row lines) to high-impedance to prevent bus contention
      // through a single pressed key switch when driving data on Port B
      pinMode(VIA_PA0, INPUT);
      pinMode(VIA_PA1, INPUT);
      pinMode(VIA_PA2, INPUT);
      pinMode(VIA_PA3, INPUT);
      pinMode(VIA_PA4, INPUT);
      pinMode(VIA_PA5, INPUT);
      pinMode(VIA_PA6, INPUT);
      pinMode(VIA_PA7, INPUT);

      uint8_t ascii = matrixBuffer.shift();
    
      // Write ASCII value to PORT B
      digitalWrite(VIA_PB0, (ascii >> 0) & 1);
      digitalWrite(VIA_PB1, (ascii >> 1) & 1);
      digitalWrite(VIA_PB2, (ascii >> 2) & 1);
      digitalWrite(VIA_PB3, (ascii >> 3) & 1);
      digitalWrite(VIA_PB4, (ascii >> 4) & 1);
      digitalWrite(VIA_PB5, (ascii >> 5) & 1);
      digitalWrite(VIA_PB6, (ascii >> 6) & 1);
      digitalWrite(VIA_PB7, (ascii >> 7) & 1);
    
      digitalWrite(VIA_CB1, LOW); // Signal that data is ready
      delayMicroseconds(5);
      digitalWrite(VIA_CB1, HIGH);
      delayMicroseconds(100); // Wait before next character
    }
  }
}

void enablePS2() {
  ps2Enabled = true;
  
  // Set Port A as output for PS/2 data
  pinMode(VIA_PA0, OUTPUT);
  pinMode(VIA_PA1, OUTPUT);
  pinMode(VIA_PA2, OUTPUT);
  pinMode(VIA_PA3, OUTPUT);
  pinMode(VIA_PA4, OUTPUT);
  pinMode(VIA_PA5, OUTPUT);
  pinMode(VIA_PA6, OUTPUT);
  pinMode(VIA_PA7, OUTPUT);
}

void disablePS2() {
  ps2Enabled = false;
  
  // Set Port A as input if matrix is also disabled
  if (!matrixEnabled) {
    pinMode(VIA_PA0, INPUT);
    pinMode(VIA_PA1, INPUT);
    pinMode(VIA_PA2, INPUT);
    pinMode(VIA_PA3, INPUT);
    pinMode(VIA_PA4, INPUT);
    pinMode(VIA_PA5, INPUT);
    pinMode(VIA_PA6, INPUT);
    pinMode(VIA_PA7, INPUT);
  }
}

void enableMatrix() {
  matrixEnabled = true;
  
  // Port A will be used for row scanning (will toggle between input/output)
  // Port B will be used for column reading and data output
  pinMode(VIA_PB0, OUTPUT);
  pinMode(VIA_PB1, OUTPUT);
  pinMode(VIA_PB2, OUTPUT);
  pinMode(VIA_PB3, OUTPUT);
  pinMode(VIA_PB4, OUTPUT);
  pinMode(VIA_PB5, OUTPUT);
  pinMode(VIA_PB6, OUTPUT);
  pinMode(VIA_PB7, OUTPUT);
  
  // Initialize Port A for scanning if PS/2 is disabled
  if (!ps2Enabled) {
    pinMode(VIA_PA0, OUTPUT);
    pinMode(VIA_PA1, OUTPUT);
    pinMode(VIA_PA2, OUTPUT);
    pinMode(VIA_PA3, OUTPUT);
    pinMode(VIA_PA4, OUTPUT);
    pinMode(VIA_PA5, OUTPUT);
    pinMode(VIA_PA6, OUTPUT);
    pinMode(VIA_PA7, OUTPUT);
  }
}

void disableMatrix() {
  matrixEnabled = false;
  
  // Set Port B as input
  pinMode(VIA_PB0, INPUT);
  pinMode(VIA_PB1, INPUT);
  pinMode(VIA_PB2, INPUT);
  pinMode(VIA_PB3, INPUT);
  pinMode(VIA_PB4, INPUT);
  pinMode(VIA_PB5, INPUT);
  pinMode(VIA_PB6, INPUT);
  pinMode(VIA_PB7, INPUT);
  
  // Set Port A as input if PS/2 is also disabled
  if (!ps2Enabled) {
    pinMode(VIA_PA0, INPUT);
    pinMode(VIA_PA1, INPUT);
    pinMode(VIA_PA2, INPUT);
    pinMode(VIA_PA3, INPUT);
    pinMode(VIA_PA4, INPUT);
    pinMode(VIA_PA5, INPUT);
    pinMode(VIA_PA6, INPUT);
    pinMode(VIA_PA7, INPUT);
  }
}

// ============================================================================
// Matrix Keyboard Scanning
// ============================================================================

// Scan the keyboard matrix for key presses
void scanMatrix() {
  unsigned long currentTime = millis();
  
  // Throttle scanning to MATRIX_SCAN_INTERVAL
  if (currentTime - matrixLastScan < MATRIX_SCAN_INTERVAL) {
    return;
  }
  matrixLastScan = currentTime;
  
  uint8_t portAPins[] = {VIA_PA0, VIA_PA1, VIA_PA2, VIA_PA3, VIA_PA4, VIA_PA5, VIA_PA6, VIA_PA7};
  uint8_t portBPins[] = {VIA_PB0, VIA_PB1, VIA_PB2, VIA_PB3, VIA_PB4, VIA_PB5, VIA_PB6, VIA_PB7};
  
  // Phase 1: Scan all rows, update debounce state only
  for (uint8_t row = 0; row < 8; row++) {
    // Drive only the active row LOW; all others high-Z to prevent
    // current leaking through pressed keys on inactive rows (ghosting)
    for (uint8_t i = 0; i < 8; i++) {
      if (i == row) {
        pinMode(portAPins[i], OUTPUT);
        digitalWrite(portAPins[i], LOW);
      } else {
        pinMode(portAPins[i], INPUT);
      }
    }
    
    // Configure Port B pins as inputs with pullups for reading
    for (uint8_t col = 0; col < 8; col++) {
      pinMode(portBPins[col], INPUT_PULLUP);
    }
    
    // Small delay to let signals stabilize
    delayMicroseconds(10);
    
    for (uint8_t col = 0; col < 8; col++) {
      // Read column (LOW = pressed, HIGH = not pressed due to pullup)
      bool pressed = (digitalRead(portBPins[col]) == LOW);
      
      // Debounce logic
      if (pressed) {
        if (matrixKeyState[row][col] < MATRIX_DEBOUNCE_COUNT) {
          matrixKeyState[row][col]++;
        }
      } else {
        if (matrixKeyState[row][col] > 0) {
          matrixKeyState[row][col]--;
        }
      }
    }
    
    // Restore Port B to output mode for data transmission
    for (uint8_t col = 0; col < 8; col++) {
      pinMode(portBPins[col], OUTPUT);
    }
  }
  
  // Release all row lines after scanning
  for (uint8_t i = 0; i < 8; i++) {
    pinMode(portAPins[i], INPUT);
  }
  
  // Phase 2: Update modifier states from current debounce results
  matrixShiftPressed = (matrixKeyState[5][4] >= MATRIX_DEBOUNCE_COUNT);
  matrixCtrlPressed  = (matrixKeyState[7][0] >= MATRIX_DEBOUNCE_COUNT);
  
  // Phase 3: Fire key events with up-to-date modifier state
  for (uint8_t row = 0; row < 8; row++) {
    for (uint8_t col = 0; col < 8; col++) {
      bool keyPressed = (matrixKeyState[row][col] >= MATRIX_DEBOUNCE_COUNT);
      bool keyWasPressed = matrixKeyLast[row][col];
      
      // Detect key press event (transition from not pressed to pressed)
      if (keyPressed && !keyWasPressed) {
        uint8_t ascii = mapMatrixToAscii(row, col);
        if (ascii != 0xFF && ascii != 0xFE) {  // 0xFF = no key, 0xFE = modifier
          matrixBuffer.push(ascii);
        }
      }
      
      matrixKeyLast[row][col] = keyPressed;
    }
  }
}

// Map matrix position to ASCII code based on modifiers
uint8_t mapMatrixToAscii(uint8_t row, uint8_t col) {
  // Get base key code from PROGMEM
  uint8_t baseKey = pgm_read_byte(&matrixMap[row][col]);
  
  // Handle special keys
  if (baseKey == 0xFF) return 0xFF;  // No key / ignored
  if (baseKey == 0xFE) return 0xFE;  // Modifier key
  
  // Ctrl takes priority (Shift ignored when Ctrl held)
  if (matrixCtrlPressed) {
    if (baseKey == 0x32) return 0x00;  // Ctrl+2 = NUL
    if (baseKey >= 0x41 && baseKey <= 0x5A) {  // Ctrl+A-Z
      return baseKey - 0x40;  // Convert to 0x01-0x1A
    }
    if (baseKey == 0x5B) return 0x1B;  // Ctrl+[ = ESC
    if (baseKey == 0x5C) return 0x1C;  // Ctrl+\ = FS
    if (baseKey == 0x5D) return 0x1D;  // Ctrl+] = GS
    if (baseKey == 0x36) return 0x1E;  // Ctrl+6 = RS
    if (baseKey == 0x2D) return 0x1F;  // Ctrl+- = US
    return 0xFF;  // Ctrl + unmapped key = no output
  }
  
  // Shift only affects numbers and symbols (not letters)
  if (matrixShiftPressed) {
    if (baseKey == 0x31) return 0x21;  // 1 -> !
    if (baseKey == 0x32) return 0x40;  // 2 -> @
    if (baseKey == 0x33) return 0x23;  // 3 -> #
    if (baseKey == 0x34) return 0x24;  // 4 -> $
    if (baseKey == 0x35) return 0x25;  // 5 -> %
    if (baseKey == 0x36) return 0x5E;  // 6 -> ^
    if (baseKey == 0x37) return 0x26;  // 7 -> &
    if (baseKey == 0x38) return 0x2A;  // 8 -> *
    if (baseKey == 0x39) return 0x28;  // 9 -> (
    if (baseKey == 0x30) return 0x29;  // 0 -> )
    if (baseKey == 0x2D) return 0x5F;  // - -> _
    if (baseKey == 0x3D) return 0x2B;  // = -> +
    if (baseKey == 0x5B) return 0x7B;  // [ -> {
    if (baseKey == 0x5D) return 0x7D;  // ] -> }
    if (baseKey == 0x5C) return 0x7C;  // \ -> |
    if (baseKey == 0x3B) return 0x3A;  // ; -> :
    if (baseKey == 0x27) return 0x22;  // ' -> "
    if (baseKey == 0x60) return 0x7E;  // ` -> ~
    if (baseKey == 0x2C) return 0x3C;  // , -> <
    if (baseKey == 0x2E) return 0x3E;  // . -> >
    if (baseKey == 0x2F) return 0x3F;  // / -> ?
  }
  
  // Return base key (letters are already uppercase in the map)
  return baseKey;
}

void onInterrupt() {
  static uint8_t bitcount = 0;
  static uint8_t incoming;
  static uint8_t parity;
  static uint32_t prev_ms = 0;
  uint32_t now_ms;
  uint8_t val;

  val = digitalRead(PS2DATA);
  now_ms = millis();

  if (now_ms - prev_ms > 250) { 
    bitcount = 0;
  }

  prev_ms = now_ms;
  bitcount++;

  switch (bitcount) {
    case 1:  // Start bit
      incoming = 0;
      parity = 0;
      break;
    case 2:
    case 3:
    case 4:
    case 5:
    case 6:
    case 7:
    case 8:
    case 9:                              // Data bits
      parity += val;                     // Count number of 1 bits
      incoming >>= 1;                    // Right shift one place for next bit
      incoming |= (val) ? 0x80 : 0;      // OR in MSbit
      break;
    case 10:                             // Parity check (PS/2 uses odd parity)
      parity &= 1;                       // Get LSB: 1=odd count, 0=even count
      if (parity == val)                 // For odd parity: bit should be opposite of data parity
        parity = 0xFD;                   // Mark invalid to discard byte
      break;
    case 11: // Stop bit
      if (parity < 0xFD) {               // Good so save byte in buffer, otherwise discard
        ps2ToAscii(incoming);            // Convert to ASCII if valid scancode (if full, oldest data lost)
      }
      bitcount = 0;
      break;
    default:
      bitcount = 0;                      // Shouldn't be here so reset state machine
      break;
  }
}
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

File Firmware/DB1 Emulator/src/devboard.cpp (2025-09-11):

#include "devboard.h"

#ifdef DEVBOARD_1_0
void initPins() {
  pinMode(RESB, OUTPUT);
  pinMode(IRQB, INPUT);
  pinMode(NMIB, INPUT);
  pinMode(RDY, INPUT);
  pinMode(BE, INPUT);
  pinMode(SYNC, INPUT);
  pinMode(RWB, INPUT);
  pinMode(PHI2, OUTPUT);

  pinMode(CLK_SWB, INPUT);
  pinMode(STEP_SWB, INPUT);
  pinMode(RS_SWB, INPUT);

  pinMode(GPIO0, INPUT);
  pinMode(GPIO1, INPUT);
  pinMode(GPIO2, INPUT);
  pinMode(GPIO3, INPUT);
  
  digitalWriteFast(RESB, HIGH);
  digitalWriteFast(PHI2, HIGH);

  pinMode(OE1, OUTPUT);
  pinMode(OE2, OUTPUT);
  pinMode(OE3, OUTPUT);

  digitalWriteFast(OE1, LOW);
  digitalWriteFast(OE2, HIGH);
  digitalWriteFast(OE3, HIGH);
}
#endif

#ifdef DEVBOARD_1_1
void initPins() {
  pinMode(RESB, OUTPUT);
  pinMode(IRQB, INPUT);
  pinMode(NMIB, INPUT);
  pinMode(RDY, INPUT);
  pinMode(BE, INPUT);
  pinMode(SYNC, INPUT);
  pinMode(RWB, INPUT);
  pinMode(PHI2, OUTPUT); 
  
  pinMode(RES_SWB, INPUT);
  pinMode(CLK_SWB, INPUT);
  pinMode(STEP_SWB, INPUT);
  pinMode(RS_SWB, INPUT);

  pinMode(GPIO0, INPUT);
  
  digitalWriteFast(RESB, HIGH);
  digitalWriteFast(PHI2, HIGH);

  pinMode(OE1, OUTPUT);
  pinMode(OE2, OUTPUT);
  pinMode(OE3, OUTPUT);

  digitalWriteFast(OE1, LOW);
  digitalWriteFast(OE2, HIGH);
  digitalWriteFast(OE3, HIGH);
}
#endif

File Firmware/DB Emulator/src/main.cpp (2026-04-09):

#include <Arduino.h>
#include <ArduinoJson.h>
#include <TimeLib.h>
#include <Bounce2.h>
#include <SD.h>
#include <EEPROM.h>
#include <USBHost_t36.h>
#include <QNEthernet.h>
#include <AsyncWebServer_Teensy41.h>
#include <6502.h>

using namespace qindesign::network;

Button clkButton      = Button();
Button stepButton     = Button();
Button runStopButton  = Button();
Button resetButton    = Button();

USBHost             usb;
USBHub              hub1(usb);
USBHIDParser        hid1(usb);
USBHIDParser        hid2(usb);
USBHIDParser        hid3(usb);

KeyboardController  keyboard(usb);
JoystickController  joystick(usb);

EthernetClient      ethClient;
AsyncWebServer      server(80);

void onCommand(char command);
void onNumeric(uint8_t num);
void onKeyDown(uint8_t keycode);
void onKeyUp(uint8_t keycode);
void onJoystick();

void info();
void log();
void reset();
void tick();
void step();
void dump();
void snapshot();
void decreaseFrequency();
void increaseFrequency();
void toggleRunStop();
void unloadCart();
void readROMs();
void listROMs();
void loadROM(uint index);
void loadROMFile(String filename);
void loadROMPath(String path);
void readCarts();
void listCarts();
void loadCart(uint index);
void loadCartFile(String filename);
void loadCartPath(String path);
void readPrograms();
void listPrograms();
void loadProgram(uint index);
void loadProgramFile(String filename);
void loadProgramPath(String path);
void listFiles();
void prevPage();
void nextPage();

uint8_t read(uint16_t addr, bool isDbg);
void write(uint16_t addr, uint8_t val);

void initPins();
void initButtons();
void initSD();
void initUSB();
void initEthernet();
void initServer();
void initFiles();
void initWWWCache();

void buildMemoryMap();

void startCpuTimer();
void stopCpuTimer();
void cpuTimerISR();

time_t syncTime();
String formattedDateTime();
time_t lastSnapshot;

void onServerRoot(AsyncWebServerRequest *request);
void onServerInfo(AsyncWebServerRequest *request);
void onServerMemory(AsyncWebServerRequest *request);
void onServerStorage(AsyncWebServerRequest *request);
void onServerLoad(AsyncWebServerRequest *request);
void onServerControl(AsyncWebServerRequest *request);
void onServerKeyboard(AsyncWebServerRequest *request);
void onServerNotFound(AsyncWebServerRequest *request);

volatile uint8_t freqIndex = FREQ_SIZE - 1;
bool isRunning = false;
bool isStepping = false;
bool autoStart = false;
volatile bool cartLoaded = false;

uint8_t inputCtx = INPUT_CTX_ROM;

uint16_t address = 0;
uint8_t data = 0;
bool readWrite = HIGH;

String ROMs[FILE_MAX];
uint romFilePage = 0;
String Carts[FILE_MAX];
uint cartFilePage = 0;
String Programs[FILE_MAX];
uint programFilePage = 0;

uint memoryPage = 0;

#ifdef MEM_EXTMEM
EXTMEM __attribute__((aligned(32))) uint8_t ramData1[RC_BLOCK_SIZE * RC_BLOCK_COUNT];
EXTMEM __attribute__((aligned(32))) uint8_t ramData2[RC_BLOCK_SIZE * RC_BLOCK_COUNT];
#else
__attribute__((aligned(32))) uint8_t ramData1[RC_BLOCK_SIZE * RC_BLOCK_COUNT];
__attribute__((aligned(32))) uint8_t ramData2[RC_BLOCK_SIZE * RC_BLOCK_COUNT];
#endif

static uint32_t cachedCpuFrequency = 1000000;
static uint8_t cachedCpuFreqIndex = 0xFF;

IntervalTimer cpuTimer;
volatile bool timerMode = false;
volatile uint8_t busPhase = 0;

// Use IntervalTimer for slow frequencies where blocking delays would freeze loop().
// At period >= TIMER_FREQ_THRESHOLD (µs), the ISR completes well within each half-cycle.
// Above that frequency, tight-loop with inline delays is used (loop() stays responsive).
#define TIMER_FREQ_THRESHOLD 32

enum MemoryRegion : uint8_t {
  REGION_CART_CODE,
  REGION_ROM,
  REGION_RAM,
  REGION_IO,
  REGION_NONE
};
static MemoryRegion memoryMap[256]; // 256 possible high bytes

CPU cpu = CPU(read, write);
RAM ram = RAM();
ROM rom = ROM();
Cart cart = Cart();

RAMCard ramCard1 = RAMCard(ramData1);
RAMCard ramCard2 = RAMCard(ramData2);
RTCCard rtcCard = RTCCard();
StorageCard storageCard = StorageCard();
SerialCard serialCard = SerialCard();
GPIOCard gpioCard = GPIOCard();
SoundCard soundCard = SoundCard();
VideoCard videoCard = VideoCard();

// GPIO Attachments
GPIOKeyboardMatrixAttachment keyboardMatrixAttachment = GPIOKeyboardMatrixAttachment(10);     // Priority 10
GPIOKeyboardEncoderAttachment keyboardEncoderAttachment = GPIOKeyboardEncoderAttachment(20);  // Priority 20 (supports both Port A and B)
GPIOJoystickAttachment joystickAttachmentA = GPIOJoystickAttachment(true, 100);              // Port A, Priority 100
GPIOJoystickAttachment joystickAttachmentB = GPIOJoystickAttachment(false, 100);              // Port B, Priority 100

//
// MAIN
//

void setup() {
  Serial.begin(115200);       // Ignored by Teensy; Baud rate is USB data rate 480Mbps
  SerialUSB1.begin(115200);   // Ignored by Teensy; Baud rate is USB data rate 480Mbps
  SerialUSB2.begin(115200);   // Ignored by Teensy; Baud rate is USB data rate 480Mbps
  HWSERIAL.begin(6000000);    // 6 Mbit/sec — maximum on Teensy 4.1 without clock reconfiguration
  static uint8_t hwSerialWriteBuffer[8192];
  HWSERIAL.addMemoryForWrite(hwSerialWriteBuffer, sizeof(hwSerialWriteBuffer));

  setSyncProvider(syncTime);
  buildMemoryMap();
  
  // Attach peripherals to GPIO Card
  // Keyboard matrix (manual scanning) - highest priority for Port A rows
  gpioCard.attachToPortA(&keyboardMatrixAttachment);
  gpioCard.attachToPortB(&keyboardMatrixAttachment);
  
  // Keyboard encoder (ASCII on both Port A and Port B) - medium priority
  gpioCard.attachToPortA(&keyboardEncoderAttachment);
  gpioCard.attachToPortB(&keyboardEncoderAttachment);
  
  // Joystick (Port A and Port B) - lowest priority, fallback
  gpioCard.attachToPortA(&joystickAttachmentA);
  gpioCard.attachToPortB(&joystickAttachmentB);
  
  initPins();
  initButtons();
  initSD();
  initWWWCache();
  initUSB();
  initEthernet();
  initServer();
  initFiles();

  readROMs();
  readCarts();
  readPrograms();

  info();

  if (autoStart) {
    delay(500);
    reset();
    toggleRunStop();
  }
}

void loop() {
  usb.Task();

  clkButton.update();
  stepButton.update();
  runStopButton.update();
  resetButton.update();

  if (clkButton.pressed()) {
    decreaseFrequency();
  }
  if (stepButton.pressed()) {
    step();
  }
  if (runStopButton.pressed()) {
    toggleRunStop();
  }
  if (resetButton.pressed()) {
    reset();
  }

  if (joystick.available()) {
    onJoystick();
  }
  if (Serial.available()) {
    onCommand(Serial.read());
  }

  if (isRunning && !timerMode) {
    // Batch multiple ticks per loop() iteration to amortize USB/button overhead.
    // At 1MHz each tick is ~0.3-0.5µs on Cortex-M7; 512 ticks ≈ 150-250µs per batch,
    // leaving loop() responsive at ~4000 iterations/sec for USB and input polling.
    for (uint16_t i = 0; i < 2048; i++) {
      tick();
    }
  }
}

//
// EVENTS
//
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

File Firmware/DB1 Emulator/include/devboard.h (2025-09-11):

#ifndef _DEVBOARD_H
#define _DEVBOARD_H

#include <Arduino.h>

#ifdef DEVBOARD_1_0 
#define RESB      28  // RESET          
#define SYNC      30  // SYNC           
#define RWB       27  // READ/WRITE     
#define RDY       29  // RDY            
#define BE        18  // BE             
#define PHI2      13  // PHI2           
#define NMIB      41  // NMI            
#define IRQB      31  // IRQ            

#define A15       26  // A15            
#define A14       25  // A14            
#define A13       24  // A13            
#define A12       12  // A12            
#define A11       11  // A11            
#define A10       10  // A10            
#define A9        9   // A9             
#define A8        8   // A8             
#define A7        7   // A7             
#define A6        6   // A6             
#define A5        5   // A5             
#define A4        4   // A4             
#define A3        3   // A3             
#define A2        2   // A2             
#define A1        1   // A1             
#define A0        0   // A0             

#define D7        40  // D7             
#define D6        39  // D6             
#define D5        38  // D5             
#define D4        37  // D4             
#define D3        36  // D3             
#define D2        35  // D2             
#define D1        34  // D1             
#define D0        33  // D0             

#define OE1       32  // OUTPUT ENABLE 1
#define OE2       22  // OUTPUT ENABLE 2
#define OE3       23  // OUTPUT ENABLE 3

#define GPIO0     14  // GPIO 0         
#define GPIO1     15  // GPIO 1         
#define GPIO2     16  // GPIO 2         
#define GPIO3     17  // GPIO 3         

#define CLK_SWB   21  // CLOCK SWITCH
#define STEP_SWB  20  // STEP SWITCH    
#define RS_SWB    19  // RUN/STOP SWITCH
#endif

#ifdef DEVBOARD_1_1
#define RESB      32  // RESET          
#define SYNC      30  // SYNC           
#define RWB       27  // READ/WRITE     
#define RDY       23  // RDY            
#define BE        18  // BE             
#define PHI2      13  // PHI2           
#define NMIB      41  // NMI            
#define IRQB      31  // IRQ            

#define A15       26  // A15            
#define A14       25  // A14            
#define A13       24  // A13            
#define A12       12  // A12            
#define A11       11  // A11            
#define A10       10  // A10            
#define A9        9   // A9             
#define A8        8   // A8             
#define A7        7   // A7             
#define A6        6   // A6             
#define A5        5   // A5             
#define A4        4   // A4             
#define A3        3   // A3             
#define A2        2   // A2             
#define A1        1   // A1             
#define A0        0   // A0             

#define D7        40  // D7             
#define D6        39  // D6             
#define D5        38  // D5             
#define D4        37  // D4             
#define D3        36  // D3             
#define D2        35  // D2             
#define D1        34  // D1             
#define D0        33  // D0             

#define OE1       17  // OUTPUT ENABLE 1
#define OE2       16  // OUTPUT ENABLE 2
#define OE3       15  // OUTPUT ENABLE 3

#define GPIO0     14  // GPIO 0               

#define RES_SWB   22  // RESET SWITCH
#define CLK_SWB   21  // CLOCK SWITCH
#define STEP_SWB  20  // STEP SWITCH    
#define RS_SWB    19  // RUN/STOP SWITCH
#endif

void initPins();

#endif

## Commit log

2021-03-29 Working on schematic capture
    [CPU Card.kicad_pcb, CPU Card.sch, Memory Card.kicad_pcb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]
2021-03-31 Working on pcb layout
    [Backplane.kicad_pcb, Backplane.sch]
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2021-04-01 Layout memory card PCB
    [Memory Card.kicad_pcb, Memory Card.sch]
2021-04-02 JLC fix
    [Backplane.kicad_pcb, CPU Card.kicad_pcb, Memory Card.kicad_pcb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]
2021-04-07 Working on serial card
    [Serial Card.kicad_pcb, Serial Card.sch]
2021-04-07 Serial card PCB layout
    [Serial Card.kicad_pcb]
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2021-04-15 Add Rev 0 backplane schematic
    [Backplane-B_Mask.gbr, Backplane-B_Paste.gbr, Backplane-B_SilkS.gbr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]
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2024-03-19 Update to Kicad 8.0
    [Backplane.kicad_pcb, CPU Card.kicad_pcb, CPU Card.kicad_sch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]
2024-03-25 Working on new PCBs
    [BAT-HLD-001-THM.step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]
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2024-04-23 Work on dev board firmware
    [Backplane-B_Mask.gbr, Backplane-B_Paste.gbr, Backplane-B_SilkS.gbr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]
2024-04-23 Add to GPIO header on dev board
    [Dev Board.kicad_pcb, Dev Board.kicad_sch]
2024-04-26 Added some test assembly
    [6502.cfg]
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2024-05-04 Update dev board firmware
    [Blinkenlights Card.kicad_sch]
2024-05-10 Rewrite debugger for multi-platform
    [6502.cfg, Serial Card Pro.kicad_pcb, Serial Card Pro.kicad_sch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]
2024-05-13 Add keyboard control to debugger
    [6502.cfg, Breadboard Helper.kicad_pcb, Breadboard Helper.kicad_sch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]
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2024-05-21 Fix serial card pro wiring
    [Serial Card Pro.kicad_pcb, Serial Card Pro.kicad_sch, Serial Card.kicad_pcb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]
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2024-05-31 Reworking some schematics
    [Blinkenlights Card.kicad_pcb, Blinkenlights Card.kicad_sch, Breadboard Helper.kicad_pcb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]
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2024-06-18 Add Input Board and rework Debugger
    [Input Board.kicad_pcb, Input Board.kicad_sch, Main Board.kicad_pcb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]
2024-06-18 Stabilize Dev Board firmware
    [main.cpp]
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2024-06-26 Wozmon fix for Dev Board
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2024-06-27 GPIO Board software fixes
2024-06-27 Add Sound Card demos
    [6502.cfg]
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2024-07-03 Update to Backplane and CPU cards
    [Backplane.kicad_pcb, Backplane.kicad_sch, CPU Card.kicad_pcb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]
2024-07-03 Add LCD Clear example
    [6502.cfg]
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2024-07-04 Working on Teensy card
    [Teensy Card.kicad_pcb, Teensy Card.kicad_sch]
2024-07-07 Keypad and Teensy boards
    [Backplane.kicad_pcb, DS01C-254-L-08BE.step, Keypad Helper.kicad_pcb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]
2024-07-08 Fix Teensy card
    [Teensy Card.kicad_pcb, Teensy Card.kicad_sch]
2024-07-08 Add Dev Board 1.1
    [Backplane Pro.kicad_pcb, Backplane Pro.kicad_sch, Backplane.kicad_pcb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]
2024-07-09 Fix Video Card
    [Video Card.kicad_pcb, Video Card.kicad_sch]
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2025-09-06 A bit of housekeeping
    [Backplane Pro.kicad_pcb, Backplane Pro.kicad_sch, Backplane.kicad_pcb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]
2025-09-06 Fix IB Data/CLK label direction on schematic
    [Input Board.kicad_sch]
2025-09-06 Fix jumper exclude from simulation
    [GPIO Card.kicad_sch, Input Board.kicad_sch, LCD Card.kicad_sch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]
2025-09-06 Change default IRQ solder pads on LCD/Sound/Video cards
    [LCD Card.kicad_pcb, LCD Card.kicad_sch, Sound Card.kicad_pcb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]
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2025-09-06 Add flow control to Serial Card
    [Serial Card.kicad_pcb, Serial Card.kicad_sch]
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2025-09-07 Update LCD trimpot part number and fix 3D model
    [3386F-1-103LF.step, Keypad LCD Helper.kicad_pcb, Keypad LCD Helper.kicad_sch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]
2025-09-08 Add 3D images for all boards
    [0702461201.step, 61204021621.step, Backplane Pro.kicad_pcb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]
2025-09-08 Remove V1.1 of LCD Sound and Video cards
    [LCD Card.kicad_pcb, LCD Card.kicad_sch, Sound Card.kicad_pcb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]
2025-09-09 Update images for all boards with solder pad jumpers
    [Backplane Pro.kicad_pcb, CPU Card.kicad_pcb, GPIO Card.kicad_pcb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]
2025-09-09 Add RTS CTS pin header to Serial Card 1.1
    [Serial Card.kicad_pcb, Serial Card.kicad_sch]
2025-09-09 Better 3D models and images
    [Backplane Pro.kicad_pcb, Backplane.kicad_pcb, Dev Board.kicad_pcb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]
2025-09-09 Add 3D models for all PCBs
    [Backplane Pro.step, Backplane.step, Blinkenlights Card.step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]
2025-09-10 Fixes for DB Monitor
    [main.cpp, mouse.cpp]
2025-09-11 Improvements to DB Emulator
    [6502.cfg]
2025-09-11 Update DB 1.1 to add OE control lines
    [Dev Board.kicad_pcb, Dev Board.kicad_sch]
2025-09-11 Add target for DB 1.1 to DB Emulator
    [Dev Board.kicad_pcb]
2025-09-13 Add VC test carts
    [6502.cfg]
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2025-09-15 Drop Pi Card and GigaShield
    [Giga Shield.kicad_pcb, Giga Shield.kicad_sch, Pi Card.kicad_pcb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]
2025-09-15 Fix Wozmon
    [6502.cfg]
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2025-09-18 Replace switches on Front Panel board with SS12D10
    [Front Panel.kicad_pcb, Front Panel.kicad_sch, Front Panel.step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]
2025-09-18 Redesign VGA card based on Pico9918A
    [VGA Card.kicad_pcb, VGA Card.kicad_sch, VGA Card.step]
2025-09-19 Fixed GPIO Helper D-Pad center hole location
    [GPIO Helper.kicad_pcb, GPIO Helper.step]
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2025-09-19 Add GPIO Helper 3D printed case
    [Bottom.stl, Button.stl, D-Pad.stl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]
2025-09-21 Add ROM Cart Pro
    [Front Panel.step, GPIO Helper.step, Joystick Helper.step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]
2025-09-22 Edit schematics for clarity
    [Backplane Pro.kicad_sch, Backplane.kicad_sch, GPIO Card.kicad_sch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]
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2025-09-22 Add GPIO Breadboard Helper
    [GPIO Breadboard Helper.kicad_pcb, GPIO Breadboard Helper.kicad_sch, GPIO Breadboard Helper.step]
2025-09-22 Modify ROM Cart Pro schematic
    [ROM Cart Pro.kicad_pcb, ROM Cart Pro.kicad_sch, VGA Card.kicad_pcb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]
2025-09-22 Working on VGA Card Pro
    [ROM Cart Pro.kicad_sch, VGA Card Pro.kicad_pcb, VGA Card Pro.kicad_sch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]
2025-09-23 Better Joystick Helper Labeling
    [Joystick Helper.kicad_pcb, Joystick Helper.kicad_sch]
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2025-09-24 Update ROM Cart Pro schematic
    [ROM Cart Pro.kicad_pcb, ROM Cart Pro.kicad_sch]
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2025-09-25 Small change to GPIO Helper
    [GPIO Helper.kicad_pcb]
2025-09-25 Start work on PS2 Helper
    [GPIO Helper.kicad_pcb, PS2 Helper.kicad_pcb, PS2 Helper.kicad_sch]
2025-09-26 Change ROM Cart to through-hole design
    [ROM Cart.kicad_pcb, ROM Cart.kicad_sch, ROM Cart.step]
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2025-09-27 Fix for ROM Cart Pro
    [ROM Cart Pro.kicad_pcb, ROM Cart Pro.kicad_sch]
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2025-09-28 Fix for Keypad LCD Helper silkscreen
    [Keyboard Helper.kicad_sch, Keypad LCD Helper.kicad_pcb, Keypad LCD Helper.kicad_sch]
2025-09-28 Fix DB Connectors
    [Joystick Helper.kicad_pcb, Joystick Helper.kicad_sch, Joystick Helper.step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]
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2025-10-01 Fix for Serial Card
    [Serial Card.kicad_pcb, Serial Card.kicad_sch, Serial Card.step]
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2025-10-03 Add CAD for GPIO Helper and Keypad Helper
    [Base.3mf, Base.stl, Bottom.stl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]
2025-10-03 Fix GPIO Helper button alignment
    [GPIO Helper.kicad_pcb, GPIO Helper.step]
2025-10-03 Move VGA Card mounting holes to align with pico9918
    [VGA Card.kicad_pcb, VGA Card.step]
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2025-10-06 Production fixes
    [Nano Card.kicad_pcb, PS2 Helper.kicad_pcb, ROM Cart.kicad_pcb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]
2025-10-06 Fixes for production
    [GPIO DB25 Helper.kicad_pcb, GPIO DB25 Helper.kicad_sch, Nano Card.kicad_pcb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]
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2025-10-13 Revise Sound Card to better use the VIA
    [6502.cfg, Sound Card.kicad_pcb, Sound Card.kicad_sch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]
2025-10-14 Re-arrange CAD folder and add new GPIO Helper CAD design
    [Backplane Pro.kicad_pcb, Backplane.kicad_pcb, Base.3mf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]
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2025-10-19 CPU Card minor silkscreen fix
    [CPU Card Pro.kicad_sch, CPU Card.kicad_pcb, CPU Card.kicad_sch]
2025-10-19 Flip pico9918 direction on VGA Card
    [VGA Card.kicad_pcb, VGA Card.step]
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2025-10-19 Fix title on CPU Card Pro sheets
    [CPU Card Pro.kicad_pcb, CPU Card Pro.kicad_sch]
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2025-10-26 Fix DB Emulator 1MHz delay
    [main.cpp]
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2025-10-29 Dev Board PCB fix
    [Dev Board.kicad_pcb]
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2025-11-06 Schematic fix
    [VERA Helper.kicad_sch]
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2025-11-13 Add PRAM and keyboard interrupts to DB Emulator
    [6502.cfg]
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2025-11-16 Fix Joystick Helper holes
    [Joystick Helper.kicad_pcb, Joystick Helper.step]
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2025-11-16 Fix some PCB positioning
    [GPIO Helper.kicad_pcb, GPIO Helper.step, Joystick Helper.kicad_pcb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]
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2025-11-17 Fixes for DB Emulator
    [main.cpp]
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2025-11-21 Redesign Clock Helper as through-hole
    [Clock Helper.kicad_pcb, Clock Helper.kicad_sch, Clock Helper.step]
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2025-11-26 Correct EXTMEM usage for DB Emulator RAMCard
    [main.cpp]
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2025-12-07 Shorten DB Emulator ASCII title
    [main.cpp]
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2025-12-08 Video Card Pro schematic fix
    [Video Card Pro.kicad_pcb, Video Card Pro.kicad_sch]
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2025-12-21 Purge some no longer needed designs
    [Dev Output Board.kicad_pcb, Dev Output Board.kicad_sch, Dev Output Board.step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]
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2026-01-11 Begin Output Board Redesign
    [Output Board.kicad_pcb, Output Board.kicad_sch]
2026-01-11 Redesign Sound Card
    [Sound Card.kicad_pcb, Sound Card.kicad_sch, Sound Card.step]
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2026-01-13 Update Sound Card to allow room for ZIF socket
    [Sound Card.kicad_pcb]
2026-01-14 Remove oscillator from CPU cards
    [CPU Card Pro.kicad_pcb, CPU Card Pro.kicad_sch, CPU Card Pro.step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]
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2026-01-31 Fix hole placement on Helpers
    [Clock Helper.kicad_pcb, Clock Helper.step, DB25 Helper.kicad_pcb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]
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2026-01-31 Fix GPIO Helper hole placement
    [GPIO Helper.kicad_pcb, GPIO Helper.step]
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2026-02-03 Fix CAD for KIM
    [Hanger Retainer.stl, The KIM.3mf]
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2026-03-03 Storage Card Pro schematic fix
    [Storage Card Pro.kicad_sch]
2026-03-03 Keypad Helper schematic fix
    [Keypad Helper.kicad_sch]
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2026-03-06 Change OSC and KBM capacitor values on Keypad Helper schematic
    [Keypad Helper.kicad_sch]
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2026-03-13 Begin Input Board redesign
    [Input Board.kicad_pcb, Input Board.kicad_sch, Keyboard Encoder Helper.kicad_sch]
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2026-03-30 DB Emulator fixes and optimizations
    [main.cpp]
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2026-04-06 Debug and fix KEH Controller firmware
    [fuses.cfg]
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2026-10-23 Check the RAM Card's decode from its netlist
    The ACE's bank latch was wrong twice while its gates looked right on
    paper. Tests/check-schematics.mjs takes the ACE checker's method to the
    COB: it builds the RAM Card's glue logic from the gates in its netlist,
    fits the card's jumpers, and drives all 262,144 bus states, comparing
    the RAM's /CE, /OE, /WE and A18 and the latch enable with the memory
    map, and checking the card drives the data bus only on a read of its
    own window.
    Rev 1.0 passes with both windows jumpered (IO 1 and IO 2), the only
    setting it supports. R1 and R2 pull the window selects to ground, so a
    window left without a jumper is selected at every address. Rev 1.0 is
    kept as it w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

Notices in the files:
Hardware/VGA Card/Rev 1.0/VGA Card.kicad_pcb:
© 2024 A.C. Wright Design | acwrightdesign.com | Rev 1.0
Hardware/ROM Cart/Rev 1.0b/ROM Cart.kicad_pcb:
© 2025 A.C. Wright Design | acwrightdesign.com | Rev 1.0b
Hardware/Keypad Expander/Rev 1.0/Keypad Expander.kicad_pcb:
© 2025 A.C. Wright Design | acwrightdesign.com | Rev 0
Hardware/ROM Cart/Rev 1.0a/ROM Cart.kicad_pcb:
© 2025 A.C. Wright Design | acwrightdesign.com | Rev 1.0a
